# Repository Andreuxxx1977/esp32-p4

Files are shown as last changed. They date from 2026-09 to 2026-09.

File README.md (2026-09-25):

# ESP32-P4 "Extreme Performance" development board




An open-hardware, actively cooled ESP32-P4 board for heavy multimedia work: a 2-lane MIPI camera,
a 2-lane MIPI display, USB 2.0 High-Speed, 10/100 Ethernet, UHS-I microSD, 32 MB flash and
32 MB PSRAM. It uses a 4-layer HDI PCB, a 3 A 3.3 V rail, and a heatsink + PWM fan over the SoC.

> **Status: designed, routed, Gerbers generated; not fabricated yet.**
> Parts, pinout, netlist, BOM, docs, the placed board and the **routed KiCad 10 board with its
> Gerbers** are finished and machine-checked (KiCad DRC: fully connected, 0 manufacturing or
> electrical errors). Some high-speed rules (differential-pair coupling and length matching) are
> **not** met yet, and the board has **not** been fabricated or bench-tested.
> Check [Project status](#project-status) before ordering anything.

| Top | Bottom |
|---|---|
| Top of the board, rendered by KiCad 10 | Bottom of the board, rendered by KiCad 10 |

*Rendered by KiCad 10 in CI from the committed board on every push to `main` (published to the
[`renders`](https://github.com/Andreuxxx1977/esp32-p4/tree/renders) branch), the routed board once it is on `main`. The
RJ45 and FPC connectors have no model in KiCad's 3D library, so they show as footprints. The ESP32-P4
body is a representative 10 x 10 mm QFN (Espressif ships no 3D model).*

> **Resumen en español:** placa de desarrollo abierta con ESP32-P4, refrigeración activa, cámara y
> pantalla MIPI, USB-HS, Ethernet y microSD. Todos los archivos se generan desde un único modelo en
> Python. La placa está enrutada (con un enrutador propio) y tiene Gerbers; aún no se ha fabricado. Libre de usar citando este proyecto como original (ver [Licencia](#license-free-to-use-just-credit-the-original-project)).

## How this project was made: about 95 % by an AI agent

This board is an experiment in AI-driven hardware design. **Roughly 95 % of the work in this repository
was done by [Claude Code](https://claude.com/claude-code), Anthropic's AI coding agent**, working
from a written brief. It did the component research and part selection, the ESP32-P4 pin-mux
analysis, the Python data model, the SKiDL netlist, the KiCad placement script, its own PCB router, the BOM,
the documentation, the tests and the CI that checks all of it.

The remaining ~5 % is human, by the repository owner: writing the brief, making the decisions the
agent asked for (licence, double-sided assembly, adding a display connector), and reviewing and
merging every change.

What that means for you:

- **Everything that can be checked by a machine is checked**, on every commit, with the real KiCad
  tools (see [Verification](#verification-what-github-checks-on-every-commit)). Every part number and
  pinout has a source link in [`docs/component_verification.md`](docs/component_verification.md).
- **What a machine can't prove is listed as open**: datasheet fine print marked UNVERIFIED, signal
  integrity of the high-speed links, thermal behaviour, and whether the board works on the bench.
  No experienced hardware engineer has reviewed it yet, and it has not been fabricated.
- Treat it as a well-documented starting point, not a proven product. Reviews and bring-up reports
  are very welcome.

> **En español:** alrededor del **95 % de este proyecto lo ha hecho Claude Code**, el agente de
> programación con IA de Anthropic, a partir de un enunciado escrito: investigación y elección de
> componentes, pinout, netlist, colocación en KiCad, un enrutador de PCB propio, BOM, documentación, tests y CI. El
> ~5 % restante es humano: el enunciado, las decisiones que el agente pidió y la revisión y fusión de
> cada cambio. Todo lo comprobable automáticamente se comprueba en cada commit; lo que no (integridad
> de señal, térmica, funcionamiento real) está marcado como pendiente. Aún no se ha fabricado.

---

## Download the files

Everything is in this repository. Download all of it as a ZIP with
**[Download ZIP](https://github.com/Andreuxxx1977/esp32-p4/archive/refs/heads/main.zip)**, or open any
file below and use GitHub's "Download raw file" button.

| What you want | File | Notes |
|---|---|---|
| **Gerbers for the fab** (PCBWay or any other) | [`hardware/output/fab/esp32p4_extreme_gerbers.zip`](hardware/output/fab/esp32p4_extreme_gerbers.zip) | Gerber X2 + Excellon drills + Gerber job file. The same folder has the IPC-356 netlist, the pick-and-place file and the BOM. **Read [its README](hardware/output/fab/README.md) first**: 4-layer HDI 1+2+1, filled and capped vias in pads, and the high-speed rules that are not met yet. |
| **Routed PCB: KiCad 10 project** (open the `.kicad_pro`) | [`hardware/output/routed/esp32p4_extreme.kicad_pro`](hardware/output/routed/esp32p4_extreme.kicad_pro) + [`esp32p4_extreme.kicad_pcb`](hardware/output/routed/esp32p4_extreme.kicad_pcb) + [`esp32p4_extreme.kicad_dru`](hardware/output/routed/esp32p4_extreme.kicad_dru) | The board the Gerbers come from, routed by the project's own router ([`tools/pcb_router.py`](tools/pcb_router.py)). KiCad's DRC report is next to it ([`esp32p4_extreme.drc.json`](hardware/output/routed/esp32p4_extreme.drc.json)). Download the three files into one folder. |
| **Placed PCB: KiCad 10 project** | [`hardware/output/esp32p4_extreme.kicad_pro`](hardware/output/esp32p4_extreme.kicad_pro) + [`esp32p4_extreme.kicad_pcb`](hardware/output/esp32p4_extreme.kicad_pcb) + [`esp32p4_extreme.kicad_dru`](hardware/output/esp32p4_extreme.kicad_dru) | All parts placed, no copper yet (ratsnest only): the input of the router. Stack-up, net classes, diff pairs, zones, thermal vias, keep-outs and custom DRC rules are set up. Opens in KiCad 9 and 10. |
| **Netlist** (import into KiCad) | [`hardware/output/esp32p4_extreme.net`](hardware/output/esp32p4_extreme.net) | 231 parts, 175 nets, all footprints assigned. In KiCad: *PCB Editor -> File -> Import -> Netlist*. |
| **Bill of materials for PCBWay** | [`hardware/output/bom_pcbway.csv`](hardware/output/bom_pcbway.csv) and [`docs/TASK4_bom_pcbway.md`](docs/TASK4_bom_pcbway.md) | Turnkey format: designator, qty, value, package, MPN, manufacturer, LCSC #. |
| **Pinout / architecture** | [`docs/TASK1_pinout.md`](docs/TASK1_pinout.md) | All 55 GPIOs, dedicated pads, and a proof that the peripherals don't collide. |
| **Mechanical & thermal plan** | [`docs/TASK2_mechanical_thermal.md`](docs/TASK2_mechanical_thermal.md) | Heatsink/fan stack, thermal numbers, hole and connector coordinates. |
| **Why each part was chosen** | [`docs/component_verification.md`](docs/component_verification.md) | Evidence (distributor/datasheet links) for every MPN and pinout. |
| **Connection list** (spreadsheet) | [`hardware/output/esp32p4_extreme_nets.csv`](hardware/output/esp32p4_extreme_nets.csv) | One row per pad: net, net class, reference, pad. |

## What's on the board

| Block | Implementation |
|---|---|
| SoC | **ESP32-P4NRW32X**: dual-core RISC-V up to 400 MHz, chip rev v3.x, 32 MB PSRAM in-package |
| Flash | 32 MB Quad-SPI NOR, Winbond **W25Q256JVEIQ** (3.3 V) |
| Power | USB-C VBUS (any of 3 ports, Schottky OR-ed) -> **TPS62130** 3 A buck -> 3.3 V; **TLV62569** buck for the SoC core rail (`VDD_HP`), enabled and trimmed by the SoC itself |
| USB 1 (J1) | Native USB 2.0 **High-Speed** OTG (480 Mbit/s) on the SoC's dedicated PHY, **TPD2EUSB30** 0.7 pF ESD |
| USB 2 (J2) | Debug console: **CP2102N** USB-UART with automatic download/reset (DTR/RTS) |
| USB 3 (J3) | Native **USB-Serial-JTAG**: JTAG debugging + flashing with no drivers or setup |
| Ethernet | 10/100 RMII PHY **LAN8720A** + HanRun **HR911105A** RJ45 with magnetics |
| Camera | 2-lane MIPI CSI-2, 22-pin 0.5 mm FPC (**Raspberry Pi 5 pinout**; same Amphenol connector as the Pi) |
| Display | 2-lane MIPI DSI, same 22-pin FPC (J_DSI) + 5 V backlight JST-SH (J8), **plus** a 2x8 2.54 mm header (J9) for common SPI TFTs (ST7789 / ILI9341 / ST7735, with or without touch) |
| Storage | microSD on the UHS-I-capable SDMMC slot 0, 4-bit, 1.8/3.3 V switching, 0.5 pF TVS arrays |
| Cooling | 25 x 25 mm heatsink on the SoC, clamped through **4x M2.5 holes at (+/-15, +/-15) mm**; 5 V 4-wire PWM fan header; 7x7 filled thermal-via array under the SoC |
| Expansion | 2x12 2.54 mm header (J6): 20 GPIOs, LP-UART, ADC, pad-JTAG, I2C, 3V3/5V |
| Board | 110 x 80 mm, 4-layer HDI (1+2+1), 1.6 mm, controlled impedance 50 / 90 / 100 ohm |

```mermaid
flowchart LR
    subgraph Power
        VB["USB-C J1/J2/J3 VBUS"] --> OR["Schottky OR + PTC"] --> VSYS["VSYS 5 V"]
        VSYS --> BUCK["TPS62130 3 A"] --> V33["+3V3 plane"]
        V33 --> HP["TLV62569 VDD_HP"]
        VSYS --> FAN["Fan 5 V switch"]
    end
    subgraph SoC["ESP32-P4NRW32X (32 MB PSRAM)"]
        CORE["HP cores + peripherals"]
    end
    HP -. "EN_DCDC / FB_DCDC" .- CORE
    V33 --> CORE
    CORE -- "Quad SPI" --> FLASH["W25Q256 32 MB"]
    CORE -- "USB 2.0 HS" --> J1["USB-C J1"]
    CORE -- "UART0" --> CP["CP2102N"] --> J2["USB-C J2 debug"]
    CORE -- "USB-Serial-JTAG" --> J3["USB-C J3 JTAG"]
    CORE -- "RMII" --> PHY["LAN8720A"] --> RJ["RJ45"]
    CORE -- "MIPI CSI x2" --> CAM["Camera FPC"]
    CORE -- "MIPI DSI x2" --> DSI["Display FPC"]
    CORE -- "SPI + I2C" --> TFT["SPI TFT header J9"]
    CORE -- "SDMMC 4-bit" --> SD["microSD"]
    CORE -- "PWM / TACH" --> FANH["4-pin fan header"]
```

## Project status

| Step | State |
|---|---|
| Architecture, GPIO map, zero-conflict check | Done: [`docs/TASK1_pinout.md`](docs/TASK1_pinout.md) |
| Part selection with sourcing evidence | Done: [`docs/component_verification.md`](docs/component_verification.md) |
| Netlist (SKiDL), ERC 0 errors / 0 warnings, independent verification | Done |
| Every pad cross-checked against the real KiCad footprints | Done |
| PCBWay BOM | Done: 63 fitted lines, 219 placements (215 SMD + 4 THT); pick-and-place file generated by CI |
| Mechanical/thermal plan | Done: [`docs/TASK2_mechanical_thermal.md`](docs/TASK2_mechanical_thermal.md) |
| Component placement: pcbnew script + downloadable KiCad 10 project | Done: 234 footprints, KiCad 10 DRC 0 errors, **double-sided** (15 x 0402 decoupling under the SoC on the bottom); every SoC pad keeps a routable escape channel |
| Routing (own router), DRC in KiCad, Gerbers | Done as a prototype: every net routed on 4 layers, KiCad DRC with 0 unconnected items and 0 manufacturing/electrical errors, Gerbers + drills + IPC-356 + pick-and-place in [`hardware/output/fab/`](hardware/output/fab/) |
| Signal integrity of the routing | **Open**: several differential pairs are not coupled over their whole length and miss the 10 mil skew target; the list is in [the fab README](hardware/output/fab/README.md). Needs review before ordering |
| Fabrication, bring-up, firmware | Not started |

## Verification: what GitHub checks on every commit

Every push and pull request runs [`Design checks`](https://github.com/Andreuxxx1977/esp32-p4/actions/workflows/ci.yml)
(badge at the top). Nothing is merged unless it passes. The results are public in the **Actions** tab.

| CI job | What it proves |
|---|---|
| **Spec, netlist, docs and tests** | The design data passes its rules: no GPIO used twice, IO_MUX-only signals on legal pads, boot straps safe, heatsink/standoff keep-outs respected. The committed netlist matches the design pad by pad. A fresh SKiDL netlist passes ERC with 0 errors and 0 warnings. The docs and BOM are not stale. The 129 unit tests pass. |
| **Pads exist in the real KiCad footprints** | Every connected pad exists in the official KiCad **10.0.6** footprint library. |
| **KiCad 10 (pcbnew API, DRC, render, centroid)** | Runs the real KiCad 10 in its [official Docker image](https://hub.docker.com/r/kicad/kicad). It rebuilds the board from scratch with the pcbnew placement script. Both that board and the committed placed one must pass KiCad's DRC with 0 errors (unconnected items are expected there: they are not routed). It also renders the board in 3D with the parts' models and exports the PCBWay pick-and-place file. Download these under *Artifacts* on the run page. |
| **Routed board (DRC, same design as placed, Gerbers reproducible)** | The committed routed board has exactly the placed board's footprints, positions, pad nets and zones, plus copper. KiCad's DRC finds 0 unconnected items and 0 manufacturing or electrical errors; the high-speed rules it misses are listed, not hidden. A fresh export of the routed board gives the committed Gerbers, drills, IPC-356 and pick-and-place file line by line (time stamps aside). A separate manual workflow ([`route.yml`](.github/workflows/route.yml)) re-routes the board from the placed one. |

Open items to confirm against datasheets before ordering are listed at the end of
[`docs/component_verification.md`](docs/component_verification.md) (items marked UNVERIFIED).

## How the repository works

**One Python file describes the whole board**, and everything else is generated from it:

```
hardware/lib/board_spec.py       <- the design: parts, MPNs, footprints, every connection, placement
hardware/lib/esp32p4_pinout.py   <- ESP32-P4 pad table and IO_MUX rules (from Espressif sources)
hardware/lib/impedance.py        <- stack-up and 50/90/100 ohm trace geometry
        |
        +--> hardware/skidl/esp32p4_extreme_netlist.py  -> hardware/output/esp32p4_extreme.net (+ nets CSV, ERC log)
        +--> hardware/pcbnew/                            -> hardware/output/esp32p4_extreme.kicad_pro/.kicad_pcb/.kicad_dru
        +--> tools/gen_docs.py                           -> docs/TASK1_*.md, TASK2_*.md, TASK4_*.md, bom_pcbway.csv
        +--> hardware/pcbnew/preroute.py + tools/pcb_router.py -> hardware/output/routed/ (routed board)
        +--> tools/export_fab.py                         -> hardware/output/fab/ (Gerbers, drills, IPC-356, pick-and-place)
        +--> tests/                                      -> 129 automated tests
```

So the pinout table, the netlist and the BOM can never disagree. To change the board, edit
`board_spec.py` and regenerate (see [CONTRIBUTING.md](CONTRIBUTING.md)).

### Run the checks yourself

```bash
pip install --use-pep517 -r requirements.txt
python -m hardware.lib.board_spec                  # validate the design data
python -m hardware.skidl.esp32p4_extreme_netlist   # netlist + ERC  -> hardware/output/
python -m hardware.skidl.verify_netlist            # netlist == spec, pad by pad
python -m hardware.skidl.check_footprints          # pads exist in the real KiCad footprints (needs internet)
python -m tools.gen_docs                           # regenerate docs + BOM (--check to only verify)
python -m hardware.pcbnew.write_kicad_pcb          # regenerate the KiCad project (no KiCad needed)
python -m pytest -q
# with KiCad 10 installed (pcbnew Python), the same board through KiCad's own API:
python3 hardware/pcbnew/esp32p4_extreme_place.py --fp-dir /usr/share/kicad/footprints --out /tmp/board.kicad_pcb
# route the board again and export the Gerbers: CONTRIBUTING.md, "Routing and fabrication files"
```

GitHub Actions runs the same steps on every push and pull request (see [`.github/workflows/ci.yml`](.github/workflows/ci.yml)).
In the KiCad board, the design origin (the SoC centre, U1 = (0, 0)) is set as the grid and drill/place
origin. The board itself sits in the middle of the drawing sheet. To read design coordinates, set KiCad's
coordinate display to the grid origin. The pick-and-place export (`--use-drill-file-origin`) reports
U1 at exactly (0, 0).
The project targets **KiCad 10** and its standard libraries (checked against tag 10.0.6). KiCad 9.0.x
names two shield pads differently: USB-C `S1` and microSD `11` instead of `SH`. The netlist opens there
too, but those shield pads won't connect if you re-import footprints from a 9.0 library. The SoC
footprint comes from [Espressif's KiCad library](https://github.com/espressif/kicad-libraries)
(`PCM_Espressif:ESP32-P4`).

## Design decisions that differ from a "typical" P4 board

All of these come from Espressif's primary sources: the ESP-IDF `soc_caps.h`/`*_pins.h`/`emac_periph.c`
files, the ESP32-P4 hardware design guidelines and Espressif's KiCad library.

| Asked for | Built | Why |
|---|---|---|
| ESP32-P4NR32 | **ESP32-P4NRW32X** (rev v3.x, 32 MB PSRAM) | The orderable 32 MB-PSRAM part. Espressif marks rev v1.x as not recommended for new designs. |
| 32 MB **Octal** flash (MX25UM25645G) | 32 MB **Quad** W25Q256JVEIQ (3.3 V) | The P4 flash interface is SPI/Dual/Quad only, up to 64 MB. ESP-IDF has no octal-flash capability for the P4. MX25UM is also 1.8 V, while the P4 flash rail defaults to 3.3 V. |
| MP2315 / SY8113B buck | **TPS62130** (3-17 V, 3 A, 100 % duty) | Works from Schottky-OR-ed VBUS (~4.4-4.6 V), below the MP2315's 4.5 V minimum. The exposed pad is also better thermally at 3 A. |
| (not asked) | **TLV62569** VDD_HP DCDC | The P4 core rail must come from an external DCDC that the SoC enables and trims itself. TLV62569 is on Espressif's verified list. |
| RTL8201F | **LAN8720A** | Pinout verified from the official KiCad library, ESP-IDF `lan87xx` driver. Its REF_CLK-out mode feeds the P4's input-only RMII clock. |
| CH340K / CP2102N "UART/JTAG" | **CP2102N** (UART) **plus** a 3rd USB-C on the P4's native USB-Serial-JTAG | Neither chip can do JTAG. The P4's built-in USB-Serial-JTAG gives JTAG with no setup. |
| USBLC6-2SC6 on USB-HS | **TPD2EUSB30** on J1 (USBLC6 kept on J2/J3) | USBLC6 is 3.5 pF max. Espressif requires at most 1 pF on the High-Speed lines. |
| AO3400A fan MOSFET | AO3400A as **open-drain PWM** + AO3401A high-side switch | A 4-wire fan needs constant power and an open-drain PWM input (Intel spec). The fan runs at 100 % if the firmware hangs, and can be switched off completely. |

## Contributing

Issues and pull requests are welcome. Reviews of the schematic choices and of the routing (above all the high-speed pairs) and bring-up
reports are the most useful right now. Read [CONTRIBUTING.md](CONTRIBUTING.md) first: in short,
edit `hardware/lib/board_spec.py`, regenerate, and commit the generated files with it.

## License: free to use, just credit the original project

Copyright (c) 2026 Andreuxxx1977. Licensed under the **CERN Open Hardware Licence v2 - Permissive**
(SPDX: `CERN-OHL-P-2.0`). The full text is in [`LICENSE`](LICENSE).

In plain words: **anyone is free to use, copy, modify, fabricate, sell and build on this design,
commercially or not.** The only thing asked in return is that you **credit this project as the
original**, for example with a link in your README, documentation or product page:

> Based on the ESP32-P4 Extreme Performance board by Andreuxxx1977 -
> https://github.com/Andreuxxx1977/esp32-p4

You don't have to publish your own changes, and you don't have to use the same licence for your
derivative. That attribution line is the licence's "Notice", so keep it (CERN-OHL-P v2 section 3.2).
If you modify the design, add a short note saying so (section 3.3).

Why so permissive? About 95 % of this design was produced by an AI agent (Claude Code, see
[How this project was made](#how-this-project-was-made-about-95--by-an-ai-agent)). There's little personal
merit to protect, so the goal is simply that it's useful to as many people as possible.

**Libre de usar:** cualquiera puede usar, modificar, fabricar y vender este diseño. Lo único que se pide
es mencionar que el proyecto original es https://github.com/Andreuxxx1977/esp32-p4.

This source is distributed WITHOUT ANY EXPRESS OR IMPLIED WARRANTY, INCLUDING OF MERCHANTABILITY,
SATISFACTORY QUALITY AND FITNESS FOR A PARTICULAR PURPOSE. Please see the CERN-OHL-P v2 for applicable
conditions. The board has not been fabricated or bench-tested yet. Treat it as a reviewed starting point
and check it against the datasheets before ordering (see `docs/component_verification.md`).

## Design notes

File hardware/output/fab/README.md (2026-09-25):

# ESP32-P4 Extreme -- fabrication package

> **Prototype files, routed by the project's own router (`tools/pcb_router.py`).**
> **Not fabricated or bench-tested yet.**
> The copper is fully connected and passes KiCad's DRC for manufacturing and electrical
> rules (0 errors).
> Some high-speed rules listed at the end are **not** met (coupling, gap or length
> matching of some differential pairs / length groups). Review those nets before
> ordering: they can limit USB 2.0 High-Speed, MIPI CSI/DSI or Ethernet margins.

## Files

- `esp32p4_extreme_gerbers.zip`: Gerber X2 (Protel extensions) + Excellon drills (PTH and NPTH separate) + drill maps + Gerber job file. Upload this to PCBWay.
- `esp32p4_extreme.ipc`: IPC-D-356 netlist for the fab's electrical test.
- `pick_and_place.csv`: centroids, both sides, origin = SoC centre (same as the Gerbers).
- `bom_pcbway.csv`: turnkey BOM (MPN, manufacturer, LCSC).
- Source: `hardware/output/routed/esp32p4_extreme.kicad_pcb` (KiCad 10).

## Board

- 110 x 80 mm, 1.6 mm, 4 layers, 234 footprints, 3223 track segments.
- Stack-up (1+2+1 HDI, controlled impedance 50 / 90 / 100 ohm, ask PCBWay to confirm widths):

  | Layer | Thickness | Material | Function |
  |---|---|---|---|
  | F.Cu | 0.035 mm | Cu 0.5 oz + plating | Signal_Top (HS routing, refs L2 GND) |
  | PP1 | 0.1 mm | Prepreg 1080 (laser-drillable) | Er 4 |
  | In1.Cu | 0.035 mm | Cu 1 oz | GND (solid, un-split reference plane) |
  | Core | 1.26 mm | FR-4 core, Tg170 | Er 4.4 |
  | In2.Cu | 0.035 mm | Cu 1 oz | VCC_3V3 plane (+VDD_HP island under U1) |
  | PP2 | 0.1 mm | Prepreg 1080 (laser-drillable) | Er 4 |
  | B.Cu | 0.035 mm | Cu 0.5 oz + plating | Signal_Bottom (low-speed, heat-spreader pour) |

- Vias: 230 x micro 0.3/0.1 mm, 688 x through 0.45/0.2 mm, 49 x through 0.6/0.3 mm.
  Laser microvias L1-L2 (to the GND plane) and L4-L3 (to the power planes) need an HDI
  1+2+1 build. Every via inside a pad (the EPAD array and the plane vias of the 0402 pads)
  must be **filled and capped** (IPC-4761 Type VII, "via in pad" / VIPPO).
- Minimum track 0.1 mm (0.09 mm only in the SoC fan-out, inside U1's courtyard), minimum clearance 0.09 mm there, 0.10 mm elsewhere.
- Surface finish ENIG (0.35 mm-pitch QFN), green mask, white silkscreen.

## Design-rule check (KiCad 10)

- Unconnected items: 0; manufacturing/electrical errors: 0.
- High-speed rules **not met**:

  - diff_pair_gap_out_of_range: CAM_D1_N, CAM_D1_P (2x)
  - diff_pair_gap_out_of_range: CSI_D1_N, CSI_D1_P (6x)
  - diff_pair_gap_out_of_range: DISP_CLK_N, DISP_CLK_P (2x)
  - diff_pair_gap_out_of_range: DISP_D0_N, DISP_D0_P (10x)
  - diff_pair_gap_out_of_range: DISP_D1_N, DISP_D1_P (22x)
  - diff_pair_gap_out_of_range: ETH_TX_N, ETH_TX_P (10x)
  - diff_pair_gap_out_of_range: USB1_D_N, USB1_D_P (44x)
  - diff_pair_gap_out_of_range: USB2_D_N, USB2_D_P (28x)
  - diff_pair_gap_out_of_range: USB3_D_N, USB3_D_P (71x)
  - diff_pair_gap_out_of_range: USBHS_D_N, USBHS_D_P (4x)
  - diff_pair_uncoupled_length_too_long: CAM_CLK_N, CAM_CLK_P (1x)
  - diff_pair_uncoupled_length_too_long: CAM_D0_N, CAM_D0_P (1x)
  - diff_pair_uncoupled_length_too_long: CAM_D1_N, CAM_D1_P (1x)
  - diff_pair_uncoupled_length_too_long: CSI_CLK_N, CSI_CLK_P (1x)
  - diff_pair_uncoupled_length_too_long: CSI_D0_N, CSI_D0_P (1x)
  - diff_pair_uncoupled_length_too_long: CSI_D1_N, CSI_D1_P (1x)
  - diff_pair_uncoupled_length_too_long: DISP_CLK_N, DISP_CLK_P (1x)
  - diff_pair_uncoupled_length_too_long: DISP_D0_N, DISP_D0_P (1x)
  - diff_pair_uncoupled_length_too_long: DISP_D1_N, DISP_D1_P (1x)
  - diff_pair_uncoupled_length_too_long: DSI_CLK_N, DSI_CLK_P (1x)
  - diff_pair_uncoupled_length_too_long: DSI_D0_N, DSI_D0_P (1x)
  - diff_pair_uncoupled_length_too_long: DSI_D1_N, DSI_D1_P (1x)
  - diff_pair_uncoupled_length_too_long: ETH_RX_N, ETH_RX_P (1x)
  - diff_pair_uncoupled_length_too_long: ETH_TX_N, ETH_TX_P (1x)
  - diff_pair_uncoupled_length_too_long: USB1_D_N, USB1_D_P (1x)
  - diff_pair_uncoupled_length_too_long: USB2_D_N, USB2_D_P (1x)
  - diff_pair_uncoupled_length_too_long: USB3_D_N, USB3_D_P (1x)
  - diff_pair_uncoupled_length_too_long: USBHS_D_N, USBHS_D_P (1x)
  - skew_out_of_range: CAM_CLK_N (1x)
  - skew_out_of_range: CAM_D0_N (1x)
  - skew_out_of_range: CAM_D0_P (1x)
  - skew_out_of_range: CAM_D1_N (1x)
  - skew_out_of_range: CAM_D1_P (1x)
  - skew_out_of_range: CSI_CLK_N (1x)
  - skew_out_of_range: CSI_CLK_P (1x)
  - skew_out_of_range: CSI_D0_N (1x)
  - skew_out_of_range: CSI_D0_P (1x)
  - skew_out_of_range: CSI_D1_P (1x)
  - skew_out_of_range: DISP_CLK_N (1x)
  - skew_out_of_range: DISP_CLK_P (1x)
  - skew_out_of_range: DISP_D0_N (1x)
  - skew_out_of_range: DISP_D1_N (1x)
  - skew_out_of_range: DISP_D1_P (1x)
  - skew_out_of_range: DSI_CLK_P (1x)
  - skew_out_of_range: DSI_D0_N (1x)
  - skew_out_of_range: DSI_D0_P (1x)
  - skew_out_of_range: DSI_D1_N (1x)
  - skew_out_of_range: DSI_D1_P (1x)
  - skew_out_of_range: ETH_RX_N (1x)
  - skew_out_of_range: ETH_TX_P (1x)
  - skew_out_of_range: SD_CLK_C (1x)
  - skew_out_of_range: SD_CMD (1x)
  - skew_out_of_range: SD_CMD_C (1x)
  - skew_out_of_range: SD_D0 (1x)
  - skew_out_of_range: SD_D0_C (1x)
  - skew_out_of_range: SD_D1 (1x)
  - skew_out_of_range: SD_D1_C (1x)
  - skew_out_of_range: SD_D2 (1x)
  - skew_out_of_range: SD_D3 (1x)
  - skew_out_of_range: USB2_D_P (1x)
  - skew_out_of_range: USB3_D_P (1x)
  - skew_out_of_range: USBHS_D_N (1x)

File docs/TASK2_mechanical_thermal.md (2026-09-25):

<!-- GENERATED by tools/gen_docs.py from hardware/lib/*.py -- do not edit by hand. Regenerate: python3 -m tools.gen_docs -->

# TASK 2: Mechanical & thermal strategy

All coordinates, dimensions and part data are read from `hardware/lib/board_spec.py` at generation time. Thermal values are estimates with every assumption listed next to its result.

## 1. Heat paths

| Path | Stack | Key numbers (from the spec) |
| --- | --- | --- |
| (a) Top | SoC mould top -> 0.1 mm phase-change pad (e.g. Laird Tpcm 580) -- flush on SoC lid -> 25 x 25 x 10 mm heatsink (Al 6063-T5, black anodised) -> 5 V PWM fan (impinging, radial exhaust over the board) | SoC seated height 0.90 mm; tallest part allowed in the keep-out 0.60 mm (rule) / 0.55 mm (actual, 86 x 0402 passives around U1) -> air gap under the heatsink base >= 0.35 mm (0.30 mm by rule), 0.45 mm with the uncompressed TIM |
| (b) Bottom | EPAD 7.5 mm -> 7x7 vias 0.30/0.60 mm @ 1.0 mm (VIPPO) -> L2 GND plane + 14 x 14 mm B.Cu spreader (6.6 x 6.6 mm exposed window) -> optional bottom gap pad / chassis | array extent 6.6 mm inside the 7.5 mm EPAD; fill: IPC-4761 Type VII (resin-filled + copper-capped, VIPPO) |

The heatsink sits flush on the SoC lid: nothing inside the 25 x 25 mm keep-out is taller than 0.55 mm, so the base clears every 0402 by >= 0.35 mm. Black anodising is not a guaranteed insulator -- the gap is the insulation, and the 4-point spring clamp keeps the base parallel to the board.

Assembly is double-sided: 15 decoupling caps (C10, C11, C13, C14, C20, C21, C23, C25, C26, C27, C28, C29, C31, C32, C33) sit on the bottom under the SoC's pad ring, outside the thermal-via field. So only the via field is left mask-free (6.6 x 6.6 mm, `BOTTOM_THERMAL_WINDOW_MM`); the rest of the 14 x 14 mm spreader copper (`BOTTOM_SPREADER_MM`) is under solder mask. A bottom gap pad or bracket must clear those 0402s (<= 0.55 mm) or be cut to the window.

### 1.1 Via-array thermal resistance

```text
barrel area  A = pi/4 * (d^2 - (d - 2t)^2) = pi/4 * (0.300^2 - 0.250^2) = 0.02160 mm^2
one via      R = L / (k * A) = 1.60e-3 m / (385 W/m.K * 0.02160e-6 m^2) = 192.4 K/W
array        R = 192.4 / 49 = 3.93 K/W   (plating t = 25 um, L = board thickness)
L1 -> L2 only (0.135 mm of the 1.60 mm): 0.33 K/W  (heat reaches the GND plane almost for free)
solid-copper-filled vias would give 1.20 K/W (resin fill k ~0.3-1 W/m.K adds nothing)
```

Constriction in the planes, voids under the EPAD and the resin fill are ignored, so treat 3.9 K/W as the via contribution only.

EPAD tile alignment (computed): 25 of 49 via pads fall fully inside one of the 2.1 mm EPAD tiles (2.7 mm pitch); the other 24 straddle the 0.6 mm inter-tile gaps. If the footprint copper is tiled (not one solid pad), either merge the F.Cu to a solid 7.5 mm pad (paste stays tiled) or move the array onto the tile pitch.

## 2. Power estimate

Espressif does not publish a theta-JC, theta-JB or maximum package dissipation for the ESP32-P4 in the documents used for this design (datasheet, hardware design guidelines, KiCad library). Every power and package number below is an **engineering estimate** to be replaced by a measurement on the first build (VBUS power with peripherals off vs. full load, IR camera / thermocouple on the lid).

| Contributor | Low (W) | High (W) | Assumption |
| --- | ---: | ---: | --- |
| VDD_HP domain: 2x RISC-V @ 400 MHz, L2MEM, ISP / H.264 / PPA / 2D-DMA | 0.35 | 0.90 | assumed 0.3-0.75 A on the VDD_HP rail |
| In-package 32 MB PSRAM + flash IO via on-chip LDOs (LDO drop dissipated in the package) | 0.10 | 0.35 | assumed 30-100 mA from 3.3 V |
| MIPI DSI + CSI D-PHY, USB 2.0 HS PHY, analog, IO ring | 0.10 | 0.30 | assumed 30-90 mA from 3.3 V |
| **SoC total (estimate)** | **0.55** | **1.55** |  |
| Thermal design point |  | **2.0** | estimate + margin for unknowns |
| Hard ceiling (not expected) |  | 3.05 | U4 TLV62569 rated 2.0 A x 1.20 V = 2.40 W on VDD_HP + 0.65 W 3.3 V-side high estimate |

## 3. Thermal network (estimate)

| Element | Value | Basis |
| --- | ---: | --- |
| theta-JC top (die -> mould top) | 12.0 K/W | estimate for a 10 x 10 mm QFN mould cap |
| theta-JC bottom (die -> EPAD) | 2.0 K/W | estimate (exposed-pad QFN) |
| TIM | 0.33 K/W | 0.10 mm / (3.0 W/m.K x 100 mm^2 lid) |
| EPAD solder | 0.026 K/W | 50 um SAC, 60% coverage |
| Via array | 3.93 K/W | section 1.1 |
| Heatsink theta-SA, fan | 6.7 K/W | 6x6 pins 2.0 mm, 8 mm tall -> A = 2929 mm^2; h = 60 W/m^2.K, eta = 0.85 |
| Heatsink theta-SA, natural | 29.9 K/W | h = 12 W/m^2.K, eta = 0.95 |
| Board -> air, fan exhaust | 10.2 K/W | 2 x board area, 30% effective, top h = 25 |
| Board -> air, natural | 15.8 K/W | h = 12 W/m^2.K |
| Optional gap pad to chassis | 7.65 K/W + chassis | 1.0 mm, 3.0 W/m.K on the 6.6 mm exposed window |

| Scenario | R top (K/W) | R bottom (K/W) | R j-a (K/W) | Share via EPAD | dT j-a @ 1.55 W | dT j-a @ 2.0 W | Tj @ 2.0 W, Ta 40 C | dT across vias @ 2.0 W |
| --- | ---: | ---: | ---: | ---: | ---: | ---: | ---: | ---: |
| Heatsink + fan (normal) | 19.0 | 16.2 | 8.7 | 54% | 13.6 K | 17.5 K | 57 C | 4.2 K |
| Heatsink, fan stopped / zero-RPM | 42.3 | 21.7 | 14.4 | 66% | 22.3 K | 28.7 K | 69 C | 5.2 K |
| No heatsink, natural convection | 845.3 | 21.7 | 21.2 | 97% | 32.8 K | 42.4 K | 82 C | 7.7 K |

Reading: with only the via array and the board (no heatsink) the SoC would run roughly 42 K above ambient at the 2.0 W design point; the heatsink + fan cut that to ~17 K and the via array still carries about 54% of the heat. The temperature drop across the via array itself is only ~4.2 K. With theta-JC(top) at a pessimistic 20 K/W the fan-on R j-a becomes 10.1 K/W.

### 3.1 Heatsink and fan selection

| Choice | Rationale |
| --- | --- |
| Base = keep-out | 25 x 25 mm base covers the 25 x 25 mm keep-out exactly; everything under it is <= 0.55 mm |
| Height | 10 mm keeps the fan top low; the fan shadow is the fan footprint (up to 30 mm square, see section 6) |
| Pin fins | an impinging fan exhausts radially only through pin (or cross-cut) fins; plate fins would dump all flow along two sides |
| Fan | 25 x 25 x 10 mm or 30 x 30 x 7 mm, 5 V, 4-wire PWM, screwed to fin top; 5 V from VSYS through the high-side switch; typically 0.3-0.6 W for this size (check the fan datasheet) |
| Clamp | 4 x M2.5 spring-loaded screws through H1-H4 into a 30 x 30 mm X-bracket; plated holes tied to GND bond the heatsink to ground |
| Margin | theta-SA falls from ~30 to ~7 K/W with the fan (estimate; use the vendor theta-vs-airflow curve for the final part) |

## 4. Mechanical coordinates

Design origin = U1 body centre; KiCad axes (+X right, +Y down); mm. Part coordinates are the footprint origin (for pin headers that is pin 1, not the body centre).

| Feature | Coordinates | Size / notes |
| --- | --- | --- |
| Board outline | (-55.0, -40.0) .. (55.0, 40.0) | 110 x 80 mm, R3.0 corners |
| Heatsink keep-out | (-12.5, -12.5), (12.5, -12.5), (-12.5, 12.5), (12.5, 12.5) | 25 x 25 mm, max part height 0.60 mm |
| H1 (heatsink, M2.5) | (-15.0, -15.0) | keep-out radius 3.5 mm |
| H2 (heatsink, M2.5) | (15.0, -15.0) | keep-out radius 3.5 mm |
| H3 (heatsink, M2.5) | (-15.0, 15.0) | keep-out radius 3.5 mm |
| H4 (heatsink, M2.5) | (15.0, 15.0) | keep-out radius 3.5 mm |
| H5 (board, M3) | (-51.0, -36.0) | Board mounting hole (GND) |
| H6 (board, M3) | (51.0, -36.0) | Board mounting hole (GND) |
| H7 (board, M3) | (-51.0, 36.0) | Board mounting hole (GND) |
| H8 (board, M3) | (51.0, 36.0) | Board mounting hole (GND) |
| FID1 | (-52.1, 31.4) | fiducial |
| FID2 | (52.0, 28.0) | fiducial |
| FID3 | (47.0, -24.0) | fiducial |

### 4.1 Every absolutely placed part

| Ref | Value | x, y | Rot | Height (mm) | Clearance to keep-out (mm) | Nearest M2.5 hole (mm) | Board-edge dist (mm) | Hole check |
| --- | --- | ---: | ---: | ---: | ---: | --- | --- | --- |
| C55 | 47uF | (-14.5, -8.0) | 90 | 1.45 | 2.0 | H1 7.0 | 32.0 | OK |
| C56 | 47uF | (14.5, 8.0) | 90 | 1.45 | 2.0 | H4 7.0 | 32.0 | OK |
| D1 | PMEG4050EP | (22.0, 28.5) | 0 | 1.10 | 18.6 | H4 15.2 | 11.5 | OK |
| D2 | PMEG4050EP | (-42.0, 25.0) | 0 | 1.10 | 32.0 | H3 28.8 | 13.0 | OK |
| D3 | PMEG4050EP | (-42.0, 11.0) | 0 | 1.10 | 29.5 | H3 27.3 | 13.0 | OK |
| D4 | Green | (-43.0, -30.0) | 0 | 0.80 | 35.2 | H1 31.8 | 10.0 | OK |
| D5 | Red | (-43.0, -27.0) | 0 | 0.80 | 33.8 | H1 30.5 | 12.0 | OK |
| F1 | PTC 2.5A | (-34.0, 27.0) | 0 | 1.10 | 25.9 | H3 22.5 | 13.0 | OK |
| J1 | USB-C | (22.0, 36.0) | 0 | 3.31 | 25.3 | H4 22.1 | bottom: 4.0 | OK |
| J2 | USB-C | (-51.0, 22.0) | 0 | 3.31 | 39.7 | H3 36.7 | left: 4.0 | OK |
| J3 | USB-C | (-51.0, 8.0) | 0 | 3.31 | 38.5 | H3 36.7 | left: 4.0 | OK |
| J4 | RJ45 MagJack | (37.2, 3.0) | 0 | 13.30 | 24.7 | H4 25.3 | right: 17.8 | OK |
| J5 | microSD | (6.0, -31.0) | 0 | 1.98 | 18.5 | H2 18.4 | top: 9.0 | OK |
| J6 | 2x12 header | (-50.5, -27.1) | 0 | 8.50 | 40.7 | H1 37.5 | 4.5 | OK |
| J7 | Fan 4P | (-30.0, -30.0) | 0 | 11.40 | 24.7 | H1 21.2 | 10.0 | OK |
| J8 | JST-SH 2P | (-28.0, 36.5) | 0 | 2.95 | 28.6 | H3 25.1 | bottom: 3.5 | OK |
| J9 | 2x8 header | (24.0, -35.0) | 90 | 8.50 | 25.3 | H2 21.9 | 5.0 | OK |
| J_CAM | FPC 22P 0.5mm | (6.0, 35.0) | 0 | 2.00 | 22.5 | H4 21.9 | bottom: 5.0 | OK |
| J_DSI | FPC 22P 0.5mm | (-14.0, 35.0) | 0 | 2.00 | 22.5 | H3 20.0 | bottom: 5.0 | OK |
| L1 | 2.2uH | (-27.0, 20.0) | 0 | 3.10 | 16.3 | H3 13.0 | 20.0 | OK |
| L2 | 2.2uH | (20.6, -8.5) | 0 | 1.20 | 8.1 | H2 8.5 | 31.5 | OK |
| SW1 | Tactile | (-40.0, -35.0) | 0 | 2.50 | 35.5 | H1 32.0 | 5.0 | OK |
| SW2 | Tactile | (-33.0, -35.1) | 0 | 2.50 | 30.5 | H1 27.0 | 4.9 | OK |
| U2 | W25Q256JV 32MB | (-20.0, 5.0) | 90 | 0.80 | 7.5 | H3 11.2 | 35.0 | OK |
| U3 | TPS62130 | (-34.0, 18.0) | 0 | 1.00 | 22.2 | H3 19.2 | 21.0 | OK |
| U4 | TLV62569 | (16.5, -7.5) | 0 | 1.45 | 4.0 | H2 7.6 | 32.5 | OK |
| U5 | LAN8720A | (22.0, 3.0) | 0 | 0.90 | 9.5 | H4 13.9 | 33.0 | OK |
| U6 | CP2102N | (-39.5, 19.0) | 0 | 0.90 | 27.8 | H3 24.9 | 15.5 | OK |
| Y1 | 40MHz 10ppm | (-3.5, -15.0) | 0 | 0.50 | 2.5 | H1 11.5 | 25.0 | OK |
| Y2 | 25MHz | (22.0, 9.5) | 0 | 0.80 | 9.5 | H4 8.9 | 30.5 | OK |

## 5. Collision check (M2.5 heatsink holes)

Flag thresholds: a part origin closer than 3.5 mm (`HEATSINK_HOLE_KEEPOUT_R`) to a hole centre is a **FAIL**; a high-speed corridor closer than 4.5 mm (keep-out + 1 mm) is flagged. HS corridors are approximated as the straight segment from the centroid of the SoC pad group (`pad_position`) to the connector / device placement.

### 5.1 Summary per hole

| Hole | x, y | (i) to keep-out (mm) | (ii) nearest connector (mm) | nearest placed part (mm) | (iii) nearest HS corridor (mm) | Status |
| --- | --- | ---: | --- | --- | --- | --- |
| H1 | (-15.0, -15.0) | 3.54 | J7 21.2 | C55 7.0 | SoC crystal 11.5 | OK |
| H2 | (15.0, -15.0) | 3.54 | J5 18.4 | U4 7.6 | SDIO (SDMMC slot 0) 10.7 | OK |
| H3 | (-15.0, 15.0) | 3.54 | J_DSI 20.0 | U2 11.2 | MIPI DSI 9.0 | OK |
| H4 | (15.0, 15.0) | 3.54 | J_CAM 21.9 | C56 7.0 | MIPI CSI 11.7 | OK |

(i) The hole keep-out circle (r = 3.5 mm) clears the keep-out corner by 0.04 mm.

### 5.2 (ii) Hole centre -> connector placement (mm)

| Connector | Value | x, y | Height | H1 | H2 | H3 | H4 |
| --- | --- | --- | ---: | ---: | ---: | ---: | ---: |
| J1 | USB-C | (22.0, 36.0) | 3.3 | 63.0 | 51.5 | 42.5 | 22.1 |
| J2 | USB-C | (-51.0, 22.0) | 3.3 | 51.6 | 75.7 | 36.7 | 66.4 |
| J3 | USB-C | (-51.0, 8.0) | 3.3 | 42.7 | 69.9 | 36.7 | 66.4 |
| J4 | RJ45 MagJack | (37.2, 3.0) | 13.3 | 55.3 | 28.6 | 53.6 | 25.3 |
| J5 | microSD | (6.0, -31.0) | 2.0 | 26.4 | 18.4 | 50.6 | 46.9 |
| J6 | 2x12 header | (-50.5, -27.1) | 8.5 | 37.5 | 66.6 | 55.1 | 77.9 |
| J7 | Fan 4P | (-30.0, -30.0) | 11.4 | 21.2 | 47.4 | 47.4 | 63.6 |
| J8 | JST-SH 2P | (-28.0, 36.5) | 3.0 | 53.1 | 67.1 | 25.1 | 48.1 |
| J9 | 2x8 header | (24.0, -35.0) | 8.5 | 43.8 | 21.9 | 63.4 | 50.8 |
| J_CAM | FPC 22P 0.5mm | (6.0, 35.0) | 2.0 | 54.2 | 50.8 | 29.0 | 21.9 |
| J_DSI | FPC 22P 0.5mm | (-14.0, 35.0) | 2.0 | 50.0 | 57.8 | 20.0 | 35.2 |

### 5.3 (iii) Hole centre -> straight-line HS corridor (mm)

| Interface | From | Start | To | Length | H1 | H2 | H3 | H4 | Status |
| --- | --- | --- | --- | ---: | ---: | ---: | ---: | ---: | --- |
| MIPI DSI | U1 pads 35-40 | (-0.7, 4.9) | J_DSI (-14.0, 35.0) | 32.9 | 24.5 | 25.3 | 9.0 | 18.5 | OK |
| MIPI CSI | U1 pads 42-47 | (1.7, 4.9) | J_CAM (6.0, 35.0) | 30.4 | 26.0 | 23.9 | 18.0 | 11.7 | OK |
| SDIO (SDMMC slot 0) | U1 pads 80-84, 86 | (3.1, -4.9) | J5 (6.0, -31.0) | 26.3 | 19.1 | 10.7 | 26.9 | 23.2 | OK |
| RMII | U1 pads 57-58, 60, 65-66, 92-93 | (3.4, -0.3) | U5 (22.0, 3.0) | 18.9 | 23.5 | 16.5 | 23.9 | 13.0 | OK |
| QSPI flash | U1 pads 27-29, 31-33 | (-3.3, 4.9) | U2 (-20.0, 5.0) | 16.7 | 20.0 | 27.0 | 10.0 | 20.9 | OK |
| SoC crystal | U1 pads 99-100 | (-2.8, -4.9) | Y1 (-3.5, -15.0) | 10.1 | 11.5 | 18.5 | 23.3 | 26.7 | OK |
| Ethernet MDI (PHY -> RJ45) | U5 | (22.0, 3.0) | J4 (37.2, 3.0) | 15.2 | 41.1 | 19.3 | 38.9 | 13.9 | OK |

### 5.4 Other parts vs the hole keep-out

No absolutely placed part within the flag distance.

Relatively placed parts (`Near`) whose worst-case position (anchor distance minus the allowed `max_mm`) can reach a hole keep-out -- constrain these in the placer:

None.

### 5.5 Board holes and fiducials vs the nearest part origin

Assumed clear radius: M3 washer 3.5 mm (+1 mm margin); fiducial 3.0 mm (1 mm copper dot + mask opening + camera margin).

| Feature | x, y | Nearest part origin (mm) | Status |
| --- | --- | --- | --- |
| H5 | (-51.0, -36.0) | J6 8.9 | OK |
| H6 | (51.0, -36.0) | J9 27.0 | OK |
| H7 | (-51.0, 36.0) | J2 14.0 | OK |
| H8 | (51.0, 36.0) | J1 29.0 | OK |
| FID1 | (-52.1, 31.4) | J2 9.5 | OK |
| FID2 | (52.0, 28.0) | J4 29.0 | OK |
| FID3 | (47.0, -24.0) | J9 25.5 | OK |

## 6. Airflow

The fan blows down into the pin fins; air leaves the fin field radially at board level and sweeps the top copper. Rules applied: parts taller than half the heatsink height (5.0 mm) stay outside the fan shadow (largest fan option, +/-15.0 mm); heat sources should sit in the near exhaust (<= 15 mm from the keep-out edge) or far exhaust (<= 30 mm). Zones are geometric estimates, not CFD.

| Ref | Value | Role | Height | x, y | Direction | Clearance to keep-out | In fan shadow | Verdict |
| --- | --- | --- | ---: | --- | --- | ---: | --- | --- |
| D1 | PMEG4050EP | heat source | 1.10 | (22.0, 28.5) | bottom-right | 18.6 | no | far exhaust |
| D2 | PMEG4050EP | heat source | 1.10 | (-42.0, 25.0) | bottom-left | 32.0 | no | outside |
| D3 | PMEG4050EP | heat source | 1.10 | (-42.0, 11.0) | left | 29.5 | no | far exhaust |
| J4 | RJ45 MagJack | tall | 13.30 | (37.2, 3.0) | right | 24.7 | no | OK |
| J6 | 2x12 header | tall | 8.50 | (-50.5, -27.1) | top-left | 40.7 | no | OK |
| J7 | Fan 4P | tall | 11.40 | (-30.0, -30.0) | top-left | 24.7 | no | OK |
| J9 | 2x8 header | tall | 8.50 | (24.0, -35.0) | top-right | 25.3 | no | OK |
| L1 | 2.2uH | heat source | 3.10 | (-27.0, 20.0) | bottom-left | 16.3 | no | far exhaust |
| L2 | 2.2uH | heat source | 1.20 | (20.6, -8.5) | right | 8.1 | no | near exhaust |
| U2 | W25Q256JV 32MB | heat source | 0.80 | (-20.0, 5.0) | left | 7.5 | no | near exhaust |
| U3 | TPS62130 | heat source | 1.00 | (-34.0, 18.0) | bottom-left | 22.2 | no | far exhaust |
| U4 | TLV62569 | heat source | 1.45 | (16.5, -7.5) | top-right | 4.0 | no | near exhaust |
| U5 | LAN8720A | heat source | 0.90 | (22.0, 3.0) | right | 9.5 | no | near exhaust |
| U6 | CP2102N | heat source | 0.90 | (-39.5, 19.0) | bottom-left | 27.8 | no | far exhaust |

## 7. Fan control

J7 Intel 4-wire PWM fan header (1 GND, 2 +V, 3 TACH, 4 PWM). Intel 4-wire PWM fan spec: 25 kHz nominal (21-28 kHz), the PWM input is driven open-collector/open-drain against the fan's internal pull-up, an open or high input means full speed, tach is open-collector with 2 pulses per revolution.

| Function | Parts (netlist) | Signal path | Reset / fail-safe |
| --- | --- | --- | --- |
| PWM (open drain) | Q3 AO3400A; gate R86 100; pull-down R87 100k; optional pull-up R88 10k (DNP) | GPIO9 `FAN_PWM` -> J7.PWM `FAN_PWM_OD` | GPIO floats at reset -> R87 100k holds the FET off -> the fan's own pull-up reads 100 % duty |
| Fan power (high side) | Q4 AO3401A from `VSYS_5V`; gate pull-up R89 100k; driver Q5 AO3400A | GPIO11 `FAN_EN` | R90 10k pulls `FAN_EN` high -> driver on -> fan powered at reset; low = zero-RPM |
| Tach | pull-up R91 10k; series R92 1k | J7.TACH -> GPIO10 `FAN_TACH` | input; count falling edges in PCNT (2 pulses / rev) |

Fail-safe chain: any reset, brown-out, crash-induced watchdog reset or unflashed board leaves the fan GPIOs floating, so the fan is powered and at 100 %. Firmware only ever *reduces* cooling.

### 7.1 Suggested firmware fan curve (P4 internal temperature sensor, 3 K hysteresis)

| Die temperature | Fan duty | LEDC duty on GPIO9 (inverted by Q3) | GPIO11 FAN_EN |
| --- | --- | --- | --- |
| < 45 C (off again below 42 C) | 0 % | don't care | low (fan unpowered) |
| 45-55 C | 30 % | 70 % | high |
| 55-75 C | 30 -> 100 % (linear) | 70 -> 0 % | high |
| >= 75 C | 100 % | 0 % | high |
| sensor error / tach fault | 100 % | 0 % | high + raise alarm |

Starting values only -- retune once the thermal numbers in section 3 are measured. Update once per second, slew-limit the duty (~5 %/s) to avoid audible hunting, and treat a tach reading below ~300 RPM for 3 s while duty >= 30 % as a stalled fan (force 100 %, flag an error).

```c
// ESP-IDF sketch -- GPIO numbers generated from board_spec.GPIO_MAP
#define FAN_PWM_GPIO  9   // LEDC, 25 kHz; output inverted by the open-drain FET
#define FAN_TACH_GPIO 10  // PCNT, falling edges, glitch filter ~1 us
#define FAN_EN_GPIO   11  // high = fan powered (board default via pull-up)
temperature_sensor_handle_t ts;               // driver/temperature_sensor.h
temperature_sensor_config_t tcfg = TEMPERATURE_SENSOR_CONFIG_DEFAULT(20, 100);
temperature_sensor_install(&tcfg, &ts); temperature_sensor_enable(ts);
for (;;) {
    float t; int duty = 100;                  // fail-safe default
    if (temperature_sensor_get_celsius(ts, &t) == ESP_OK) duty = fan_curve(t);  // table above
    if (tach_stalled(duty)) duty = 100;
    gpio_set_level(FAN_EN_GPIO, duty > 0);
    ledc_set_duty(LEDC_LOW_SPEED_MODE, LEDC_CHANNEL_0, ((100 - duty) * LEDC_MAX) / 100);
    ledc_update_duty(LEDC_LOW_SPEED_MODE, LEDC_CHANNEL_0);
    vTaskDelay(pdMS_TO_TICKS(1000));
}
```

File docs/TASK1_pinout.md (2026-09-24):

<!-- GENERATED by tools/gen_docs.py from hardware/lib/*.py -- do not edit by hand. Regenerate: python3 -m tools.gen_docs -->

# TASK 1: Architecture & GPIO pinout mapping

Source of truth: `hardware/lib/board_spec.py`, `esp32p4_pinout.py`, `impedance.py`. `validate()`: **clean**.

## 1. Architecture

ESP32-P4NRW32X (Dual-core RISC-V 400 MHz SoC, 32 MB in-package PSRAM, chip rev v3.x; QFN-104 10x10 mm, 0.35 mm pitch, EPAD 7.5 mm) sits at the design origin under a 25 x 25 mm heatsink keep-out. 231 component instances (219 fitted, non-mechanical), 175 nets, 67 part types, 4-layer 1.6 mm HDI board, 110 x 80 mm.

### 1.1 Blocks (component groups in `board_spec.COMPONENTS`)

| Group | Parts | Active parts / connectors | Passives | DNP |
| --- | ---: | --- | --- | ---: |
| SoC | 1 | U1 ESP32-P4NRW32X | - | - |
| SoC decoupling | 41 | - | 41 cap | - |
| SoC support | 11 | - | 1 cap, 10 res | 1 |
| Clock | 5 | Y1 40MHz 10ppm | 2 cap, 2 res | - |
| QSPI flash | 9 | U2 W25Q256JV 32MB | 1 cap, 7 res | - |
| VDD_HP DCDC | 7 | U4 TLV62569, L2 2.2uH | 3 cap, 2 res | - |
| Power input | 5 | D1 PMEG4050EP, D2 PMEG4050EP, D3 PMEG4050EP, F1 PTC 2.5A | 1 cap | - |
| 3V3 buck | 13 | U3 TPS62130, L1 2.2uH | 8 cap, 3 res | - |
| UI | 6 | D4 Green, SW1 Tactile, SW2 Tactile, D5 Red | 2 res | - |
| USB1 HS | 7 | J1 USB-C, U7 TPD2EUSB30 | 1 cap, 4 res | - |
| USB2 debug UART | 17 | J2 USB-C, U8 USBLC6-2SC6, U6 CP2102N, Q1 MMDT3904 | 6 cap, 7 res | - |
| USB3 USB-Serial-JTAG | 7 | J3 USB-C, U9 USBLC6-2SC6 | 1 cap, 4 res | - |
| Ethernet | 34 | U5 LAN8720A, Y2 25MHz, FB1 220R@100MHz, J4 RJ45 MagJack, FB2 220R@100MHz | 11 cap, 18 res | - |
| microSD | 20 | J5 microSD, Q2 AO3401A, U10 TPD4E05U06, U11 TPD4E05U06 | 3 cap, 13 res | 1 |
| Camera CSI | 9 | J_CAM FPC 22P 0.5mm | 2 cap, 6 res | - |
| Display DSI | 10 | J_DSI FPC 22P 0.5mm, J8 JST-SH 2P | 2 cap, 6 res | - |
| I2C | 2 | - | 2 res | - |
| Fan control | 12 | J7 Fan 4P, Q3 AO3400A, Q4 AO3401A, Q5 AO3400A | 1 cap, 7 res | 1 |
| Header | 1 | J6 2x12 header | - | - |
| Display SPI | 6 | J9 2x8 header, Q6 AO3401A | 2 cap, 2 res | 1 |
| Mechanical | 8 | - | - | - |

### 1.2 SoC resources per block

| Block (GPIO_MAP) | GPIOs | Count |
| --- | --- | ---: |
| Header | 0-5, 14-19, 22-23, 32-33, 53-54 | 18 |
| UI | 6 | 1 |
| I2C | 7-8 | 2 |
| Fan | 9-11 | 3 |
| Camera | 12-13 | 2 |
| microSD | 20-21, 39-44 | 8 |
| USB-JTAG | 24-25 | 2 |
| Display | 26-27 | 2 |
| Ethernet | 28-31, 34, 49-52 | 9 |
| Ethernet / Boot | 35 | 1 |
| Boot | 36 | 1 |
| Debug UART | 37-38 | 2 |
| NC (reserved) | 45-48 | 4 |

| Dedicated function (DEDICATED_PADS) | U1 pads | Nets |
| --- | --- | --- |
| MIPI DSI (2-lane D-PHY) | 34-40 | DSI_CLK_N, DSI_CLK_P, DSI_D0_N, DSI_D0_P, DSI_D1_N, DSI_D1_P, DSI_REXT |
| MIPI D-PHY supply | 41 | VDD_MIPI_PHY |
| MIPI CSI (2-lane D-PHY) | 42-48 | CSI_CLK_N, CSI_CLK_P, CSI_D0_N, CSI_D0_P, CSI_D1_N, CSI_D1_P, CSI_REXT |
| USB 2.0 HS OTG UTMI PHY | 49-51 | USBHS_D_N, USBHS_D_P, VDD_USBPHY |
| Quad-SPI flash MSPI | 27-33 | FLASH_CK, FLASH_CS, FLASH_D, FLASH_HOLD, FLASH_Q, FLASH_WP, VDDO_FLASH |
| 40 MHz crystal | 99-100 | XTAL_N, XTAL_P |
| External VDD_HP DCDC control | 78-79 | VDD_HP_EN, VDD_HP_FB |

### 1.3 Power tree (walked from the USB VBUS pins through series power elements)

| Rail | Fed from | Via | Voltage | Loads on the rail (non-passive) |
| --- | --- | --- | --- | --- |
| `VBUS1` | J1 VBUS pins | - | 5 V (USB VBUS) | - |
| `VBUS2` | J2 VBUS pins | - | 5 V (USB VBUS) | U8 USBLC6-2SC6 |
| `VBUS3` | J3 VBUS pins | - | 5 V (USB VBUS) | U9 USBLC6-2SC6 |
| `VSYS_OR` | `VBUS1`, `VBUS2`, `VBUS3` | D1 PMEG4050EP, D2 PMEG4050EP, D3 PMEG4050EP | VBUS - V_F (Schottky OR (D1, D2, D3)) | - |
| `VSYS_5V` | `VSYS_OR` | F1 PTC 2.5A | VBUS - V_F | J6 2x12 header, J8 JST-SH 2P, J9 2x8 header, Q4 AO3401A, U3 TPS62130 |
| `FAN_5V` | `VSYS_5V` | Q4 AO3401A load switch | VBUS - V_F | J7 Fan 4P |
| `+3V3` | `VSYS_5V` | U3 TPS62130 buck + L1 2.2uH | 3.30 V (0.8 V x (1 + R22 75k / R23 24k)) | U1 pads 9, 21, 62, 75, 77, 96, 101, J6 2x12 header, J9 2x8 header, J_CAM FPC 22P 0.5mm, J_DSI FPC 22P 0.5mm, Q2 AO3401A, Q6 AO3401A, U4 TLV62569, U5 LAN8720A, U6 CP2102N |
| `PHY_AVDD` | `+3V3` | FB1 220R@100MHz | 3.30 V | U5 LAN8720A |
| `SD_VDD` | `+3V3` | Q2 AO3401A load switch | 3.30 V | J5 microSD |
| `LCD_SPI_BL` | `+3V3` | Q6 AO3401A load switch | 3.30 V | J9 2x8 header |
| `VDD_USBPHY` | `+3V3` | R1 0R | 3.30 V | U1 pads 51 |
| `VDD_BAT` | `+3V3` | R2 0R | 3.30 V | U1 pads 102 |
| `VDDO_FLASH` | `+3V3` | U1 on-chip LDO VDDO_FLASH (pad 71) | SoC LDO (set by firmware / eFuse) | U1 pads 30, 71, U2 W25Q256JV 32MB |
| `VDDO_PSRAM` | `+3V3` | U1 on-chip LDO VDDO_PSRAM (pad 72) | SoC LDO (set by firmware / eFuse) | U1 pads 59, 67, 72 |
| `VDD_MIPI_PHY` | `+3V3` | U1 on-chip LDO VDDO_3 (pad 73) | SoC LDO (set by firmware / eFuse) | U1 pads 41, 73 |
| `VDDO_4_SDIO` | `+3V3` | U1 on-chip LDO VDDO_4 (pad 74) | SoC LDO (set by firmware / eFuse) | U1 pads 74, 85 |
| `VDD_HP` | `+3V3` | U4 TLV62569 buck + L2 2.2uH | 1.20 V (0.6 V x (1 + R20 499k / R21 499k)) | U1 pads 26, 76, 91 |
| `ETH_CT` | `PHY_AVDD` | FB2 220R@100MHz | 3.30 V | J4 RJ45 MagJack |
| `VDD_HP1_PAD` | `VDD_HP` | R3 0R | 1.20 V | U1 pads 54 |

### 1.4 Clocks

| Ref | MPN | Value | Package | Consumer | Load caps | Notes |
| --- | --- | --- | --- | --- | --- | --- |
| Y1 | 402F4001XIAR | 40MHz 10ppm | 2016 4-pad | U1 ESP32-P4NRW32X | 12pF | Outside keep-out; Espressif requires >= 4.5 mm from the clock pads, no vias on XTAL traces |
| Y2 | X322525MOB4SI | 25MHz | 3225 4-pad | U5 LAN8720A | 18pF | 25 MHz +/-10 ppm / +/-20 ppm stab., C_L 12 pF -- inside the +/-50 ppm 100BASE-TX budget |

RMII reference: GPIO50 `RMII_REF_CLK` -- EMAC RMII_CLK (50 MHz in from PHY). RMII clock is input-only on P4; LAN8720A drives it (REF_CLK-out mode).

## 2. Pinout

### 2.1 GPIO0-GPIO54

51 GPIOs used, 4 NC, 0 undecided. Mux: *IO_MUX fixed* = the peripheral only works on this pad; *GPIO matrix* = routed through the GPIO matrix (any pad); *GPIO* = plain software GPIO; *Strap* = strap-only. "Netlist" in Notes is extracted from the component list (pulls, switches, transistors, following one series resistor).

| GPIO | Pad # | Power domain | Net | Function | Block | Mux | Notes |
| --- | ---: | --- | --- | --- | --- | --- | --- |
| GPIO0 | 104 | VDD_LP = `+3V3` / VDD_BAT = `VDD_BAT` | `GPIO0` | Header (LP GPIO / XTAL_32K_N) | Header | GPIO |  |
| GPIO1 | 1 | VDD_LP = `+3V3` / VDD_BAT = `VDD_BAT` | `GPIO1` | Header (LP GPIO / XTAL_32K_P) | Header | GPIO |  |
| GPIO2 | 2 | VDD_LP = `+3V3` / VDD_BAT = `VDD_BAT` | `GPIO2` | Header (LP GPIO / pad-JTAG MTCK) | Header | GPIO | Weak pull-up after reset; Reset: IE, WPU (after reset) |
| GPIO3 | 3 | VDD_LP = `+3V3` / VDD_BAT = `VDD_BAT` | `GPIO3` | Header (LP GPIO / pad-JTAG MTDI) | Header | GPIO | Reset: IE (after reset) |
| GPIO4 | 4 | VDD_LP = `+3V3` | `GPIO4` | Header (LP GPIO / pad-JTAG MTMS) | Header | GPIO | Reset: IE (after reset) |
| GPIO5 | 5 | VDD_LP = `+3V3` | `GPIO5` | Header (LP GPIO / pad-JTAG MTDO) | Header | GPIO |  |
| GPIO6 | 6 | VDD_LP = `+3V3` | `LED_STATUS` | Status LED (active high) | UI | GPIO |  |
| GPIO7 | 7 | VDD_LP = `+3V3` | `I2C_SDA` | I2C0 SDA (camera SCCB, touch, header) | I2C | GPIO matrix | 2.2k pull-up; Netlist: R84 2.2k to +3V3 |
| GPIO8 | 8 | VDD_LP = `+3V3` | `I2C_SCL` | I2C0 SCL (camera SCCB, touch, header) | I2C | GPIO matrix | 2.2k pull-up; Netlist: R85 2.2k to +3V3 |
| GPIO9 | 10 | VDD_LP = `+3V3` | `FAN_PWM` | Fan PWM (LEDC 25 kHz) -> AO3400A open-drain | Fan | GPIO matrix | Floating at reset -> 100k gate pull-down -> fan runs at 100 % (fail-safe); Netlist: Q3.G via R86 100, R87 100k to GND via R86 100 |
| GPIO10 | 11 | VDD_LP = `+3V3` | `FAN_TACH` | Fan tachometer (PCNT) | Fan | GPIO matrix | 10k pull-up on the fan side + 1k series; Netlist: R91 10k to +3V3 via R92 1k |
| GPIO11 | 12 | VDD_LP = `+3V3` | `FAN_EN` | Fan 5 V high-side switch enable | Fan | GPIO | 10k pull-up -> fan powered by default; Netlist: Q5.G, R90 10k to +3V3 |
| GPIO12 | 13 | VDD_LP = `+3V3` | `CAM_EN` | Camera power enable (FPC IO0) | Camera | GPIO |  |
| GPIO13 | 14 | VDD_LP = `+3V3` | `CAM_IO1` | Camera GPIO/LED (FPC IO1) | Camera | GPIO |  |
| GPIO14 | 15 | VDD_LP = `+3V3` | `LP_UART_TXD` | Header - LP UART TXD (LP_U0TXD) | Header | IO_MUX fixed | IO_MUX LP_U0TXD legal on GPIO 14 |
| GPIO15 | 16 | VDD_LP = `+3V3` | `LP_UART_RXD` | Header - LP UART RXD (LP_U0RXD) | Header | IO_MUX fixed | IO_MUX LP_U0RXD legal on GPIO 15 |
| GPIO16 | 17 | VDD_IO_0 = `+3V3` | `GPIO16` | Header J6 / SPI LCD touch CS (J9) | Header | GPIO |  |
| GPIO17 | 18 | VDD_IO_0 = `+3V3` | `GPIO17` | Header J6 / SPI LCD touch IRQ (J9) | Header | GPIO |  |
| GPIO18 | 19 | VDD_IO_0 = `+3V3` | `GPIO18` | Header J6 / SPI LCD backlight switch (J9, high = off) | Header | GPIO | Netlist: Q6.G, R95 100k to GND |
| GPIO19 | 20 | VDD_IO_0 = `+3V3` | `GPIO19` | Header J6 / SPI LCD TE input (J9) | Header | GPIO |  |
| GPIO20 | 22 | VDD_IO_0 = `+3V3` | `SD_PWR_EN` | microSD VDD switch (high = off) | microSD | GPIO | 3.3 V domain so it can fully turn off the P-FET; Netlist: Q2.G, R70 10k to GND |
| GPIO21 | 23 | VDD_IO_0 = `+3V3` | `SD_DET` | microSD card detect (low = card) | microSD | GPIO | Netlist: R71 10k to +3V3 |
| GPIO22 | 24 | VDD_IO_0 = `+3V3` | `GPIO22` | Header J6 / SPI LCD MISO (J9) | Header | GPIO |  |
| GPIO23 | 25 | VDD_IO_0 = `+3V3` | `GPIO23` | Header J6 / SPI LCD CS (J9) | Header | GPIO |  |
| GPIO24 | 52 | VDD_IO_4 = `+3V3` | `USJ_D_N` | USB Serial/JTAG D- (USJ_DM) | USB-JTAG | IO_MUX fixed | 22R series; IO_MUX USJ_DM legal on GPIO 24 |
| GPIO25 | 53 | VDD_IO_4 = `+3V3` | `USJ_D_P` | USB Serial/JTAG D+ (USJ_DP) | USB-JTAG | IO_MUX fixed | 22R series; Reset: IE, USB_PU (after reset); IO_MUX USJ_DP legal on GPIO 25 |
| GPIO26 | 55 | VDD_IO_4 = `+3V3` | `LCD_BL_PWM` | Display backlight PWM (FPC IO1) | Display | GPIO matrix | LEDC PWM |
| GPIO27 | 56 | VDD_IO_4 = `+3V3` | `LCD_RST` | Display reset (FPC IO0) | Display | GPIO |  |
| GPIO28 | 57 | VDD_IO_4 = `+3V3` | `RMII_CRS_DV` | EMAC RMII_CRS_DV | Ethernet | IO_MUX fixed | IO_MUX RMII_CRS_DV legal on GPIO 28/45/51 |
| GPIO29 | 58 | VDD_IO_4 = `+3V3` | `RMII_RXD0` | EMAC RMII_RXD0 | Ethernet | IO_MUX fixed | IO_MUX RMII_RXD0 legal on GPIO 29/46/52 |
| GPIO30 | 60 | VDD_IO_4 = `+3V3` | `RMII_RXD1` | EMAC RMII_RXD1 | Ethernet | IO_MUX fixed | IO_MUX RMII_RXD1 legal on GPIO 30/47/53 |
| GPIO31 | 61 | VDD_IO_4 = `+3V3` | `ETH_MDC` | EMAC SMI MDC | Ethernet | GPIO matrix | ESP-IDF default MDC pin |
| GPIO32 | 63 | VDD_IO_4 = `+3V3` | `GPIO32` | Header J6 / SPI LCD SCK (J9, 22R series) | Header | GPIO matrix | Reset: IE (at reset) |
| GPIO33 | 64 | VDD_IO_4 = `+3V3` | `GPIO33` | Header J6 / SPI LCD MOSI (J9) | Header | GPIO matrix | Reset: IE (at reset) |
| GPIO34 | 65 | VDD_IO_4 = `+3V3` | `RMII_TXD0` | EMAC RMII_TXD0 | Ethernet | IO_MUX fixed | **STRAP**; Strap: JTAG source select, only if EFUSE_JTAG_SEL_ENABLE is burned (default: ignored); PHY input, never driven at reset; Reset: IE (at reset); IO_MUX RMII_TXD0 legal on GPIO 34/41 |
| GPIO35 | 66 | VDD_IO_4 = `+3V3` | `RMII_TXD1` | EMAC RMII_TXD1 + BOOT strap | Ethernet / Boot | IO_MUX fixed | **STRAP**; Boot strap: 10k pull-up, BOOT button + auto-program NPN to GND; Reset: IE, WPU (at reset); IO_MUX RMII_TXD1 legal on GPIO 35/42; Netlist: R7 10k to +3V3, Q1.C2 via R9 1k, SW2 to GND via R9 1k |
| GPIO36 | 68 | VDD_IO_4 = `+3V3` | `STRAP_GPIO36` | Download-mode qualifier strap | Boot | Strap | **STRAP**; 10k pull-up, otherwise unused (must read 1 for joint-download boot); Reset: IE (at reset); Netlist: R8 10k to +3V3 |
| GPIO37 | 69 | VDD_IO_4 = `+3V3` | `UART0_TXD` | U0TXD -> CP2102N RXD | Debug UART | IO_MUX fixed | **STRAP**; Strapping pin (boot-mode 'any value'); Reset: IE (at reset); IO_MUX U0TXD legal on GPIO 37 |
| GPIO38 | 70 | VDD_IO_4 = `+3V3` | `UART0_RXD` | U0RXD <- CP2102N TXD | Debug UART | IO_MUX fixed | **STRAP**; Strapping pin (boot-mode 'any value'); Reset: IE (at reset); IO_MUX U0RXD legal on GPIO 38 |
| GPIO39 | 80 | VDD_IO_5 = `VDDO_4_SDIO` | `SD_D0` | SDMMC slot0 D0 | microSD | IO_MUX fixed | IO_MUX SD0_D0 legal on GPIO 39; Netlist: R65 51k to VDDO_4_SDIO via R59 0R |
| GPIO40 | 81 | VDD_IO_5 = `VDDO_4_SDIO` | `SD_D1` | SDMMC slot0 D1 | microSD | IO_MUX fixed | IO_MUX SD0_D1 legal on GPIO 40; Netlist: R66 51k to VDDO_4_SDIO via R60 0R |
| GPIO41 | 82 | VDD_IO_5 = `VDDO_4_SDIO` | `SD_D2` | SDMMC slot0 D2 | microSD | IO_MUX fixed | IO_MUX SD0_D2 legal on GPIO 41; Netlist: R67 51k to VDDO_4_SDIO via R61 0R |
| GPIO42 | 83 | VDD_IO_5 = `VDDO_4_SDIO` | `SD_D3` | SDMMC slot0 D3 | microSD | IO_MUX fixed | IO_MUX SD0_D3 legal on GPIO 42; Netlist: R68 51k to VDDO_4_SDIO via R62 0R |
| GPIO43 | 84 | VDD_IO_5 = `VDDO_4_SDIO` | `SD_CLK` | SDMMC slot0 CLK | microSD | IO_MUX fixed | IO_MUX SD0_CLK legal on GPIO 43 |
| GPIO44 | 86 | VDD_IO_5 = `VDDO_4_SDIO` | `SD_CMD` | SDMMC slot0 CMD | microSD | IO_MUX fixed | IO_MUX SD0_CMD legal on GPIO 44; Netlist: R69 51k to VDDO_4_SDIO via R64 0R |
| GPIO45 | 87 | VDD_IO_5 = `VDDO_4_SDIO` | - | Not connected | - | NC | VDD_IO_5/VDDO_4 domain (0 V at boot, 1.8 V in UHS-I); reserved; IO_MUX functions on this pad: RMII_CRS_DV, SD0_D4 |
| GPIO46 | 88 | VDD_IO_5 = `VDDO_4_SDIO` | - | Not connected | - | NC | VDD_IO_5/VDDO_4 domain (0 V at boot, 1.8 V in UHS-I); reserved; IO_MUX functions on this pad: RMII_RXD0, SD0_D5 |
| GPIO47 | 89 | VDD_IO_5 = `VDDO_4_SDIO` | - | Not connected | - | NC | VDD_IO_5/VDDO_4 domain (0 V at boot, 1.8 V in UHS-I); reserved; IO_MUX functions on this pad: RMII_RXD1, SD0_D6 |
| GPIO48 | 90 | VDD_IO_5 = `VDDO_4_SDIO` | - | Not connected | - | NC | VDD_IO_5/VDDO_4 domain (0 V at boot, 1.8 V in UHS-I); reserved; IO_MUX functions on this pad: RMII_RX_ER, SD0_D7 |
| GPIO49 | 92 | VDD_IO_6 = `+3V3` | `RMII_TX_EN` | EMAC RMII_TX_EN | Ethernet | IO_MUX fixed | IO_MUX RMII_TX_EN legal on GPIO 33/40/49 |
| GPIO50 | 93 | VDD_IO_6 = `+3V3` | `RMII_REF_CLK` | EMAC RMII_CLK (50 MHz in from PHY) | Ethernet | IO_MUX fixed | RMII clock is input-only on P4; LAN8720A drives it (REF_CLK-out mode); IO_MUX RMII_REF_CLK legal on GPIO 32/44/50 |
| GPIO51 | 94 | VDD_IO_6 = `+3V3` | `ETH_PHY_RST_N` | PHY nRST | Ethernet | GPIO | Netlist: R51 10k to +3V3 |
| GPIO52 | 95 | VDD_IO_6 = `+3V3` | `ETH_MDIO` | EMAC SMI MDIO | Ethernet | GPIO matrix | 1.5k pull-up; ESP-IDF default MDIO pin; Netlist: R52 1.5k to +3V3 |
| GPIO53 | 97 | VDD_IO_6 = `+3V3` | `GPIO53` | Header J6 / SPI LCD DC (J9) | Header | GPIO |  |
| GPIO54 | 98 | VDD_IO_6 = `+3V3` | `GPIO54` | Header J6 / SPI LCD RESET (J9) | Header | GPIO |  |

### 2.2 Dedicated (non-GPIO) signal pads

| Pad # | Pad name | Function group | Net | Board connection (netlist) |
| ---: | --- | --- | --- | --- |
| 27 | FLASH_CS | Quad-SPI flash MSPI | `FLASH_CS` | R13 0R -> `FLASH_CS_M` -> R19 10k to `VDDO_FLASH`, U2.1 (\~CS) |
| 28 | FLASH_Q | Quad-SPI flash MSPI | `FLASH_Q` | R14 0R -> `FLASH_Q_M` -> U2.2 (DO/IO1) |
| 29 | FLASH_WP | Quad-SPI flash MSPI | `FLASH_WP` | R15 0R -> `FLASH_WP_M` -> U2.3 (\~WP/IO2) |
| 31 | FLASH_HOLD | Quad-SPI flash MSPI | `FLASH_HOLD` | R16 0R -> `FLASH_HOLD_M` -> U2.7 (\~HOLD/IO3) |
| 32 | FLASH_CK | Quad-SPI flash MSPI | `FLASH_CK` | R17 0R -> `FLASH_CK_M` -> U2.6 (CLK) |
| 33 | FLASH_D | Quad-SPI flash MSPI | `FLASH_D` | R18 0R -> `FLASH_D_M` -> U2.5 (DI/IO0) |
| 34 | DSI_REXT | MIPI DSI (2-lane D-PHY) | `DSI_REXT` | R4 4.02k to `GND` |
| 35 | DSI_DATAP1 | MIPI DSI (2-lane D-PHY) | `DSI_D1_P` | R80 0R -> `DISP_D1_P` -> J_DSI.6 (D1_P) |
| 36 | DSI_DATAN1 | MIPI DSI (2-lane D-PHY) | `DSI_D1_N` | R81 0R -> `DISP_D1_N` -> J_DSI.5 (D1_N) |
| 37 | DSI_CLKN | MIPI DSI (2-lane D-PHY) | `DSI_CLK_N` | R83 0R -> `DISP_CLK_N` -> J_DSI.8 (CLK_N) |
| 38 | DSI_CLKP | MIPI DSI (2-lane D-PHY) | `DSI_CLK_P` | R82 0R -> `DISP_CLK_P` -> J_DSI.9 (CLK_P) |
| 39 | DSI_DATAP0 | MIPI DSI (2-lane D-PHY) | `DSI_D0_P` | R78 0R -> `DISP_D0_P` -> J_DSI.3 (D0_P) |
| 40 | DSI_DATAN0 | MIPI DSI (2-lane D-PHY) | `DSI_D0_N` | R79 0R -> `DISP_D0_N` -> J_DSI.2 (D0_N) |
| 42 | CSI_DATAN0 | MIPI CSI (2-lane D-PHY) | `CSI_D0_N` | R73 0R -> `CAM_D0_N` -> J_CAM.2 (D0_N) |
| 43 | CSI_DATAP0 | MIPI CSI (2-lane D-PHY) | `CSI_D0_P` | R72 0R -> `CAM_D0_P` -> J_CAM.3 (D0_P) |
| 44 | CSI_CLKP | MIPI CSI (2-lane D-PHY) | `CSI_CLK_P` | R76 0R -> `CAM_CLK_P` -> J_CAM.9 (CLK_P) |
| 45 | CSI_CLKN | MIPI CSI (2-lane D-PHY) | `CSI_CLK_N` | R77 0R -> `CAM_CLK_N` -> J_CAM.8 (CLK_N) |
| 46 | CSI_DATAN1 | MIPI CSI (2-lane D-PHY) | `CSI_D1_N` | R75 0R -> `CAM_D1_N` -> J_CAM.5 (D1_N) |
| 47 | CSI_DATAP1 | MIPI CSI (2-lane D-PHY) | `CSI_D1_P` | R74 0R -> `CAM_D1_P` -> J_CAM.6 (D1_P) |
| 48 | CSI_REXT | MIPI CSI (2-lane D-PHY) | `CSI_REXT` | R5 4.02k to `GND` |
| 49 | USB-DM | USB 2.0 HS OTG UTMI PHY | `USBHS_D_N` | R29 0R -> `USB1_D_N` -> J1.A7 (D-), J1.B7 (D-), U7.2 (D-) |
| 50 | USB-DP | USB 2.0 HS OTG UTMI PHY | `USBHS_D_P` | R10 1M (DNP) to `GND`; R28 0R -> `USB1_D_P` -> J1.A6 (D+), J1.B6 (D+), U7.1 (D+) |
| 78 | FB_DCDC | External VDD_HP DCDC control | `VDD_HP_FB` | C48 22pF to `VDD_HP`; R20 499k to `VDD_HP`; R21 499k to `GND`; U4.5 (FB) |
| 79 | EN_DCDC | External VDD_HP DCDC control | `VDD_HP_EN` | U4.1 (EN) |
| 99 | XTAL_N | 40 MHz crystal | `XTAL_N` | R12 0R -> `XTAL_N_Y` -> C44 12pF to `GND`, Y1.3 (XOUT) |
| 100 | XTAL_P | 40 MHz crystal | `XTAL_P` | R11 0R -> `XTAL_P_Y` -> C43 12pF to `GND`, Y1.1 (XIN) |
| 103 | CHIP_PU | Reset / power-up | `CHIP_PU` | C42 1uF to `GND`; Q1.6 (C1); R6 10k to `+3V3`; SW1.1 |

### 2.3 Power / ground pads

| Pad # | Pad name | Type | Net | Decoupling at the pad (<= 2 mm) | Feed |
| ---: | --- | --- | --- | --- | --- |
| 9 | VDD_LP | power_in | `+3V3` | 100nF + 10uF (C1, C2) | - |
| 21 | VDD_IO_0 | power_in | `+3V3` | 100nF (C3) | - |
| 26 | VDD_HP_0 | power_in | `VDD_HP` | 100nF + 1uF + 10uF (C4, C5, C6) | - |
| 30 | VDD_FLASH_IO | power_in | `VDDO_FLASH` | 100nF + 1uF (C7, C8) | - |
| 41 | VDD_MIPI_DPHY | power_in | `VDD_MIPI_PHY` | 10nF + 100nF + 1uF (C9, C10, C11) | - |
| 51 | VDD_USBPHY | power_in | `VDD_USBPHY` | 10nF + 100nF + 4.7uF (C12, C13, C14) | R1 0R from `+3V3` |
| 54 | VDD_HP_1 | power_in | `VDD_HP1_PAD` | 100nF + 1uF (C15, C16) | R3 0R from `VDD_HP` |
| 59 | VDD_PSRAM_0 | power_in | `VDDO_PSRAM` | 100nF + 1uF (C17, C18) | - |
| 62 | VDD_IO_4 | power_in | `+3V3` | 100nF + 1uF (C19, C20) | - |
| 67 | VDD_PSRAM_1 | power_in | `VDDO_PSRAM` | 100nF + 1uF (C21, C22) | - |
| 71 | VDDO_FLASH | power_out | `VDDO_FLASH` | 1uF (C23) | - |
| 72 | VDDO_PSRAM | power_out | `VDDO_PSRAM` | 1uF (C24) | - |
| 73 | VDDO_3 | power_out | `VDD_MIPI_PHY` | 1uF (C25) | - |
| 74 | VDDO_4 | power_out | `VDDO_4_SDIO` | 1uF (C26) | - |
| 75 | VDD_LDO | power_in | `+3V3` | 100nF + 10uF (C27, C28) | - |
| 76 | VDD_HP_2 | power_in | `VDD_HP` | 100nF + 1uF + 10uF (C29, C30, C31) | - |
| 77 | VDD_DCDCC | power_in | `+3V3` | 100nF + 10uF (C32, C33) | - |
| 85 | VDD_IO_5 | power_in | `VDDO_4_SDIO` | 100nF (C34) | - |
| 91 | VDD_HP_3 | power_in | `VDD_HP` | 100nF + 1uF (C35, C36) | - |
| 96 | VDD_IO_6 | power_in | `+3V3` | 100nF (C37) | - |
| 101 | VDD_ANA | bidirectional | `+3V3` | 10nF + 100nF (C38, C39) | - |
| 102 | VDD_BAT | bidirectional | `VDD_BAT` | 100nF + 10uF (C40, C41) | R2 0R from `+3V3` |
| 105 | GND | power_in | `GND` | - | - |

## 3. Conflict analysis

### 3.1 Resource sets

| Interface | Kind | GPIOs | U1 pads | Pads are GPIO pads? |
| --- | --- | --- | --- | --- |
| RMII / Ethernet | GPIO | 28-31, 34-35, 49-52 | 57-58, 60-61, 65-66, 92-95 | yes |
| SDIO (microSD) | GPIO | 20-21, 39-44 | 22-23, 80-84, 86 | yes |
| USB Serial/JTAG | GPIO | 24-25 | 52-53 | yes |
| UART0 | GPIO | 37-38 | 69-70 | yes |
| MIPI DSI + CSI | dedicated | - | 34-48 | no |
| USB 2.0 HS | dedicated | - | 49-51 | no |

### 3.2 Pairwise overlap (U1 pad numbers; diagonal = set size)

|  | RMII / Ethernet | SDIO (microSD) | USB Serial/JTAG | UART0 | MIPI DSI + CSI | USB 2.0 HS |
| --- | :---: | :---: | :---: | :---: | :---: | :---: |
| **RMII / Ethernet** | (10) | 0 | 0 | 0 | 0 | 0 |
| **SDIO (microSD)** | 0 | (8) | 0 | 0 | 0 | 0 |
| **USB Serial/JTAG** | 0 | 0 | (2) | 0 | 0 | 0 |
| **UART0** | 0 | 0 | 0 | (2) | 0 | 0 |
| **MIPI DSI + CSI** | 0 | 0 | 0 | 0 | (15) | 0 |
| **USB 2.0 HS** | 0 | 0 | 0 | 0 | 0 | (3) |

Intersections computed by `tools/gen_docs.py` at generation time:

```text
RMII / Ethernet  & SDIO (microSD)   = set()
RMII / Ethernet  & USB Serial/JTAG  = set()
RMII / Ethernet  & UART0            = set()
RMII / Ethernet  & MIPI DSI + CSI   = set()
RMII / Ethernet  & USB 2.0 HS       = set()
SDIO (microSD)   & USB Serial/JTAG  = set()
SDIO (microSD)   & UART0            = set()
SDIO (microSD)   & MIPI DSI + CSI   = set()
SDIO (microSD)   & USB 2.0 HS       = set()
USB Serial/JTAG  & UART0            = set()
USB Serial/JTAG  & MIPI DSI + CSI   = set()
USB Serial/JTAG  & USB 2.0 HS       = set()
UART0            & MIPI DSI + CSI   = set()
UART0            & USB 2.0 HS       = set()
MIPI DSI + CSI   & USB 2.0 HS       = set()
dedicated MIPI/USB-HS pads & GPIO pads = set()
GPIO_MAP duplicates                    = set()
```

Result: **0 overlapping pads** across 15 interface pairs. MIPI DSI/CSI and USB 2.0 HS live on dedicated D-PHY / UTMI pads that are not GPIOs, so they cannot collide with any GPIO-matrix or IO_MUX assignment.

### 3.3 IO_MUX-fixed signals: chosen pad vs legal pads

| Signal | Net | Chosen | Legal (IOMUX_OPTIONS) | Status |
| --- | --- | --- | --- | --- |
| LP_U0TXD | `LP_UART_TXD` | GPIO14 | 14 | OK |
| LP_U0RXD | `LP_UART_RXD` | GPIO15 | 15 | OK |
| USJ_DM | `USJ_D_N` | GPIO24 | 24 | OK |
| USJ_DP | `USJ_D_P` | GPIO25 | 25 | OK |
| RMII_CRS_DV | `RMII_CRS_DV` | GPIO28 | 28/45/51 | OK |
| RMII_RXD0 | `RMII_RXD0` | GPIO29 | 29/46/52 | OK |
| RMII_RXD1 | `RMII_RXD1` | GPIO30 | 30/47/53 | OK |
| RMII_TXD0 | `RMII_TXD0` | GPIO34 | 34/41 | OK |
| RMII_TXD1 | `RMII_TXD1` | GPIO35 | 35/42 | OK |
| U0TXD | `UART0_TXD` | GPIO37 | 37 | OK |
| U0RXD | `UART0_RXD` | GPIO38 | 38 | OK |
| SD0_D0 | `SD_D0` | GPIO39 | 39 | OK |
| SD0_D1 | `SD_D1` | GPIO40 | 40 | OK |
| SD0_D2 | `SD_D2` | GPIO41 | 41 | OK |
| SD0_D3 | `SD_D3` | GPIO42 | 42 | OK |
| SD0_CLK | `SD_CLK` | GPIO43 | 43 | OK |
| SD0_CMD | `SD_CMD` | GPIO44 | 44 | OK |
| RMII_TX_EN | `RMII_TX_EN` | GPIO49 | 33/40/49 | OK |
| RMII_REF_CLK | `RMII_REF_CLK` | GPIO50 | 32/44/50 | OK |

### 3.4 Alternative IO_MUX pads deliberately avoided

Every multi-option IO_MUX signal in `IOMUX_OPTIONS`; each row is a legal pad the design did *not* use and what already occupies it.

| Signal | Chosen | Alternative | Occupant in this design | Fixed IO_MUX on that pad | Why avoided |
| --- | --- | --- | --- | --- | --- |
| RMII_REF_CLK | GPIO50 | GPIO32 | `GPIO32` (Header) | - | free alternative, not needed (header pin) |
| RMII_REF_CLK | GPIO50 | GPIO44 | `SD_CMD` (microSD) | SD0_CMD | collides with microSD `SD_CMD`; pad owns fixed SD0_CMD |
| RMII_TX_EN | GPIO49 | GPIO33 | `GPIO33` (Header) | - | free alternative, not needed (header pin) |
| RMII_TX_EN | GPIO49 | GPIO40 | `SD_D1` (microSD) | SD0_D1 | collides with microSD `SD_D1`; pad owns fixed SD0_D1 |
| RMII_TXD0 | GPIO34 | GPIO41 | `SD_D2` (microSD) | SD0_D2 | collides with microSD `SD_D2`; pad owns fixed SD0_D2 |
| RMII_TXD1 | GPIO35 | GPIO42 | `SD_D3` (microSD) | SD0_D3 | collides with microSD `SD_D3`; pad owns fixed SD0_D3 |
| RMII_CRS_DV | GPIO28 | GPIO45 | NC | SD0_D4 | pad owns fixed SD0_D4; VDD_IO_5 = `VDDO_4_SDIO` (0 V at boot) |
| RMII_CRS_DV | GPIO28 | GPIO51 | `ETH_PHY_RST_N` (Ethernet) | - | taken by Ethernet `ETH_PHY_RST_N` |
| RMII_RXD0 | GPIO29 | GPIO46 | NC | SD0_D5 | pad owns fixed SD0_D5; VDD_IO_5 = `VDDO_4_SDIO` (0 V at boot) |
| RMII_RXD0 | GPIO29 | GPIO52 | `ETH_MDIO` (Ethernet) | - | taken by Ethernet `ETH_MDIO` |
| RMII_RXD1 | GPIO30 | GPIO47 | NC | SD0_D6 | pad owns fixed SD0_D6; VDD_IO_5 = `VDDO_4_SDIO` (0 V at boot) |
| RMII_RXD1 | GPIO30 | GPIO53 | `GPIO53` (Header) | - | free alternative, not needed (header pin) |
| RMII_RX_ER | not used | GPIO31 | `ETH_MDC` (Ethernet) | - | taken by Ethernet `ETH_MDC` |
| RMII_RX_ER | not used | GPIO48 | NC | SD0_D7 | pad owns fixed SD0_D7; VDD_IO_5 = `VDDO_4_SDIO` (0 V at boot) |
| RMII_RX_ER | not used | GPIO54 | `GPIO54` (Header) | - | free alternative, not needed (header pin) |
| RMII_TX_ER | not used | GPIO36 | `STRAP_GPIO36` (Boot) | - | collides with Boot `STRAP_GPIO36`; strapping pin |
| RMII_TX_ER | not used | GPIO43 | `SD_CLK` (microSD) | SD0_CLK | collides with microSD `SD_CLK`; pad owns fixed SD0_CLK |
| REF_50M_CLK_OUT | not used | GPIO23 | `GPIO23` (Header) | - | free alternative, not needed (header pin) |
| REF_50M_CLK_OUT | not used | GPIO39 | `SD_D0` (microSD) | SD0_D0 | collides with microSD `SD_D0`; pad owns fixed SD0_D0 |

Legal RMII pads that do not collide with SDMMC slot 0 (GPIO 39-48) or the NC VDD_IO_5 pads:

| Signal | All legal | SDIO-free | Chosen | Consequence |
| --- | --- | --- | --- | --- |
| RMII_REF_CLK | 32/44/50 | 32/50 | GPIO50 | - |
| RMII_TX_EN | 33/40/49 | 33/49 | GPIO49 | - |
| RMII_TXD0 | 34/41 | 34 | GPIO34 | only non-SDIO option is a strapping pin |
| RMII_TXD1 | 35/42 | 35 | GPIO35 | only non-SDIO option is a strapping pin |
| RMII_CRS_DV | 28/45/51 | 28/51 | GPIO28 | - |
| RMII_RXD0 | 29/46/52 | 29/52 | GPIO29 | - |
| RMII_RXD1 | 30/47/53 | 30/53 | GPIO30 | - |

TXD0/TXD1 have no SDIO-free option except the strapping pins GPIO34/GPIO35, which is why GPIO35 carries both RMII_TXD1 and the BOOT strap (see section 4).

## 4. Strapping and boot

| GPIO | Net | Reset state | Netlist (pulls / switches) | Level at reset | Spec note |
| --- | --- | --- | --- | --- | --- |
| GPIO34 | `RMII_TXD0` | IE (at reset) | U5.TXD0 via R41 | undefined: no board pull (only U5.TXD0 via R41 on the net) | Strap: JTAG source select, only if EFUSE_JTAG_SEL_ENABLE is burned (default: ignored); PHY input, never driven at reset |
| GPIO35 | `RMII_TXD1` | IE, WPU (at reset) | R7 10k to +3V3, Q1.C2 via R9 1k, SW2 to GND via R9 1k, U5.TXD1 via R42 | 1 (external pull-up R7) | Boot strap: 10k pull-up, BOOT button + auto-program NPN to GND |
| GPIO36 | `STRAP_GPIO36` | IE (at reset) | R8 10k to +3V3 | 1 (external pull-up R8) | 10k pull-up, otherwise unused (must read 1 for joint-download boot) |
| GPIO37 | `UART0_TXD` | IE (at reset) | U6.RXD | undefined: no board pull (only U6.RXD on the net) | Strapping pin (boot-mode 'any value') |
| GPIO38 | `UART0_RXD` | IE (at reset) | U6.TXD | undefined: no board pull (only U6.TXD on the net) | Strapping pin (boot-mode 'any value') |

| GPIO35 | GPIO36 | Boot mode | How the board gets there |
| :---: | :---: | --- | --- |
| 1 | x | SPI boot (normal) | R7 pull-up holds GPIO35 high |
| 0 | 1 | Joint download boot (UART0 / USB) | Q1 or SW2 pulls GPIO35 low while CHIP_PU rises; R8 keeps GPIO36 = 1 |
| 0 | 0 | not a listed boot mode | prevented: nothing in the netlist pulls GPIO36 low |

Review flag (computed): GPIO35 is also `RMII_TXD1` (50 MHz RMII TX). Straight-line distance from U1 pad 66 to each active device on that net: . The BOOT button and auto-program transistor therefore add a long stub on the SoC side of the series resistor; keep the stub short or isolate it with a series resistor (~1k) at the tap -- with the R7 10k pull-up a 1k series still gives a valid low (~0.3 V).

Strapping pins with no defined level at reset: GPIO34, GPIO37, GPIO38. Acceptable only where the spec note says the strap value is ignored ('any value' / eFuse-gated); otherwise add a pull.

## 5. Power domains

| Domain | Supply pad = net | GPIOs | Used | NC |
| --- | --- | --- | --- | --- |
| VDD_LP/VDD_BAT | VDD_LP (pad 9) = `+3V3`, 3.30 V via U3 TPS62130 buck + L1 2.2uH<br>VDD_BAT (pad 102) = `VDD_BAT`, 3.30 V via R2 0R | 0-3 | 0-3 | - |
| VDD_LP | VDD_LP (pad 9) = `+3V3`, 3.30 V via U3 TPS62130 buck + L1 2.2uH | 4-15 | 4-15 | - |
| VDD_IO_0 | VDD_IO_0 (pad 21) = `+3V3`, 3.30 V via U3 TPS62130 buck + L1 2.2uH | 16-23 | 16-23 | - |
| VDD_IO_4 | VDD_IO_4 (pad 62) = `+3V3`, 3.30 V via U3 TPS62130 buck + L1 2.2uH | 24-38 | 24-38 | - |
| VDD_IO_5 | VDD_IO_5 (pad 85) = `VDDO_4_SDIO`, SoC LDO via U1 on-chip LDO VDDO_4 (pad 74) | 39-48 | 39-44 | 45-48 |
| VDD_IO_6 | VDD_IO_6 (pad 96) = `+3V3`, 3.30 V via U3 TPS62130 buck + L1 2.2uH | 49-54 | 49-54 | - |

* GPIO45-48 are NC: domain VDD_IO_5 is `VDDO_4_SDIO`, the on-chip LDO output that is 0 V at boot and 1.8 V in UHS-I mode (VDD_IO_5/VDDO_4 domain (0 V at boot, 1.8 V in UHS-I); reserved).
* The SDIO pads GPIO39-44 share that domain, so the card bus is dead until firmware enables the LDO; the card pull-ups R65-R69 go to the same `VDDO_4_SDIO` rail.
* The card power switch GPIO20 `SD_PWR_EN` is in VDD_IO_0 = `+3V3`: a 3.3 V high fully turns off the P-FET (3.3 V domain so it can fully turn off the P-FET); netlist: Q2.G, R70 10k to GND.

## 6. Routing rules

### 6.1 Espressif ESP32-P4 layout guideline vs this board

| Interface | Guideline | This board (computed) | Status |
| --- | --- | --- | --- |
| USB 2.0 HS / FS | 90 ohm differential +/-10% | `USB_90` w 0.150 mm / s 0.150 mm -> 90.7 ohm (0.8 % off) | OK |
| MIPI D-PHY (DSI, CSI) | 100 ohm differential +/-10% | `MIPI_100` w 0.135 mm / s 0.200 mm -> 99.7 ohm (0.3 % off) | OK |
| MIPI skew | intra-pair <= 10 mil (0.254 mm), inter-pair <= 30 mil (0.762 mm) | KiCad length-tuning rule on the `MIPI_100` class | layout rule |
| SDIO | 50 ohm single-ended | `SE_50` w 0.160 mm -> 49.6 ohm (0.8 % off) | OK |
| SDIO length | CMD/DATA within +/-50 mil of CLK; total <= 2000 mil (50.8 mm) | U1 -> J5: 26.3 mm straight / 29.0 mm Manhattan (1143 mil) | OK |
| SoC crystal (40MHz 10ppm) | >= 4.5 mm from the clock pads; no vias on the XTAL traces; 0R at the chip | Y1 centre 10.14 mm from pad 99/100; series R12, R11 | OK |
| VDD_HP DCDC | external buck close to the chip; short SW loop | U4 TLV62569 12.0 mm from FB/EN pads 78/79 (4.0 mm outside the keep-out); L2 adjacent | OK (as close as the keep-out allows) |
| RMII 50 MHz clock | series resistor at the clock driver | R47 33 ohm (Source termination at PHY) | OK |
| RMII data | source termination at the driver | R46 22, R44 22, R45 22, R41 22, R42 22, R43 22 | OK |
| Ethernet MDI | 100 ohm differential (PHY vendor) | `ETH_100` w 0.135 mm / s 0.200 mm -> 99.7 ohm (0.3 % off) | OK |
| QSPI flash | 50 ohm SE, reserve series R at the SoC | 6 x 0R: R13-R18 | OK |
| Reference plane | HS pairs over an unbroken ground plane | L1 routing over In1.Cu: GND (solid, un-split reference plane) | layout rule |

### 6.2 Controlled-impedance geometry (`impedance_rules()`, surface microstrip over L2)

| Net class | Target (ohm) | Width mm / mil | Gap mm / mil | Model (ohm) | Error | Nets |
| --- | ---: | ---: | ---: | ---: | ---: | --- |
| `SE_50` | 50 SE | 0.160 / 6.3 | - | 49.6 | -0.8 % | SDIO, RMII, QSPI flash, crystal |
| `USB_90` | 90 diff | 0.150 / 5.9 | 0.150 / 5.9 | 90.7 | +0.8 % | USB 2.0 HS (J1) and FS (J2/J3) D+/D- |
| `MIPI_100` | 100 diff | 0.135 / 5.3 | 0.200 / 7.9 | 99.7 | -0.3 % | MIPI CSI/DSI clock + data lanes |
| `ETH_100` | 100 diff | 0.135 / 5.3 | 0.200 / 7.9 | 99.7 | -0.3 % | PHY <-> RJ45 magnetics TX/RX pairs |

Closed-form Hammerstad-Jensen / IPC-2141A starting geometry; PCBWay confirms with a field solver and trims widths by +/-10 um.

### 6.3 Stack-up (`STACKUP`)

| # | Layer | Type | Thickness (mm) | Material | Er | Function |
| ---: | --- | --- | ---: | --- | ---: | --- |
| 1 | F.Cu | copper | 0.035 | Cu 0.5 oz + plating | - | Signal_Top (HS routing, refs L2 GND) |
| 2 | PP1 | dielectric | 0.100 | Prepreg 1080 (laser-drillable) | 4.0 | - |
| 3 | In1.Cu | copper | 0.035 | Cu 1 oz | - | GND (solid, un-split reference plane) |
| 4 | Core | dielectric | 1.260 | FR-4 core, Tg170 | 4.4 | - |
| 5 | In2.Cu | copper | 0.035 | Cu 1 oz | - | VCC_3V3 plane (+VDD_HP island under U1) |
| 6 | PP2 | dielectric | 0.100 | Prepreg 1080 (laser-drillable) | 4.0 | - |
| 7 | B.Cu | copper | 0.035 | Cu 0.5 oz + plating | - | Signal_Bottom (low-speed, heat-spreader pour) |
|  | **Total** |  | **1.600** |  |  |  |

### 6.4 Net classes (`netclass_of()`)

| Class | Nets | Members |
| --- | ---: | --- |
| `ETH_100` | 4 | ETH_RX_N, ETH_RX_P, ETH_TX_N, ETH_TX_P |
| `MIPI_100` | 24 | CAM_CLK_N, CAM_CLK_P, CAM_D0_N, CAM_D0_P, CAM_D1_N, CAM_D1_P, CSI_CLK_N, CSI_CLK_P, CSI_D0_N, CSI_D0_P, CSI_D1_N, CSI_D1_P, DISP_CLK_N, DISP_CLK_P, DISP_D0_N, DISP_D0_P, DISP_D1_N, DISP_D1_P, DSI_CLK_N, DSI_CLK_P, DSI_D0_N, DSI_D0_P, DSI_D1_N, DSI_D1_P |
| `POWER` | 12 | +3V3, BUCK_SW, FAN_5V, HP_SW, SD_VDD, VBUS1, VBUS2, VBUS3, VDD_HP, VDD_HP1_PAD, VSYS_5V, VSYS_OR |
| `SE_50` | 42 | FLASH_CK, FLASH_CK_M, FLASH_CS, FLASH_CS_M, FLASH_D, FLASH_D_M, FLASH_HOLD, FLASH_HOLD_M, FLASH_Q, FLASH_Q_M, FLASH_WP, FLASH_WP_M, RMII_CRS_DV, RMII_CRS_DV_PHY, RMII_REF_CLK, RMII_REF_CLK_PHY, RMII_RXD0, RMII_RXD0_PHY, RMII_RXD1, RMII_RXD1_PHY, RMII_TXD0, RMII_TXD0_PHY, RMII_TXD1, RMII_TXD1_PHY, RMII_TX_EN, RMII_TX_EN_PHY, SD_CLK, SD_CLK_C, SD_CMD, SD_CMD_C, SD_D0, SD_D0_C, SD_D1, SD_D1_C, SD_D2, SD_D2_C, SD_D3, SD_D3_C, XTAL_N, XTAL_N_Y, XTAL_P, XTAL_P_Y |
| `USB_90` | 10 | USB1_D_N, USB1_D_P, USB2_D_N, USB2_D_P, USB3_D_N, USB3_D_P, USBHS_D_N, USBHS_D_P, USJ_D_N, USJ_D_P |
| `Default` | 83 | all other nets |

### 6.5 Differential pairs (`DIFF_PAIRS`)

| P | N | Class | P pins | N pins | Status |
| --- | --- | --- | ---: | ---: | --- |
| `USB1_D_P` | `USB1_D_N` | `USB_90` | 4 | 4 | OK |
| `USBHS_D_P` | `USBHS_D_N` | `USB_90` | 3 | 2 | OK |
| `USB2_D_P` | `USB2_D_N` | `USB_90` | 5 | 5 | OK |
| `USB3_D_P` | `USB3_D_N` | `USB_90` | 5 | 5 | OK |
| `USJ_D_P` | `USJ_D_N` | `USB_90` | 2 | 2 | OK |
| `CSI_D0_P` | `CSI_D0_N` | `MIPI_100` | 2 | 2 | OK |
| `CSI_D1_P` | `CSI_D1_N` | `MIPI_100` | 2 | 2 | OK |
| `CSI_CLK_P` | `CSI_CLK_N` | `MIPI_100` | 2 | 2 | OK |
| `CAM_D0_P` | `CAM_D0_N` | `MIPI_100` | 2 | 2 | OK |
| `CAM_D1_P` | `CAM_D1_N` | `MIPI_100` | 2 | 2 | OK |
| `CAM_CLK_P` | `CAM_CLK_N` | `MIPI_100` | 2 | 2 | OK |
| `DSI_D0_P` | `DSI_D0_N` | `MIPI_100` | 2 | 2 | OK |
| `DSI_D1_P` | `DSI_D1_N` | `MIPI_100` | 2 | 2 | OK |
| `DSI_CLK_P` | `DSI_CLK_N` | `MIPI_100` | 2 | 2 | OK |
| `DISP_D0_P` | `DISP_D0_N` | `MIPI_100` | 2 | 2 | OK |
| `DISP_D1_P` | `DISP_D1_N` | `MIPI_100` | 2 | 2 | OK |
| `DISP_CLK_P` | `DISP_CLK_N` | `MIPI_100` | 2 | 2 | OK |
| `ETH_TX_P` | `ETH_TX_N` | `ETH_100` | 3 | 3 | OK |
| `ETH_RX_P` | `ETH_RX_N` | `ETH_100` | 3 | 3 | OK |

## 7. Items pending verification (from spec strings)

| Where | Field | Text |
| --- | --- | --- |
| C43, C44 | note | C_L 10 pF, \~4 pF stray incl. the 10 mm trace; tune on first article |

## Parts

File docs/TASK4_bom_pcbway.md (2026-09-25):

<!-- GENERATED by tools/gen_docs.py from hardware/lib/*.py -- do not edit by hand. Regenerate: python3 -m tools.gen_docs -->

# TASK 4: BOM for PCBWay turnkey assembly

Generated from `board_spec.bom_lines()`; the CSV `hardware/output/bom_pcbway.csv` holds exactly the rows of the two tables below (same columns, same order).

**Summary:** 63 unique fitted line items, 219 placements (215 SMD on 59 lines, 4 THT on 4 lines: J4, J6, J7, J9), double-sided assembly: 204 top + 15 bottom (0402 decoupling under U1: C10, C11, C13, C14, C20, C21, C23, C25, C26, C27, C28, C29, C31, C32, C33). SMD parts with THT shell/retention legs: J1, J2, J3. DNP: 4 footprints on 3 lines (C77, C85, R10, R88). Excluded (mechanical, no part to buy): H1, H2, H3, H4, H5, H6, H7, H8. Check: BOM placements 219 == fitted non-mechanical components 219 -> OK.

## 1. Fitted parts

| Item # | Designator | Quantity | Value/Name | Package/Footprint | Manufacturer Part Number (MPN) | Manufacturer | Description | Mount (SMD/THT) | LCSC # | Assembly note |
| ---: | --- | ---: | --- | --- | --- | --- | --- | --- | --- | --- |
| 1 | C1, C3, C4, C7, C10, C13, C15, C17, C19, C21, C27, C29, C32, C34, C35, C37, C39, C40, C45, C52, C60, C62, C64, C70, C71, C72, C75, C79, C81, C83, C86 | 31 | 100nF | 0402 [C_0402_1005Metric] | CL05B104KO5NNNC | Samsung Electro-Mechanics | MLCC 100nF 16V X7R | SMD | C1525 |  |
| 2 | C2, C6, C28, C31, C33, C41 | 6 | 10uF | 0402 [C_0402_1005Metric] | CL05A106MQ5NUNC | Samsung Electro-Mechanics | MLCC 10uF 6.3V X5R | SMD | C15525 |  |
| 3 | C5, C8, C11, C16, C18, C20, C22, C23, C24, C25, C26, C30, C36, C42, C61, C63, C68, C69, C73, C80, C82 | 21 | 1uF | 0402 [C_0402_1005Metric] | CL05A105KA5NQNC | Samsung Electro-Mechanics | MLCC 1uF 25V X5R | SMD | C52923 |  |
| 4 | C9, C12, C38, C76 | 4 | 10nF | 0402 [C_0402_1005Metric] | CL05B103KB5NNNC | Samsung Electro-Mechanics | MLCC 10nF 50V X7R | SMD | C15195 |  |
| 5 | C14, C46 | 2 | 4.7uF | 0402 [C_0402_1005Metric] | CL05A475MP5NRNC | Samsung Electro-Mechanics | MLCC 4.7uF 10V X5R | SMD | C23733 |  |
| 6 | C43, C44 | 2 | 12pF | 0402 [C_0402_1005Metric] | CL05C120JB5NNNC | Samsung Electro-Mechanics | MLCC 12pF 50V C0G | SMD |  | no LCSC number |
| 7 | C47, C53, C54 | 3 | 22uF | 0805 [C_0805_2012Metric] | CL21A226MQQNNNE | Samsung Electro-Mechanics | MLCC 22uF 6.3V X5R | SMD | C5674 |  |
| 8 | C48 | 1 | 22pF | 0402 [C_0402_1005Metric] | CL05C220JB5NNNC | Samsung Electro-Mechanics | MLCC 22pF 50V C0G | SMD | C70464 |  |
| 9 | C49, C50, C51, C58, C59, C65, C78, C84 | 8 | 10uF | 0805 [C_0805_2012Metric] | CL21A106KAYNNNE | Samsung Electro-Mechanics | MLCC 10uF 25V X5R | SMD | C15850 |  |
| 10 | C55, C56 | 2 | 47uF | 0805 [C_0805_2012Metric] | CL21A476MQYNNNE | Samsung Electro-Mechanics | MLCC 47uF 6.3V X5R | SMD | C16780 |  |
| 11 | C57 | 1 | 3.3nF | 0402 [C_0402_1005Metric] | CL05B332KB5NNNC | Samsung Electro-Mechanics | MLCC 3.3nF 50V X7R | SMD | C26404 |  |
| 12 | C66, C67 | 2 | 18pF | 0402 [C_0402_1005Metric] | CL05C180JB5NNNC | Samsung Electro-Mechanics | MLCC 18pF 50V C0G | SMD | C307443 |  |
| 13 | C74 | 1 | 470pF | 0402 [C_0402_1005Metric] | CL05B471KB5NNNC | Samsung Electro-Mechanics | MLCC 470pF 50V X7R | SMD | C26412 |  |
| 14 | D1, D2, D3 | 3 | PMEG4050EP | SOD-128 [D_SOD-128] | PMEG4050EP,115 | Nexperia | 40 V 5 A low-VF Schottky (\~0.4 V @ 2.5 A) -- VBUS OR-ing | SMD | C96235 |  |
| 15 | D4 | 1 | Green | 0603 [LED_0603_1608Metric] | 150060GS75000 | Wurth Elektronik | Green LED | SMD | C5252984 |  |
| 16 | D5 | 1 | Red | 0603 [LED_0603_1608Metric] | 150060RS75000 | Wurth Elektronik | Red LED | SMD | C3030991 |  |
| 17 | F1 | 1 | PTC 2.5A | 1812 [Fuse_1812_4532Metric] | MF-MSMF250/16X-2 | Bourns | Resettable fuse, 2.5 A hold / 5 A trip, 16 V, on VSYS | SMD | C210838 |  |
| 18 | FB1, FB2 | 2 | 220R@100MHz | 0603 [L_0603_1608Metric] | BLM18PG221SN1D | Murata | Ferrite bead 220 ohm, 1.4 A | SMD | C80165 |  |
| 19 | J1, J2, J3 | 3 | USB-C | USB Type-C 16P, top-mount [USB_C_Receptacle_GCT_USB4105-xx-A_16P_TopMnt_Horizontal] | USB4105-GF-A | GCT | USB 2.0 Type-C receptacle (UFP, 5.1k Rd); SMD contacts + 4 THT shell legs | SMD | C3020560 | SMD with THT legs (paste-in-hole / hand-solder the legs) |
| 20 | J4 | 1 | RJ45 MagJack | RJ45 THT, integrated magnetics + 2 LEDs [RJ45_Hanrun_HR911105A_Horizontal] | HR911105A | HanRun | RJ45 with 10/100 magnetics (1:1, CT) and green/yellow LEDs | THT | C12074 | THT, top side |
| 21 | J5 | 1 | microSD | microSD push-push, SMT [microSD_HC_Hirose_DM3AT-SF-PEJM5] | DM3AT-SF-PEJM5 | Hirose | microSD socket with card-detect switch | SMD | C114218 |  |
| 22 | J6 | 1 | 2x12 header | 2x12 2.54 mm THT [PinHeader_2x12_P2.54mm_Vertical] | 61302421121 | Wurth Elektronik | 2x12 expansion header | THT |  | THT, top side; no LCSC number |
| 23 | J7 | 1 | Fan 4P | 2.54 mm 4-pin fan header, THT [FanPinHeader_1x04_P2.54mm_Vertical] | 47053-1000 | Molex | Intel 4-wire PWM fan header (1 GND, 2 +V, 3 TACH, 4 PWM) | THT | C240840 | THT, top side |
| 24 | J8 | 1 | JST-SH 2P | JST SH 1.0 mm 2P, SMT [JST_SH_SM02B-SRSS-TB_1x02-1MP_P1.00mm_Horizontal] | SM02B-SRSS-TB(LF)(SN) | JST | Display backlight 5 V feed | SMD | C160402 |  |
| 25 | J9 | 1 | 2x8 header | 2x8 2.54 mm THT [PinHeader_2x08_P2.54mm_Vertical] | 61301621121 | Wurth Elektronik | 2x8 SPI/I2C TFT display header (dupont-wire friendly) | THT |  | THT, top side; no LCSC number |
| 26 | J_CAM, J_DSI | 2 | FPC 22P 0.5mm | FPC 22P 0.5 mm, top contact, horizontal, SMT [Amphenol_F32Q-1A7x1-11022_1x22-1MP_P0.5mm_Horizontal] | F32Q-1A7H1-11022 | Amphenol ICC | 22-pin 0.5 mm FPC, same top-contact part as Raspberry Pi 5 -> standard Pi cables, no mirroring | SMD | C3169253 |  |
| 27 | L1 | 1 | 2.2uH | 5.3x5.5 mm shielded [L_Coilcraft_XAL5030-XXX] | XAL5030-222MEC | Coilcraft | 2.2 uH, Isat 9.2 A, DCR 14.5 mOhm -- 3 A buck inductor | SMD | C920280 |  |
| 28 | L2 | 1 | 2.2uH | 2520 (1008) metal alloy [L_1008_2520Metric] | DFE252012F-2R2M=P2 | Murata | 2.2 uH, Isat 3.3 A, 82 mOhm -- VDD_HP buck inductor | SMD | C576403 |  |
| 29 | Q1 | 1 | MMDT3904 | SOT-363 [SOT-363_SC-70-6] | MMDT3904-7-F | Diodes Incorporated | Dual NPN for DTR/RTS auto-reset + boot-strap circuit | SMD | C83572 |  |
| 30 | Q2, Q4, Q6 | 3 | AO3401A | SOT-23 [SOT-23] | AO3401A | Alpha & Omega Semiconductor | -30 V -4 A P-MOSFET (high-side load switch) | SMD | C15127 |  |
| 31 | Q3, Q5 | 2 | AO3400A | SOT-23 [SOT-23] | AO3400A | Alpha & Omega Semiconductor | 30 V 5.7 A logic-level N-MOSFET (Vgs(th) 1.45 V max) | SMD | C20917 |  |
| 32 | R1, R2, R3, R11, R12, R13, R14, R15, R16, R17, R18, R28, R29, R59, R60, R61, R62, R63, R64, R72, R73, R74, R75, R76, R77, R78, R79, R80, R81, R82, R83 | 31 | 0R | 0402 [R_0402_1005Metric] | RC0402JR-070RL | YAGEO | Thick-film resistor, jumper | SMD | C60485 |  |
| 33 | R4, R5 | 2 | 4.02k | 0402 [R_0402_1005Metric] | RC0402FR-074K02L | YAGEO | Thick-film resistor, 1 %, 1/16 W | SMD |  | no LCSC number |
| 34 | R6, R7, R8, R19, R35, R36, R49, R50, R51, R70, R71, R90, R91 | 13 | 10k | 0402 [R_0402_1005Metric] | RC0402FR-0710KL | YAGEO | Thick-film resistor, 1 %, 1/16 W | SMD | C60490 |  |
| 35 | R9, R25, R34, R92, R93 | 5 | 1k | 0402 [R_0402_1005Metric] | RC0402FR-071KL | YAGEO | Thick-film resistor, 1 %, 1/16 W | SMD | C106235 |  |
| 36 | R20, R21 | 2 | 499k | 0402 [R_0402_1005Metric] | RC0402FR-07499KL | YAGEO | Thick-film resistor, 1 %, 1/16 W | SMD |  | no LCSC number |
| 37 | R22 | 1 | 75k | 0402 [R_0402_1005Metric] | RC0402FR-0775KL | YAGEO | Thick-film resistor, 1 %, 1/16 W | SMD |  | no LCSC number |
| 38 | R23 | 1 | 24k | 0402 [R_0402_1005Metric] | RC0402FR-0724KL | YAGEO | Thick-film resistor, 1 %, 1/16 W | SMD |  | no LCSC number |
| 39 | R24, R87, R89, R95 | 4 | 100k | 0402 [R_0402_1005Metric] | RC0402FR-07100KL | YAGEO | Thick-film resistor, 1 %, 1/16 W | SMD |  | no LCSC number |
| 40 | R26, R27, R30, R31, R37, R38 | 6 | 5.1k | 0402 [R_0402_1005Metric] | RC0402FR-075K1L | YAGEO | Thick-film resistor, 1 %, 1/16 W | SMD |  | no LCSC number |
| 41 | R32 | 1 | 22.1k | 0402 [R_0402_1005Metric] | RC0402FR-0722K1L | YAGEO | Thick-film resistor, 1 %, 1/16 W | SMD |  | no LCSC number |
| 42 | R33 | 1 | 47.5k | 0402 [R_0402_1005Metric] | RC0402FR-0747K5L | YAGEO | Thick-film resistor, 1 %, 1/16 W | SMD |  | no LCSC number |
| 43 | R39, R40, R41, R42, R43, R44, R45, R46, R94 | 9 | 22 | 0402 [R_0402_1005Metric] | RC0402FR-0722RL | YAGEO | Thick-film resistor, 1 %, 1/16 W | SMD |  | no LCSC number |
| 44 | R47 | 1 | 33 | 0402 [R_0402_1005Metric] | RC0402FR-0733RL | YAGEO | Thick-film resistor, 1 %, 1/16 W | SMD |  | no LCSC number |
| 45 | R48 | 1 | 12.1k | 0402 [R_0402_1005Metric] | RC0402FR-0712K1L | YAGEO | Thick-film resistor, 1 %, 1/16 W | SMD |  | no LCSC number |
| 46 | R52 | 1 | 1.5k | 0402 [R_0402_1005Metric] | RC0402FR-071K5L | YAGEO | Thick-film resistor, 1 %, 1/16 W | SMD |  | no LCSC number |
| 47 | R53, R54, R55, R56 | 4 | 49.9 | 0402 [R_0402_1005Metric] | RC0402FR-0749R9L | YAGEO | Thick-film resistor, 1 %, 1/16 W | SMD | C87044 |  |
| 48 | R57, R58 | 2 | 330 | 0402 [R_0402_1005Metric] | RC0402FR-07330RL | YAGEO | Thick-film resistor, 1 %, 1/16 W | SMD |  | no LCSC number |
| 49 | R65, R66, R67, R68, R69 | 5 | 51k | 0402 [R_0402_1005Metric] | RC0402FR-0751KL | YAGEO | Thick-film resistor, 1 %, 1/16 W | SMD |  | no LCSC number |
| 50 | R84, R85 | 2 | 2.2k | 0402 [R_0402_1005Metric] | RC0402FR-072K2L | YAGEO | Thick-film resistor, 1 %, 1/16 W | SMD |  | no LCSC number |
| 51 | R86 | 1 | 100 | 0402 [R_0402_1005Metric] | RC0402FR-07100RL | YAGEO | Thick-film resistor, 1 %, 1/16 W | SMD |  | no LCSC number |
| 52 | SW1, SW2 | 2 | Tactile | 4.2x3.2 mm SMD [SW_SPST_PTS810] | PTS810SJM250SMTRLFS | C&K | SMD tactile switch | SMD | C116501 |  |
| 53 | U1 | 1 | ESP32-P4NRW32X | QFN-104 10x10 mm, 0.35 mm pitch, EPAD 7.5 mm [ESP32-P4] | ESP32-P4NRW32X | Espressif Systems | Dual-core RISC-V 400 MHz SoC, 32 MB in-package PSRAM, chip rev v3.x | SMD | C54540373 | EPAD on the capped via-in-pad array; fine pitch 0.35 mm |
| 54 | U2 | 1 | W25Q256JV 32MB | WSON-8 8x6 mm [WSON-8-1EP_8x6mm_P1.27mm_EP3.4x4.3mm] | W25Q256JVEIQ | Winbond | 256 Mbit (32 MB) 3.3 V Quad-SPI NOR flash, 133 MHz, 4-byte addressing | SMD | C97522 |  |
| 55 | U3 | 1 | TPS62130 | VQFN-16 3x3 mm [VQFN-16-1EP_3x3mm_P0.5mm_EP1.68x1.68mm_ThermalVias] | TPS62130RGTR | Texas Instruments | 3-17 V in, 3 A synchronous buck (DCS-Control), 100 % mode, 5 V->3V3 main rail | SMD | C43590 |  |
| 56 | U4 | 1 | TLV62569 | SOT-23-5 [SOT-23-5] | TLV62569DBVR | Texas Instruments | 2 A buck, Espressif-verified external DCDC for ESP32-P4 VDD_HP (EN/FB driven by the SoC) | SMD | C141836 |  |
| 57 | U5 | 1 | LAN8720A | VQFN-24 4x4 mm [VQFN-24-1EP_4x4mm_P0.5mm_EP2.5x2.5mm_ThermalVias] | LAN8720A-CP-TR | Microchip | 10/100 Ethernet RMII PHY, HP Auto-MDIX, ESP-IDF 'lan87xx' driver | SMD | C45223 |  |
| 58 | U6 | 1 | CP2102N | QFN-24 4x4 mm [QFN-24-1EP_4x4mm_P0.5mm_EP2.6x2.6mm] | CP2102N-A02-GQFN24R | Silicon Labs | USB 2.0 FS to UART bridge, 3 Mbaud, DTR/RTS for auto-program | SMD | C969151 |  |
| 59 | U7 | 1 | TPD2EUSB30 | SOT-3 (DRT) 1.0x1.0 mm [Texas_DRT-3] | TPD2EUSB30DRTR | Texas Instruments | 2-channel ultra-low-capacitance ESD (0.7 pF typ) for USB 2.0 HS -- Espressif limit is 1 pF | SMD | C97502 |  |
| 60 | U8, U9 | 2 | USBLC6-2SC6 | SOT-23-6 [SOT-23-6] | USBLC6-2SC6 | STMicroelectronics | 2-line USB ESD with VBUS clamp (3.5 pF max: full-speed ports only) | SMD | C7519 |  |
| 61 | U10, U11 | 2 | TPD4E05U06 | USON-10 2.5x1.0 mm [USON-10_2.5x1.0mm_P0.5mm] | TPD4E05U06DQAR | Texas Instruments | 4-channel 0.5 pF flow-through ESD array (microSD, UHS-I safe) | SMD | C138714 |  |
| 62 | Y1 | 1 | 40MHz 10ppm | 2016 4-pad [Crystal_SMD_2016-4Pin_2.0x1.6mm] | 402F4001XIAR | CTS | 40 MHz +/-10 ppm crystal, C_L 10 pF, ESR 60 ohm max, for ESP32-P4 | SMD | C5508101 |  |
| 63 | Y2 | 1 | 25MHz | 3225 4-pad [Crystal_SMD_3225-4Pin_3.2x2.5mm] | X322525MOB4SI | YXC | 25 MHz +/-10 ppm / +/-20 ppm stab., C_L 12 pF -- inside the +/-50 ppm 100BASE-TX budget | SMD | C9006 |  |

## 2. Do Not Populate

Footprints exist on the PCB (and in the pick-and-place file); do not buy or place these.

| Item # | Designator | Quantity | Value/Name | Package/Footprint | Manufacturer Part Number (MPN) | Manufacturer | Description | Mount (SMD/THT) | LCSC # | Assembly note |
| ---: | --- | ---: | --- | --- | --- | --- | --- | --- | --- | --- |
| 64 | C77, C85 | 2 | 10pF | 0402 [C_0402_1005Metric] | CL05C100CB5NNNC | Samsung Electro-Mechanics | MLCC 10pF 50V C0G | SMD |  | DO NOT POPULATE; Espressif: reserve CLK cap for tuning; Optional CLK edge filter |
| 65 | R10 | 1 | 1M | 0402 [R_0402_1005Metric] | RC0402FR-071ML | YAGEO | Thick-film resistor, 1 %, 1/16 W | SMD |  | DO NOT POPULATE; Espressif rev1.x DP pull-down, DNP on rev v3.x |
| 66 | R88 | 1 | 10k | 0402 [R_0402_1005Metric] | RC0402FR-0710KL | YAGEO | Thick-film resistor, 1 %, 1/16 W | SMD | C60490 | DO NOT POPULATE; Only for fans without internal PWM pull-up |

Lines without an LCSC number (PCBWay sources by MPN): C43, C44; J6; J9; R4, R5; R20, R21; R22; R23; R24, R87, R89, R95; R26, R27, R30, R31, R37, R38; R32; R33; R39, R40, R41, R42, R43, R44, R45, R46, R94; R47; R48; R52; R57, R58; R65, R66, R67, R68, R69; R84, R85; R86.

## 3. Verification flags carried from the spec

| Where | Field | Text |
| --- | --- | --- |
| C43, C44 | note | C_L 10 pF, \~4 pF stray incl. the 10 mm trace; tune on first article |

## 4. PCBWay ordering notes

| Item | Requirement |
| --- | --- |
| Layers / build | 4-layer HDI 1+2+1: laser microvias L1->L2 and L4->L3, mechanical through-vias L1->L4 |
| Finished thickness | 1.60 mm (sum of `STACKUP`) |
| Board size | 110 x 80 mm, corner radius 3.0 mm |
| Materials | FR-4 core, Tg170; Prepreg 1080 (laser-drillable) |
| Copper | F.Cu Cu 0.5 oz + plating; In1.Cu Cu 1 oz; In2.Cu Cu 1 oz; B.Cu Cu 0.5 oz + plating |
| Surface finish | ENIG (flat pads for the 0.35 mm-pitch QFN-104 and the capped via-in-pad EPAD) |
| Impedance control | SE_50 50 ohm SE (w 0.160 mm, L1 ref L2); USB_90 90 ohm diff (w 0.150 / s 0.150 mm, L1 ref L2); MIPI_100 100 ohm diff (w 0.135 / s 0.200 mm, L1 ref L2); ETH_100 100 ohm diff (w 0.135 / s 0.200 mm, L1 ref L2); tolerance +/-10 %, fab to confirm with its field solver |
| Via-in-pad | 7x7 array, 0.30 mm drill / 0.60 mm pad, 1.0 mm pitch in the U1 EPAD: IPC-4761 Type VII (resin-filled + copper-capped, VIPPO), planarised flush |
| Min track / space | 3.5 / 3.5 mil (0.089 mm) |
| Microvia | 0.1 mm laser-drilled (L1-L2, L4-L3), in the 1080 prepreg |
| Hole plating | >= 25 um average (assumed by the thermal-via calculation in TASK 2) |
| Assembly | double-sided: 15 x 0402 on the bottom (C10, C11, C13, C14, C20, C21, C23, C25, C26, C27, C28, C29, C31, C32, C33), all other parts on top; one extra stencil + reflow pass; 215 SMD + 4 THT placements; finest pitch 0.35 mm (U1); fiducials FID1 (-52.1, 31.4), FID2 (52.0, 28.0), FID3 (47.0, -24.0) |
| DNP | C77, C85, R10, R88 |

Stack-up to attach to the order:

| # | Layer | Type | Thickness (mm) | Material | Er | Function |
| ---: | --- | --- | ---: | --- | ---: | --- |
| 1 | F.Cu | copper | 0.035 | Cu 0.5 oz + plating | - | Signal_Top (HS routing, refs L2 GND) |
| 2 | PP1 | dielectric | 0.100 | Prepreg 1080 (laser-drillable) | 4.0 | - |
| 3 | In1.Cu | copper | 0.035 | Cu 1 oz | - | GND (solid, un-split reference plane) |
| 4 | Core | dielectric | 1.260 | FR-4 core, Tg170 | 4.4 | - |
| 5 | In2.Cu | copper | 0.035 | Cu 1 oz | - | VCC_3V3 plane (+VDD_HP island under U1) |
| 6 | PP2 | dielectric | 0.100 | Prepreg 1080 (laser-drillable) | 4.0 | - |
| 7 | B.Cu | copper | 0.035 | Cu 0.5 oz + plating | - | Signal_Bottom (low-speed, heat-spreader pour) |
|  | **Total** |  | **1.600** |  |  |  |

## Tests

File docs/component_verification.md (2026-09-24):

> **Component verification record.** Evidence for every MPN, LCSC number and third-party pinout used in
> `hardware/lib/board_spec.py`. The candidates marked NOT FOUND / FAILS / CORRECTED-TO below have already been
> replaced in the spec (TPD2EUSB30DRTR on USB-HS, MF-MSMF250/16X-2, Amphenol F32Q FPC, CTS 402F4001XIAR,
> YXC X322525MOB4SI, TPD4E05U06DQAR on microSD). Items still marked UNVERIFIED should be confirmed against the
> datasheet before ordering.

# ESP32-P4 dev board: MPN verification and pinout report

Date: 2026-09-24. Methods: web search result titles and snippets from LCSC, JLCPCB, Mouser, DigiKey, Newark, RS, TI, ST, Microchip, SiLabs and Espressif; the official KiCad libraries on GitLab, fetched with curl, with pins parsed from the `.kicad_sym` files; ESP-IDF and raspberrypi/documentation sources on raw.githubusercontent.com. Vendor PDFs could not be opened because the proxy blocks them, so datasheet numbers come from search snippets. Anything I could not confirm is marked **UNVERIFIED**.

---

## 1. MPN verification table

| # | Candidate MPN | Status | Corrected / Final MPN | Key spec verified | LCSC C# | Evidence |
|---|---|---|---|---|---|---|
| 1 | ESP32-P4NRW32X | VERIFIED | ESP32-P4NRW32X | Chip rev v3.x, 32 MB in-package PSRAM, no in-package flash, QFN-104 10x10 | C54540373 (JLCPCB) | https://jlcpcb.com/partdetail/EspressifSystems-ESP32P4NRW32X/C54540373 ; https://documentation.espressif.com/esp32-p4-chip-revision-v3.x_user_guide_en.html |
| 1b | ESP32-P4NRW32 (no X) | VERIFIED as the older part | — | This is the v1.x part (see the rev v1.3 datasheet). It is marked EOL and replaced by the ...X part. v1.x and v3.x need separate firmware builds. | C22387510 | https://www.lcsc.com/product-detail/C22387510.html ; https://documentation.espressif.com/esp32-p4-chip-revision-v1.3_datasheet_en.pdf |
| 2 | W25Q256JVEIQ | VERIFIED | W25Q256JVEIQ | 256 Mbit, 3 V, SPI/Dual/Quad at 133 MHz, WSON-8 8x6 | C97522 | https://www.lcsc.com/product-detail/C97522.html ; https://www.digikey.com/en/products/detail/winbond-electronics/W25Q256JVEIQ/6810681 |
| 2b | MX25L25645GZ2I-08G | VERIFIED | (alternate) | 256 Mbit, 2.7-3.6 V, 120 MHz, WSON-8 8x6 | C2802978 | https://www.lcsc.com/product-detail/NOR-FLASH_MXIC-Macronix-MX25L25645GZ2I-08G_C2802978.html |
| 3 | TPS62130RGTR | VERIFIED | TPS62130RGTR | 3-17 V in, 3 A, 0.9-6 V out, VQFN-16 3x3, 2.5 MHz (see the FSW/DEF/VFB answers below the table) | C43590 | https://www.lcsc.com/product-detail/DC-DC-Converters_TI_TPS62130RGTR_TPS62130RGTR_C43590.html ; https://www.ti.com/lit/ds/symlink/tps62130.pdf |
| 4 | TLV62569DBVR | VERIFIED | TLV62569DBVR | 2 A buck, **VIN 2.5-5.5 V**, 1.5 MHz, SOT-23-5, VFB 0.6 V (KiCad: adjustable 0.6-5.5 V). The DBV package has no PG pin. Pins: 1 EN, 2 GND, 3 SW, 4 VIN, 5 FB | C141836 | https://www.lcsc.com/product-detail/C141836.html ; KiCad Regulator_Switching:TLV62569DBV |
| 5 | LAN8720A-CP-TR | VERIFIED | LAN8720A-CP-TR (0 to 85 °C). Industrial alternate: LAN8720AI-CP-TR, C17146 | 10/100 RMII PHY, QFN-24 4x4, 1.6-3.6 V VDDIO (strap answers below the table) | C45223 | https://www.lcsc.com/product-detail/C45223.html ; https://ww1.microchip.com/downloads/en/DeviceDoc/LAN8720A%20QFN%20Rev%20D%20Schematic%20Checklist.pdf |
| 6 | CP2102N-A02-GQFN24R | VERIFIED | CP2102N-A02-GQFN24R | USB 2.0 FS to UART, QFN-24 4x4 (answers below the table) | C969151 | https://www.lcsc.com/product-detail/C969151.html |
| 7 | USBLC6-2SC6 | VERIFIED, **but FAILS the ≤1 pF HS requirement** | For USB-HS: **TPD2EUSB30DRTR** (TI) | USBLC6-2SC6 I/O-GND capacitance is **3.5 pF max** (typ. around 2.5-3 pF per snippets, typ. UNVERIFIED). TPD2EUSB30: **0.7 pF typ**, 5.5 V working voltage (tolerates a short to VBUS), DRT-3 1x1 mm | USBLC6: C7519; TPD2EUSB30DRTR: C97502 (alt. TPD2EUSB30ADRTR C94934, 3.6 V working) | https://www.st.com/resource/en/datasheet/usblc6-2.pdf ; https://datasheet.lcsc.com/lcsc/1810231723_Texas-Instruments-TPD2EUSB30DRTR_C97502.pdf ; Espressif ≤1 pF: https://docs.espressif.com/projects/esp-hardware-design-guidelines/en/latest/esp32p4/schematic-checklist-esp32p4.html |
| 8 | MMDT3904-7-F | VERIFIED | MMDT3904-7-F | Dual NPN, 40 V VCEO, 200 mA, 200 mW, SOT-363 | C83572 | https://www.lcsc.com/product-detail/bipolar-transistors-bjt_diodes-incorporated-mmdt3904-7-f_C83572.html |
| 9a | AO3400A | VERIFIED | AO3400A | N-ch 30 V 5.7 A, RDS(on) 26 mΩ at 4.5 V / 48 mΩ at 2.5 V, SOT-23 | C20917 | https://www.lcsc.com/product-detail/C20917.html |
| 9b | AO3401A | VERIFIED | AO3401A (AOS) | P-ch -30 V -4 A, SOT-23 | C15127 | https://lcsc.com/product-detail/MOSFET_AOS_AO3401A_AO3401A_C15127.html |
| 10 | DM3AT-SF-PEJM5 | VERIFIED | DM3AT-SF-PEJM5 | microSD, push-push, detect switch (2 pins, closes when a card is inserted), 1.68 mm height | C114218 | https://www.lcsc.com/product-detail/SD-Card-Memory-Card-Connector_HRS-Hirose-DM3AT-SF-PEJM5_C114218.html |
| 11 | FH12-22S-0.5SH(55) | VERIFIED, **BOTTOM contact** | See the design-impacting findings. The Raspberry Pi itself uses **Amphenol F32Q-1A7H1-11022 (TOP contact)** | 22 pos, 0.5 mm, ZIF, SMT right-angle, 2.0 mm high, bottom contact | C597981 (presales / out of stock). F32Q-1A7H1-11022: C3169253 | https://www.digikey.com/en/products/detail/hirose-electric-co-ltd/FH12-22S-0-5SH-55/1110321 ; https://www.lcsc.com/product-detail/C3169253.html ; https://uk.farnell.com/amphenol-icc/f32q-1a7h1-11022/conn-r-a-ffc-fpc-22pos-1row-0/dp/3526754 |
| 12 | Molex 47053-1000 | VERIFIED | 47053-1000 | KK 254, 4-pos, 2.54 mm, vertical THT, polarized fan header. The KiCad fan-header footprint descr names this MPN | C240840 | https://lcsc.com/product-detail/Others_MOLEX_47053-1000_MOLEX-47053-1000_C240840.html |
| 13 | USB4105-GF-A | VERIFIED | USB4105-GF-A | USB 2.0 Type-C, 16 contacts, horizontal top-mount, 5 A / 48 V | C3020560 | https://www.lcsc.com/product-detail/usb-connectors_global-connector-technology-usb4105-gf-a_C3020560.html |
| 14 | PMEG4050EP,115 | VERIFIED | PMEG4050EP,115 | 40 V 5 A, SOD128. VF at 25 °C: 340 mV typ / 390 mV max at 1 A, 430 mV typ / 490 mV max at 5 A. **At 2.5 A about 0.37-0.38 V typ, about 0.43 V max** (interpolated between those points; there is no datasheet row at 2.5 A). That is about 1 W dissipation at 2.5 A | C96235 (JLCPCB) | https://assets.nexperia.com/documents/data-sheet/PMEG4050EP.pdf ; https://jlcpcb.com/partdetail/Nexperia-PMEG4050EP115/C96235 |
| 15 | MF-MSMF250-2 | **NOT FOUND** | **CORRECTED-TO MF-MSMF250/16X-2** | 1812, I_hold 2.5 A, I_trip 5.0 A, **16 V** (≥6 V OK), I_max 100 A, R ≈ 15 mΩ. This part replaced MF-MSMF250/16-2 (Bourns PCN MF1205) | C210838 | https://www.lcsc.com/product-detail/C210838.html ; https://www.bourns.com/docs/product-datasheets/mf-msmf.pdf |
| 16 | BLM18PG221SN1D | VERIFIED | BLM18PG221SN1D | 220 Ω ±25 % at 100 MHz, 1.4 A, 0.1 Ω DCR max, 0603 | C80165 | https://www.lcsc.com/product-detail/Ferrite-Beads_Murata-Electronics-BLM18PG221SN1D_C80165.html |
| 17 | XAL5030-222MEC | VERIFIED | XAL5030-222MEC | 2.2 µH ±20 %, Isat 9.2 A (30 % drop), Irms 9.7 A, DCR 14.5 mΩ. Plenty of margin for 3 A | C920280 (JLCPCB) | https://jlcpcb.com/partdetail/Coilcraft-XAL5030222MEC/C920280 ; https://www.coilcraft.com/getmedia/49bc46c8-4b2c-45b9-9b6c-2eaa235ea698/xal50xx.pdf |
| 18 | 2.2 µH for TLV62569 at ≤1.5 A | VERIFIED (proposed part) | **Murata DFE252012F-2R2M=P2** | 2.2 µH ±20 %, 2.5x2.0x1.2 mm, Irms 2.3 A, Isat 3.3 A, DCR 82 mΩ max | C576403 | https://www.lcsc.com/product-detail/C576403.html |
| 18b | Sunlord SWPA3015S2R2MT | Exists; specs partly UNVERIFIED | (alternate) | 2.2 µH ±20 %, 3x3x1.5 mm, "2 A" rating. DCR and Isat conflict between sources (78 vs 780 mΩ), so check the datasheet | C43389 | https://jlcpcb.com/partdetail/Sunlord-SWPA3015S2R2MT/C43389 |
| 19a | Epson X1E000021017711 | VERIFIED (availability risk) | — | TSX-3225, 40 MHz, ±10 ppm, **CL 9 pF**, **ESR 40 Ω max**. One distributor lists it "Discontinued". Not found on LCSC | — | https://uk.rs-online.com/web/p/crystal-units/1732302 ; https://www.axel-gl.com/en/asone/d/63-4931-77/ |
| 19b | CTS 402F4001XIAR | VERIFIED (**recommended**) | 402F4001XIAR | 40 MHz, ±10 ppm, **CL 10 pF**, **ESR 60 Ω**. **This is a 2016 package (2.0x1.6), not 3225** | C5508101 | https://www.lcsc.com/product-detail/crystals_cts-402f4001xiar_C5508101.html |
| 20 | ABM8-25.000MHZ-B2-T | VERIFIED | Keep it, or better YXC X322525MOB4SI (see findings) | 25 MHz, **CL 18 pF**, ±20 ppm tolerance, **±50 ppm stability** (-20 to +70 °C), ESR 50 Ω, 3225 | C596899 (JLCPCB). Alt. X322525MOB4SI: C9006 (±10 ppm tol / ±20 ppm stab, CL 12 pF, -40 to 85 °C) | https://jlcpcb.com/partdetail/AbraconLLC-ABM8_25_000MHZ_B2T/C596899 ; https://www.lcsc.com/product-detail/C9006.html |
| 21 | PTS810SJM250SMTRLFS | VERIFIED | PTS810SJM250SMTRLFS | SPST-NO SMT, 4.2x3.2x2.5 mm, 250 gf nominal (snippets vary), 50 mA 16 V, J-lead | C116501 | https://www.lcsc.com/product-detail/C116501.html |
| 22a | Würth 150060GS75000 | VERIFIED | 150060GS75000 | Green 0603, 520-525 nm, VF about 3.2 V at 20 mA | C5252984 | https://www.lcsc.com/product-detail/Light-Emitting-Diodes-LED_Wurth-Elektronik-150060GS75000_C5252984.html |
| 22b | Würth 150060RS75000 | VERIFIED | 150060RS75000 | Red 0603, 625 nm, VF about 2.0 V at 20 mA | C3030991 | https://www.lcsc.com/product-detail/Light-Emitting-Diodes-LED_Wurth-Elektronik-150060RS75000_C3030991.html |
| 23 | SM02B-SRSS-TB(LF)(SN) | VERIFIED | SM02B-SRSS-TB(LF)(SN) | JST SH 1.0 mm, 2-pos, side entry, SMT, 1 A 50 V; mates with SHR-02V-S | C160402 | https://www.lcsc.com/product-detail/C160402.html |
| 24 | Würth 61302421121 | VERIFIED | 61302421121 | WR-PHD 2x12 (24 pos), 2.54 mm, straight THT, unshrouded | not found on LCSC | https://www.newark.com/wurth-elektronik/61302421121/board-to-board-connector-vertical/dp/20X0994 ; https://www.digikey.com/en/products/detail/w%C3%BCrth-elektronik/61302421121/4846869 |
| 25 | TPD4E05U06DQAR | VERIFIED | TPD4E05U06DQAR | 4-ch, 0.5 pF, 5.5 V working, ±12 kV contact, USON-10 2.5x1.0 (KiCad pinout in B-section notes) | C138714 | https://www.lcsc.com/product-detail/C138714.html |
| 26a | CL05B104KO5NNNC | VERIFIED | — | 100 nF 16 V X7R ±10 % 0402 | C1525 | https://www.lcsc.com/product-detail/C1525.html |
| 26b | CL05B103KB5NNNC | VERIFIED | — | 10 nF 50 V X7R 0402 | C15195 | https://www.lcsc.com/product-detail/C15195.html |
| 26c | CL05A105KA5NQNC | VERIFIED | — | 1 µF 25 V X5R ±10 % 0402 | C52923 | https://jlcpcb.com/partdetail/C52923 |
| 26d | CL05A106MQ5NUNC | VERIFIED | — | 10 µF 6.3 V X5R ±20 % 0402. The thickness code "5" means 0.50 mm (the same code is listed as 0.50±0.05 mm on CL05A475MP5NRNC). Expect heavy DC-bias derating at 3.3 V | C15525 | https://www.lcsc.com/product-detail/C15525.html |
| 26e | CL05A475MP5NRNC | VERIFIED | — | 4.7 µF 10 V X5R ±20 % 0402, T = 0.50±0.05 mm | C23733 | https://jlcpcb.com/partdetail/CL05A475MP5NRNC/C23733 |
| 26f | CL05C220JB5NNNC | VERIFIED | — | 22 pF 50 V C0G ±5 % 0402 | C70464 | https://www.lcsc.com/product-detail/Multilayer-Ceramic-Capacitors-MLCC-SMD-SMT_Samsung-Electro-Mechanics-CL05C220JB5NNNC_C70464.html |
| 26g | CL05C120JB5NNNC | VERIFIED (exists) | — | 12 pF 50 V C0G ±5 % 0402 | LCSC C# not found | https://www.mouser.com/ProductDetail/Samsung-Electro-Mechanics/CL05C120JB5NNNC?qs=349EhDEZ59qBxmY25XcLQg%3D%3D |
| 26h | CL05B471KB5NNNC | VERIFIED | — | 470 pF 50 V X7R 0402 | C26412 | https://www.lcsc.com/product-detail/Multilayer-Ceramic-Capacitors-MLCC-SMD-SMT_SAMSUNG_CL05B471KB5NNNC_470pF-471-10-50V_C26412.html |
| 26i | CL05B332KB5NNNC | VERIFIED | — | 3.3 nF 50 V X7R 0402 | C26404 | https://lcsc.com/product-detail/Multilayer-Ceramic-Capacitors-MLCC-SMD-SMT_Samsung-Electro-Mechanics_C26404.html |
| 26j | CL21A226MQQNNNE | VERIFIED | — | 22 µF 6.3 V X5R ±20 % 0805 | C5674 | https://lcsc.com/product-detail/Multilayer-Ceramic-Capacitors-MLCC-SMD-SMT_Samsung-Electro-Mechanics-CL21A226MQQNNNE_C5674.html |
| 26k | CL21A106KAYNNNE | VERIFIED | — | 10 µF 25 V X5R ±10 % 0805, T 1.25 mm | C15850 | https://www.lcsc.com/product-detail/C15850.html |
| 26l | CL21A476MQYNNNE | VERIFIED | — | 47 µF 6.3 V X5R ±20 % 0805 | C16780 | https://jlcpcb.com/partdetail/17464-CL21A476MQYNNNE/C16780 |
| 26m | Yageo RC0402FR-07xxxL series | VERIFIED pattern | — | RC0402 + F(1 %) + R(reel) + 07(7") + value + L. Spot checks: RC0402FR-0710KL = C60490, RC0402FR-0749R9L = C87044, RC0402FR-0712K1L (12.1 k, TME), RC0402FR-071KL = C106235. All listed values are standard E24/E96 values | see left | https://www.lcsc.com/product-detail/C60490.html ; https://www.lcsc.com/product-detail/C87044.html ; https://www.tme.com/us/en-us/details/rc0402fr-0712k1l/smd-resistors/yageo/ |
| 26n | RC0402JR-070RL | VERIFIED | — | 0 Ω jumper 0402, 1 A | C60485 | https://www.lcsc.com/product-detail/Chip-Resistor-Surface-Mount_YAGEO-RC0402JR-070RL_C60485.html |

### Item 3: TPS62130 pin questions
- **FSW:** Low (GND) selects 2.5 MHz, the full frequency. High selects 1.25 MHz, half frequency. The datasheet says the part must **start with FSW = Low** to limit inrush current. For 1.25 MHz, tie FSW to **VOUT or PG**, not to VIN. Source: TI datasheet snippet and TPS62130EVM guide.
- **DEF:** Low = nominal VOUT. High = nominal + 5 %. Source: TI SLVA489 "Voltage Margining Using the TPS62130".
- **VFB = 0.8 V**, with VOUT = 0.8 V × (1 + R1/R2). Keep R2 ≤ 120 kΩ so at least about 5 µA flows in the divider. Source: TI SLYT469 and the datasheet.
- KiCad `Regulator_Switching:TPS62130` pins: 1-3 SW, 4 PG, 5 FB, 6 GND, 7 FSW, 8 DEF, 9 SS/TR, 10-12 VIN, 13 EN, 14 VOS, 15-16 GND, 17 EP (GND). Its footprint is `VQFN-16-1EP_3x3mm_P0.5mm_EP1.68x1.68mm_ThermalVias`.

### Item 5: LAN8720A strap and termination questions
- **nINTSEL (pin 2, LED2/nINTSEL)** is latched at power-up and on the rising edge of nRST. The pin has an internal pull-up, so the default is nINTSEL = 1, which gives nINT mode (REF_CLK In, 50 MHz fed into XTAL1/CLKIN). **Pulling it low with an external pull-down (nINTSEL = 0) selects REF_CLK Out mode.** In that mode a 25 MHz crystal is multiplied to 50 MHz, output on pin 14 nINT/REFCLKO, and the interrupt is not available. The recommended strap is **10 kΩ to GND**. With the pull-down fitted, LED2 becomes **active-high**, so wire LED2 → resistor → LED anode, LED cathode → GND, with the 10 k pull-down in parallel. Sources: LAN8720A datasheet snippets and the Microchip schematic checklist.
- A related strap, not asked about: **LED1/REGOFF (pin 3)** has an internal pull-down. The default (low) keeps the internal 1.2 V regulator ON and makes LED1 active-high. Pulling it high disables the regulator. Source: datasheet section on REGOFF and LED polarity (manualslib copy).
- **RBIAS = 12.1 kΩ, 1 %** to GND. Source: Microchip "LAN8720A QFN Rev D Schematic Checklist".
- **TXP/TXN/RXP/RXN each need a 49.9 Ω 1 % pull-up to a 3.3 V analog rail** (VDDA, derived from +3.3 V). The PHY-side magnetics center taps (TCT and RCT) also go to that rail and are bypassed. The checklist also suggests optional DNP small caps (≤22 pF) from each line to GND. Source: Microchip schematic checklist.
- KiCad `Interface_Ethernet:LAN8720A` uses the footprint `VQFN-24-1EP_4x4mm_P0.5mm_EP2.5x2.5mm_ThermalVias`.

### Item 6: CP2102N questions
- **RSTb:** use a **1 kΩ pull-up to VIO**, or to VDD if VIO is tied to VDD. Source: CP2102N datasheet snippet.
- **Self-powered:** tie VREGIN and VDD together to the external 3.3 V, which bypasses the internal regulator; VIO also goes to 3.3 V. Sense USB VBUS through a divider: **22.1 kΩ from USB VBUS to the VBUS pin, and 47.5 kΩ from the VBUS pin to GND**. At 5 V this gives about 3.4 V. The divider is required because the VBUS pin abs-max is VIO + 2.5 V and VIH is VIO − 0.6 V. Source: SiLabs KB article "Self powered CP2102N, VBUS pin connection, and VBUS voltage divider".
- KiCad `Interface_USB:CP2102N-Axx-xQFN24` uses the footprint `QFN-24-1EP_4x4mm_P0.5mm_EP2.6x2.6mm`. Pins: 3 D+, 4 D-, 5 VIO, 6 VDD, 7 VREGIN, 8 VBUS, 9 RSTb, 20 RXD, 21 TXD, 19 RTS, 23 DTR.

### Item 7: USB-HS ESD replacement
- Recommended part: **TPD2EUSB30DRTR**, 0.7 pF typ, 2 lines.
- KiCad symbol: `Power_Protection:TPD2EUSB30`. Pins: **1 = D+, 2 = D-, 3 = GND**. Footprint: `Package_TO_SOT_SMD:Texas_DRT-3` (confirmed to exist).
- Alternative that needs no new part: use two of the four channels of **TPD4E05U06DQAR** (0.5 pF).
- USBLC6-2SC6 remains fine for the **CP2102N USB full-speed port**.

---

## 2. Pinout answers

### B1. RJ45 with magnetics (HanRun HR911105A)
**Recommended MPN: HanRun HR911105A**, LCSC C12074. It is 10/100 with integrated magnetics, 2 LEDs, tab-down and THT.
- KiCad symbol: `Connector:RJ45_Hanrun_HR911105A_Horizontal`. Its datasheet link is the LCSC HR911105A PDF.
- Footprint: `Connector_RJ:RJ45_Hanrun_HR911105A_Horizontal`. The pads are 1-12 plus 2× SH, which matches the symbol.
- I cross-checked the pin functions against two independent libraries: the ODRI master-board Eagle library and the duodyne KiCad symbol. They agree with the official symbol.

| Pin | Function | Notes |
|---|---|---|
| 1 | TD+ | to LAN8720A TXP (pin 21) |
| 2 | TD− | to TXN (pin 20) |
| 3 | RD+ | to RXP (pin 23) |
| 4 | TCT (TX center tap, PHY side) | to 3.3 V analog, bypassed |
| 5 | RCT (RX center tap, PHY side) | to 3.3 V analog, bypassed |
| 6 | RD− | to RXN (pin 22) |
| 7 | NC | — |
| 8 | GND for the Bob-Smith termination (75 Ω network plus 1000 pF, inside the jack) | chassis/GND |
| 9 | Green LED **anode** | official symbol: triangle from 9 to 10 |
| 10 | Green LED **cathode** | |
| 11 | Yellow LED **cathode** | |
| 12 | Yellow LED **anode** | |
| SH | Shield (2 pads) | chassis |

**RJ45-with-magnetics symbols in the official `Connector.kicad_symdir`:**
- RJ45_Abracon_ARJP11A-MASA-B-A-EMU2
- RJ45_Amphenol_RJMG1BD3B8K1ANR
- RJ45_Bel_SI-60062-F
- RJ45_Bel_V895-1001-AW
- RJ45_Halo_HFJ11-x2450E-LxxRL (with LEDs)
- RJ45_Halo_HFJ11-x2450ERL
- RJ45_Halo_HFJ11-x2450HRL
- **RJ45_Hanrun_HR911105A_Horizontal**
- RJ45_JK00177 (Pulse, GbE PoE)
- RJ45_JK0654219 (Pulse, GbE)
- RJ45_Kycon_G7LX-A88S7-BP-GY
- RJ45_Pulse_JXD6-0001NL
- RJ45_RB1-125B8G1A (UDE, GbE)
- RJ45_Wuerth_74980111211
- RJ45_Wuerth_7499010121A
- RJ45_Wuerth_7499010211A
- RJ45_Wuerth_7499151120 (dual)
- Generic symbols also exist: 8P8C*, RJ45, RJ45_LED*, RJ45_Shielded*.

HR911105A is the most suitable because it is LCSC-stocked, 10/100, has 2 LEDs, and its symbol and footprint pair are both official.

### B2. Raspberry Pi 22-pin 0.5 mm camera connector
Source: raspberrypi/documentation, `documentation/asciidoc/accessories/camera/advanced.adoc`, "Camera connector pinout (22-Pin)". It applies to the Pi Zero series, the CM IO boards and Pi 5. The document names the compatible connector as Amphenol F32Q-1A7H1-11022, which is top contact. Signal direction is from the Pi's side. SCL and SDA are pulled up to 3.3 V on the Pi. CAM_IO0 is typically an active-high power enable.

| Pin | Name | Pin | Name |
|---|---|---|---|
| 1 | GND | 12 | CAM_DP2 |
| 2 | CAM_DN0 | 13 | GND |
| 3 | CAM_DP0 | 14 | CAM_DN3 |
| 4 | GND | 15 | CAM_DP3 |
| 5 | CAM_DN1 | 16 | GND |
| 6 | CAM_DP1 | 17 | CAM_IO0 (e.g. power enable, 3.3 V) |
| 7 | GND | 18 | CAM_IO1 (e.g. clock/LED, 3.3 V) |
| 8 | CAM_CN (clock −) | 19 | GND |
| 9 | CAM_CP (clock +) | 20 | SCL (3.3 V) |
| 10 | GND | 21 | SDA (3.3 V) |
| 11 | CAM_DN2 | 22 | 3V3 (supply output) |

**Pi 5 display:**
- Pi 5 has 2 × "mini 22-pin, 0.5 mm pitch, combined CSI (camera)/DSI (display) ports". Source: `documentation/asciidoc/computers/raspberry-pi/introduction.adoc`.
- A Raspberry Pi forum answer (thread t=364068, seen only as a search snippet because the forum is blocked) says the Pi 5 DSI pinout is **the same as the CM4IO CAM1 22-pin connector**. That means the pin positions are identical to the table above, with lanes and clock driven by the Pi in DSI mode.
- I did **not** verify whether the CM4 IO board's separate DISP1 connector uses the same mapping.

For the ESP32-P4 (2-lane CSI), connect D0, D1 and the clock. Leave D2/D3 unconnected or grounded as layout dictates.

### B3. ESP32-P4 JTAG, 32 kHz crystal, GPIO34
**Pad JTAG.** Sources: ESP-IDF v5.5 `components/soc/esp32p4/register/hw_ver3/soc/io_mux_reg.h` (FUNC_GPIO2_MTCK ... FUNC_GPIO5_MTDO = function 0) and `docs/en/api-guides/jtag-debugging/esp32p4.inc`.

| Signal | GPIO |
|---|---|
| MTCK (TCK) | GPIO2 |
| MTDI (TDI) | GPIO3 |
| MTMS (TMS) | GPIO4 |
| MTDO (TDO) | GPIO5 |

- By default JTAG is routed to the built-in USB-Serial-JTAG on GPIO24 (D−) and GPIO25 (D+), not to the pads.
- Pad JTAG needs an eFuse: either DIS_USB_JTAG, or JTAG_SEL_ENABLE plus the GPIO34 strap.

**32 kHz crystal:** **XTAL_32K_N = GPIO0**, **XTAL_32K_P = GPIO1**.
- Source: the ESP-IDF `esp_hal_clock/esp32p4/include/hal/clk_tree_ll.h` comment "XTAL_32K_N (i.e. GPIO0)".
- Source: an ESP32-P4 datasheet search snippet (GPIO0 = XTAL_32K_N, GPIO1 = XTAL_32K_P).

**GPIO34 strap:**
- GPIO34 selects the JTAG signal source, and **only after the JTAG_SEL_ENABLE eFuse is burned**. Low at reset selects pad JTAG on GPIO2-5. High selects USB_SERIAL_JTAG. Without that eFuse the level has no effect.
- Sources: ESP-IDF `configure-other-jtag.rst` with `|jtag-sel-gpio| = GPIO34`; esptool `efuse_defs/esp32p4.yaml` ("strapping gpio34").
- Caveat: esptool `esp32p4_v3.0.yaml` says "gpio25" and the ESP-IDF efuse CSV says "gpio15". These look like doc errors (see esptool issue #1078), and the ESP-IDF docs and datasheet say GPIO34.
- The other straps: GPIO35 low means download boot (it has an internal pull-up), and GPIO36 must be high for download. GPIO35 = 0 with GPIO36 = 0 is invalid. The full strap set is GPIO34-38. Source: esptool boot-mode-selection docs for P4.
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

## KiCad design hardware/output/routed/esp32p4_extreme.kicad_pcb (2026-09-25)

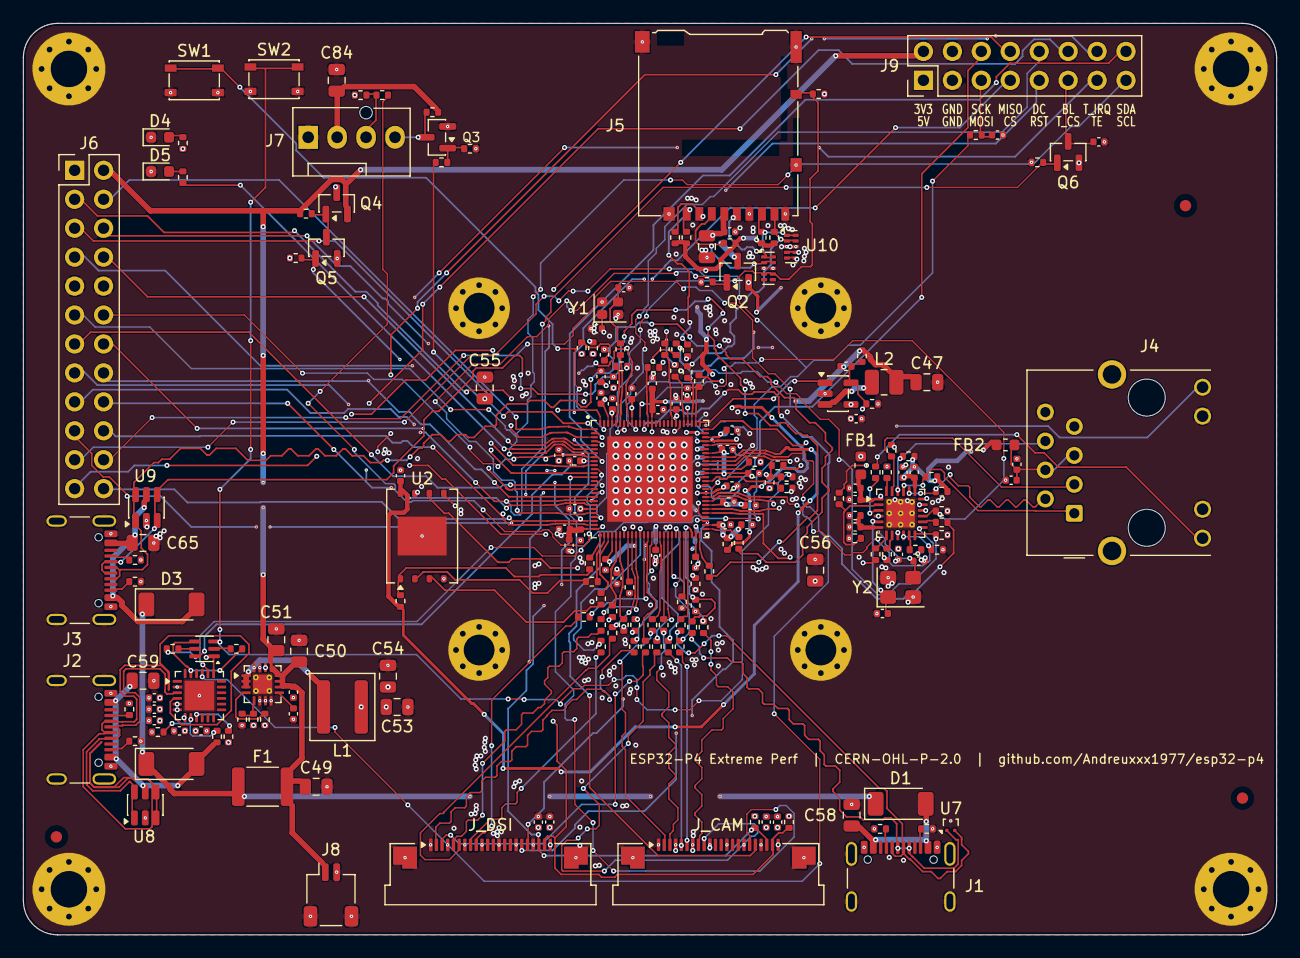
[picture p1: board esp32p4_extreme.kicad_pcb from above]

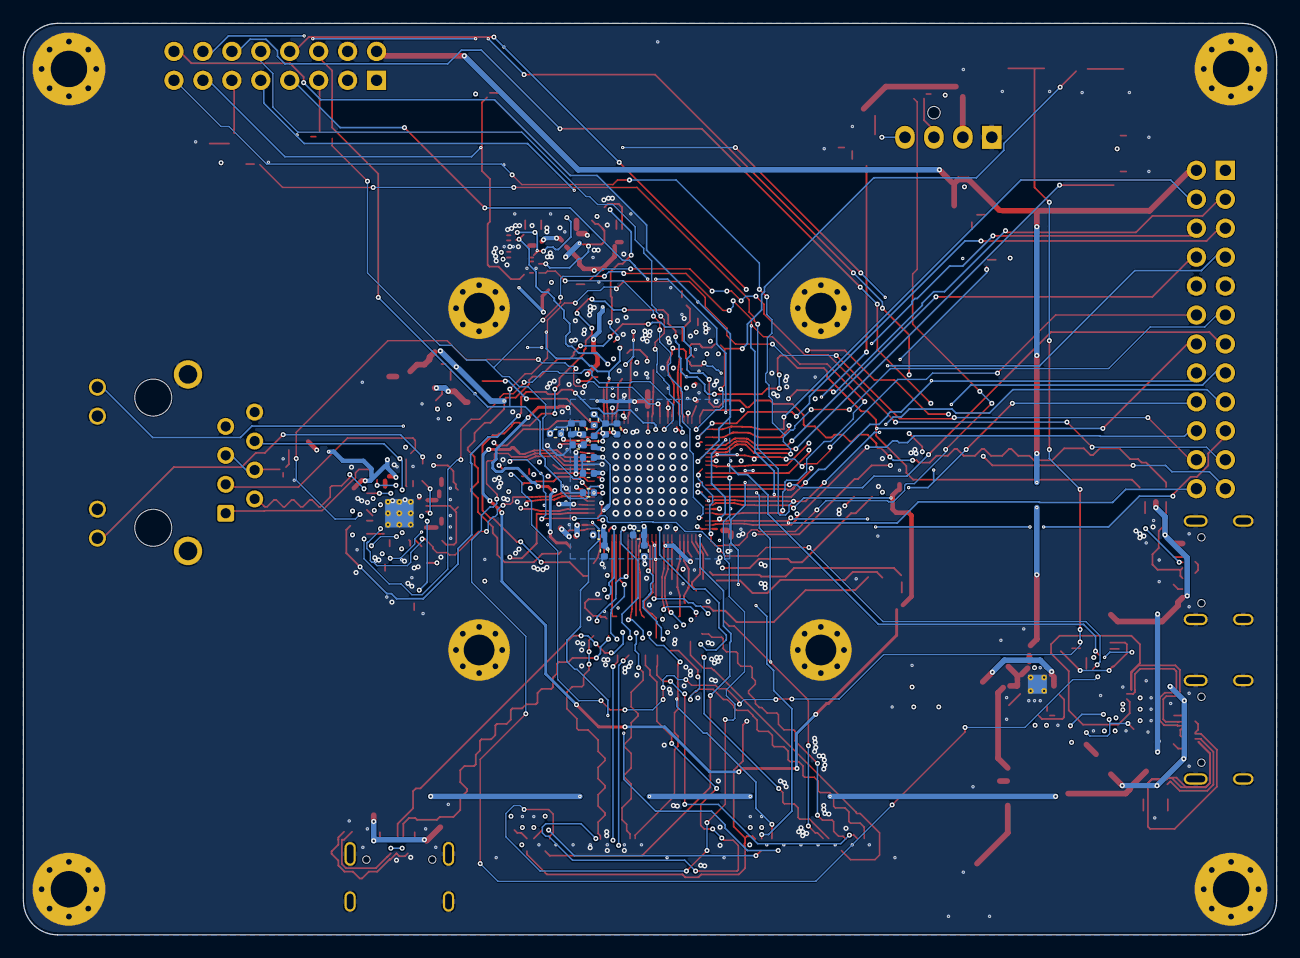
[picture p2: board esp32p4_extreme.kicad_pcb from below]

Board: 4 copper layers, 110.0 x 80.0 mm, 234 parts (15 on the bottom side), 175 nets.

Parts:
C1, C3, C4, C7, C10, C13, C15, C17, C19, C21, C27, C29, C32, C34, C35, C37, C39, C40, C45, C52, C60, C62, C64, C70, C71, C72, C75, C79, C81, C83, C86: 100nF; C_0402_1005Metric
C2, C6, C28, C31, C33, C41: 10uF; C_0402_1005Metric
C5, C8, C11, C16, C18, C20, C22, C23, C24, C25, C26, C30, C36, C42, C61, C63, C68, C69, C73, C80, C82: 1uF; C_0402_1005Metric
C9, C12, C38, C76: 10nF; C_0402_1005Metric
C14, C46: 4.7uF; C_0402_1005Metric
C43, C44: 12pF; C_0402_1005Metric
C47, C53, C54: 22uF; C_0805_2012Metric
C48: 22pF; C_0402_1005Metric
C49, C50, C51, C58, C59, C65, C78, C84: 10uF; C_0805_2012Metric
C55, C56: 47uF; C_0805_2012Metric
C57: 3.3nF; C_0402_1005Metric
C66, C67: 18pF; C_0402_1005Metric
C74: 470pF; C_0402_1005Metric
C77, C85: 10pF; C_0402_1005Metric
D1, D2, D3: PMEG4050EP; D_SOD-128
D4: Green; LED_0603_1608Metric
D5: Red; LED_0603_1608Metric
F1: PTC 2.5A; Fuse_1812_4532Metric
FB1, FB2: 220R@100MHz; L_0603_1608Metric
FID1, FID2, FID3: Fiducial; Fiducial_1mm_Mask2mm
H1, H2, H3, H4: M2.5; MountingHole_2.7mm_M2.5_Pad_Via
H5, H6, H7, H8: M3; MountingHole_3.2mm_M3_Pad_Via
J1, J2, J3: USB-C; USB_C_Receptacle_GCT_USB4105-xx-A_16P_TopMnt_Horizontal
J4: RJ45 MagJack; RJ45_Hanrun_HR911105A_Horizontal
J5: microSD; microSD_HC_Hirose_DM3AT-SF-PEJM5
J6: 2x12 header; PinHeader_2x12_P2.54mm_Vertical
J7: Fan 4P; FanPinHeader_1x04_P2.54mm_Vertical
J8: JST-SH 2P; JST_SH_SM02B-SRSS-TB_1x02-1MP_P1.00mm_Horizontal
J9: 2x8 header; PinHeader_2x08_P2.54mm_Vertical
J_CAM: FPC 22P 0.5mm; Amphenol_F32Q-1A7x1-11022_1x22-1MP_P0.5mm_Horizontal
J_DSI: FPC 22P 0.5mm; Amphenol_F32Q-1A7x1-11022_1x22-1MP_P0.5mm_Horizontal
L1: 2.2uH; L_Coilcraft_XAL5030-XXX
L2: 2.2uH; L_1008_2520Metric
Q1: MMDT3904; SOT-363_SC-70-6
Q2, Q4, Q6: AO3401A; SOT-23
Q3, Q5: AO3400A; SOT-23
R1, R2, R3, R11, R12, R13, R14, R15, R16, R17, R18, R28, R29, R59, R60, R61, R62, R63, R64, R72, R73, R74, R75, R76, R77, R78, R79, R80, R81, R82, R83: 0R; R_0402_1005Metric
R4, R5: 4.02k; R_0402_1005Metric
R6, R7, R8, R19, R35, R36, R49, R50, R51, R70, R71, R88, R90, R91: 10k; R_0402_1005Metric
R9, R25, R34, R92, R93: 1k; R_0402_1005Metric
R10: 1M; R_0402_1005Metric
R20, R21: 499k; R_0402_1005Metric
R22: 75k; R_0402_1005Metric
R23: 24k; R_0402_1005Metric
R24, R87, R89, R95: 100k; R_0402_1005Metric
R26, R27, R30, R31, R37, R38: 5.1k; R_0402_1005Metric
R32: 22.1k; R_0402_1005Metric
R33: 47.5k; R_0402_1005Metric
R39, R40, R41, R42, R43, R44, R45, R46, R94: 22; R_0402_1005Metric
R47: 33; R_0402_1005Metric
R48: 12.1k; R_0402_1005Metric
R52: 1.5k; R_0402_1005Metric
R53, R54, R55, R56: 49.9; R_0402_1005Metric
R57, R58: 330; R_0402_1005Metric
R65, R66, R67, R68, R69: 51k; R_0402_1005Metric
R84, R85: 2.2k; R_0402_1005Metric
R86: 100; R_0402_1005Metric
SW1, SW2: Tactile; SW_SPST_PTS810
U1: ESP32-P4NRW32X; ESP32-P4
U2: W25Q256JV 32MB; WSON-8-1EP_8x6mm_P1.27mm_EP3.4x4.3mm
U3: TPS62130; VQFN-16-1EP_3x3mm_P0.5mm_EP1.68x1.68mm_ThermalVias
U4: TLV62569; SOT-23-5
U5: LAN8720A; VQFN-24-1EP_4x4mm_P0.5mm_EP2.5x2.5mm_ThermalVias
U6: CP2102N; QFN-24-1EP_4x4mm_P0.5mm_EP2.6x2.6mm
U7: TPD2EUSB30; Texas_DRT-3
U8, U9: USBLC6-2SC6; SOT-23-6
U10, U11: TPD4E05U06; USON-10_2.5x1.0mm_P0.5mm
Y1: 40MHz 10ppm; Crystal_SMD_2016-4Pin_2.0x1.6mm
Y2: 25MHz; Crystal_SMD_3225-4Pin_3.2x2.5mm

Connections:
+3V3: C1.1, C2.1, C3.1, C19.1, C20.1, C27.1, C28.1, C32.1, C33.1, C37.1, C38.1, C39.1, C46.1, C53.1, C54.1, C55.1, C56.1, C60.1, C61.1, C62.1, C63.1, C64.1, C72.1, C80.1, C81.1, C82.1, C83.1, FB1.1, J6.1, J9.1, J_CAM.22, J_DSI.22, L1.2, Q2.2, Q6.2, R1.1, R2.1, R6.1, R7.1, R8.1, R22.1, R24.1, R25.1, R34.1, R51.1, R52.1, R71.1, R84.1, R85.1, R90.1, R91.1, U1.9, U1.21, U1.62, U1.75, U1.77, U1.96, U1.101, U3.14, U4.4, U5.9, U6.5, U6.6, U6.7
BOOT_BTN: Q1.3, R9.2, SW2.1
BUCK_FB: R22.2, R23.1, U3.5
BUCK_PG: R24.2, U3.4
BUCK_SS: C57.1, U3.9
BUCK_SW: L1.1, U3.1, U3.2, U3.3
CAM_CLK_N: J_CAM.8, R77.2
CAM_CLK_P: J_CAM.9, R76.2
CAM_D0_N: J_CAM.2, R73.2
CAM_D0_P: J_CAM.3, R72.2
CAM_D1_N: J_CAM.5, R75.2
CAM_D1_P: J_CAM.6, R74.2
CAM_EN: J_CAM.17, U1.13
CAM_IO1: J_CAM.18, U1.14
CHIP_PU: C42.1, Q1.6, R6.2, SW1.1, U1.103
CP_DTR: Q1.4, R35.1, U6.23
CP_RST_N: R34.2, U6.9
CP_RTS: Q1.1, R36.1, U6.19
CP_VBUS_SENSE: R32.2, R33.1, U6.8
CSI_CLK_N: R77.1, U1.45
CSI_CLK_P: R76.1, U1.44
CSI_D0_N: R73.1, U1.42
CSI_D0_P: R72.1, U1.43
CSI_D1_N: R75.1, U1.46
CSI_D1_P: R74.1, U1.47
CSI_REXT: R5.1, U1.48
DISP_CLK_N: J_DSI.8, R83.2
DISP_CLK_P: J_DSI.9, R82.2
DISP_D0_N: J_DSI.2, R79.2
DISP_D0_P: J_DSI.3, R78.2
DISP_D1_N: J_DSI.5, R81.2
DISP_D1_P: J_DSI.6, R80.2
DSI_CLK_N: R83.1, U1.37
DSI_CLK_P: R82.1, U1.38
DSI_D0_N: R79.1, U1.40
DSI_D0_P: R78.1, U1.39
DSI_D1_N: R81.1, U1.36
DSI_D1_P: R80.1, U1.35
DSI_REXT: R4.1, U1.34
ETH_CT: C75.1, C76.1, FB2.2, J4.4, J4.5
ETH_LED_LINK_A: J4.9, R57.2
ETH_LED_SPEED_A: J4.12, R58.2
ETH_MDC: U1.61, U5.13
ETH_MDIO: R52.2, U1.95, U5.12
ETH_PHY_RST_N: R51.2, U1.94, U5.15
ETH_RX_N: J4.6, R56.1, U5.22
ETH_RX_P: J4.3, R55.1, U5.23
ETH_TX_N: J4.2, R54.1, U5.20
ETH_TX_P: J4.1, R53.1, U5.21
FAN_5V: C84.1, J7.2, Q4.3, R88.2
FAN_EN: Q5.1, R90.2, U1.12
FAN_HS_G: Q4.1, Q5.3, R89.2
FAN_PWM: R86.1, U1.10
FAN_PWM_G: Q3.1, R86.2, R87.1
FAN_PWM_OD: J7.4, Q3.3, R88.1
FAN_TACH: R92.2, U1.11
FAN_TACH_RAW: J7.3, R91.2, R92.1
FLASH_CK: R17.1, U1.32
FLASH_CK_M: R17.2, U2.6
FLASH_CS: R13.1, U1.27
FLASH_CS_M: R13.2, R19.2, U2.1
FLASH_D: R18.1, U1.33
FLASH_D_M: R18.2, U2.5
FLASH_HOLD: R16.1, U1.31
FLASH_HOLD_M: R16.2, U2.7
FLASH_Q: R14.1, U1.28
FLASH_Q_M: R14.2, U2.2
FLASH_WP: R15.1, U1.29
FLASH_WP_M: R15.2, U2.3
GND: C1.2, C2.2, C3.2, C4.2, C5.2, C6.2, C7.2, C8.2, C9.2, C10.2, C11.2, C12.2, C13.2, C14.2, C15.2, C16.2, C17.2, C18.2, C19.2, C20.2, C21.2, C22.2, C23.2, C24.2, C25.2, C26.2, C27.2, C28.2, C29.2, C30.2, C31.2, C32.2, C33.2, C34.2, C35.2, C36.2, C37.2, C38.2, C39.2, C40.2, C41.2, C42.2, C43.2, C44.2, C45.2, C46.2, C47.2, C49.2, C50.2, C51.2, C52.2, C53.2, C54.2, C55.2, C56.2, C57.2, C58.2, C59.2, C60.2, C61.2, C62.2, C63.2, C64.2, C65.2, C66.2, C67.2, C68.2, C69.2, C70.2, C71.2, C72.2, C73.2, C74.2, C75.2, C76.2, C77.2, C78.2, C79.2, C80.2, C81.2, C82.2, C83.2, C84.2, C85.2, C86.2, D4.1, D5.1, H1.1, H2.1, H3.1, H4.1, H5.1, H6.1, H7.1, H8.1, J1.A1, J1.A12, J1.B1, J1.B12, J1.SH, J2.A1, J2.A12, J2.B1, J2.B12, J2.SH, J3.A1, J3.A12, J3.B1, J3.B12, J3.SH, J4.8, J4.10, J4.11, J4.SH, J5.6, J5.9, J5.SH, J6.9, J6.10, J7.1, J8.2, J8.MP, J9.3, J9.4, J_CAM.1, J_CAM.4, J_CAM.7, J_CAM.10, J_CAM.13, J_CAM.16, J_CAM.19, J_CAM.MP, J_DSI.1, J_DSI.4, J_DSI.7, J_DSI.10, J_DSI.13, J_DSI.16, J_DSI.19, J_DSI.MP, Q3.2, Q5.2, R4.2, R5.2, R10.2, R21.2, R23.2, R26.2, R27.2, R30.2, R31.2, R33.2, R37.2, R38.2, R48.2, R49.2, R50.2, R70.2, R87.2, R95.2, SW1.2, SW2.2, U1.105, U2.4, U2.9, U3.6, U3.7, U3.8, U3.15, U3.16, U3.17, U4.2, U5.25, U6.2, U6.25, U7.3, U8.2, U9.2, U10.3, U10.8, U11.3, U11.8, Y1.2, Y1.4, Y2.2, Y2.4
GPIO0: J6.3, U1.104
GPIO1: J6.4, U1.1
GPIO2: J6.5, U1.2
GPIO3: J6.6, U1.3
GPIO4: J6.7, U1.4
GPIO5: J6.8, U1.5
GPIO16: J6.15, J9.12, U1.17
GPIO17: J6.16, J9.13, U1.18
GPIO18: J6.17, Q6.1, R95.1, U1.19
GPIO19: J6.18, J9.14, U1.20
GPIO22: J6.19, J9.7, U1.24
GPIO23: J6.20, J9.8, U1.25
GPIO32: J6.21, R94.1, U1.63
GPIO33: J6.22, J9.6, U1.64
GPIO53: J6.23, J9.9, U1.97
GPIO54: J6.24, J9.10, U1.98
HP_SW: L2.1, U4.3
I2C_SCL: J6.12, J9.16, J_CAM.20, J_DSI.20, R85.2, U1.8
I2C_SDA: J6.11, J9.15, J_CAM.21, J_DSI.21, R84.2, U1.7
J1_CC1: J1.A5, R26.1
J1_CC2: J1.B5, R27.1
J2_CC1: J2.A5, R30.1
J2_CC2: J2.B5, R31.1
J3_CC1: J3.A5, R37.1
J3_CC2: J3.B5, R38.1
LCD_BL_PWM: J_DSI.18, U1.55
LCD_RST: J_DSI.17, U1.56
LCD_SPI_BL: C86.1, J9.11, Q6.3
LCD_SPI_SCK: C85.1, J9.5, R94.2
LED_PWR_A: D4.2, R25.2
LED_STATUS: R93.1, U1.6
LED_STATUS_A: D5.2, R93.2
LP_UART_RXD: J6.14, U1.16
LP_UART_TXD: J6.13, U1.15
PHY_AVDD: C68.1, C69.1, C70.1, C71.1, FB1.2, FB2.1, R53.2, R54.2, R55.2, R56.2, U5.1, U5.19
PHY_LED1: R57.1, U5.3
PHY_LED2: R49.1, R58.1, U5.2
PHY_RBIAS: R48.1, U5.24
PHY_RXER: R50.1, U5.10
PHY_VDDCR: C73.1, C74.1, U5.6
PHY_XI: C66.1, U5.5, Y2.1
PHY_XO: C67.1, U5.4, Y2.3
Q1_B1: Q1.2, R35.2
Q1_B2: Q1.5, R36.2
RMII_CRS_DV: R46.2, U1.57
RMII_CRS_DV_PHY: R46.1, U5.11
RMII_REF_CLK: R47.2, U1.93
RMII_REF_CLK_PHY: R47.1, U5.14
RMII_RXD0: R44.2, U1.58
RMII_RXD0_PHY: R44.1, U5.8
RMII_RXD1: R45.2, U1.60
RMII_RXD1_PHY: R45.1, U5.7
RMII_TXD0: R41.1, U1.65
RMII_TXD0_PHY: R41.2, U5.17
RMII_TXD1: R7.2, R9.1, R42.1, U1.66
RMII_TXD1_PHY: R42.2, U5.18
RMII_TX_EN: R43.1, U1.92
RMII_TX_EN_PHY: R43.2, U5.16
SD_CLK: R63.1, U1.84
SD_CLK_C: C77.1, J5.5, R63.2, U11.1, U11.10
SD_CMD: R64.1, U1.86
SD_CMD_C: J5.3, R64.2, R69.1, U11.2, U11.9
SD_D0: R59.1, U1.80
SD_D0_C: J5.7, R59.2, R65.1, U10.1, U10.10
SD_D1: R60.1, U1.81
SD_D1_C: J5.8, R60.2, R66.1, U10.2, U10.9
SD_D2: R61.1, U1.82
SD_D2_C: J5.1, R61.2, R67.1, U10.4, U10.7
SD_D3: R62.1, U1.83
SD_D3_C: J5.2, R62.2, R68.1, U10.5, U10.6
SD_DET: J5.10, R71.2, U1.23, U11.4, U11.7
SD_PWR_EN: Q2.1, R70.1, U1.22
SD_VDD: C78.1, C79.1, J5.4, Q2.3
STRAP_GPIO36: R8.2, U1.68
UART0_RXD: U1.70, U6.21
UART0_TXD: U1.69, U6.20
USB1_D_N: J1.A7, J1.B7, R29.1, U7.2
USB1_D_P: J1.A6, J1.B6, R28.1, U7.1
USB2_D_N: J2.A7, J2.B7, U6.4, U8.3, U8.4
USB2_D_P: J2.A6, J2.B6, U6.3, U8.1, U8.6
USB3_D_N: J3.A7, J3.B7, R40.1, U9.3, U9.4
USB3_D_P: J3.A6, J3.B6, R39.1, U9.1, U9.6
USBHS_D_N: R29.2, U1.49
USBHS_D_P: R10.1, R28.2, U1.50
USJ_D_N: R40.2, U1.52
USJ_D_P: R39.2, U1.53
VBUS1: C58.1, D1.2, J1.A4, J1.A9, J1.B4, J1.B9
VBUS2: C59.1, D2.2, J2.A4, J2.A9, J2.B4, J2.B9, R32.1, U8.5
VBUS3: C65.1, D3.2, J3.A4, J3.A9, J3.B4, J3.B9, U9.5
VDDO_4_SDIO: C26.1, C34.1, R65.2, R66.2, R67.2, R68.2, R69.2, U1.74, U1.85
VDDO_FLASH: C7.1, C8.1, C23.1, C45.1, R19.1, U1.30, U1.71, U2.8
VDDO_PSRAM: C17.1, C18.1, C21.1, C22.1, C24.1, U1.59, U1.67, U1.72
VDD_BAT: C40.1, C41.1, R2.2, U1.102
VDD_HP: C4.1, C5.1, C6.1, C29.1, C30.1, C31.1, C35.1, C36.1, C47.1, C48.1, L2.2, R3.1, R20.1, U1.26, U1.76, U1.91
VDD_HP1_PAD: C15.1, C16.1, R3.2, U1.54
VDD_HP_EN: U1.79, U4.1
VDD_HP_FB: C48.2, R20.2, R21.1, U1.78, U4.5
VDD_MIPI_PHY: C9.1, C10.1, C11.1, C25.1, U1.41, U1.73
VDD_USBPHY: C12.1, C13.1, C14.1, R1.2, U1.51
VSYS_5V: C49.1, C50.1, C51.1, C52.1, F1.2, J6.2, J8.1, J9.2, Q4.2, R89.1, U3.10, U3.11, U3.12, U3.13
VSYS_OR: D1.1, D2.1, D3.1, F1.1
XTAL_N: R12.1, U1.99
XTAL_N_Y: C44.1, R12.2, Y1.3
XTAL_P: R11.1, U1.100
XTAL_P_Y: C43.1, R11.2, Y1.1

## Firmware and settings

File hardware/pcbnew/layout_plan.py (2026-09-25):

"""Pure-Python layout planner for the ESP32-P4 "Extreme Performance" board.

This is layer (A) of TASK 3: it turns ``hardware.lib.board_spec`` into a
complete, *checked* layout plan made of plain data -- footprint placements
(x, y, rotation, side), thermal vias, zones, rule areas, board outline,
mechanical silhouettes, net classes and custom DRC rules. It never imports
``pcbnew``; the thin applier ``esp32p4_extreme_place.py`` (layer B) copies
the plan onto a KiCad board. Everything here is importable and testable on
a machine without KiCad.

Conventions (identical to board_spec and to KiCad):

* millimetres, design origin (0, 0) = ESP32-P4 body centre, +X right, +Y down;
* rotation in degrees, positive = counter-clockwise *on screen*, i.e. a
  footprint-local point p maps to ``R(rot) p`` with
  ``R = [[cos, sin], [-sin, cos]]``;
* bottom-side footprints are mirrored in their local Y before rotating,
  ``R(rot) (px, -py)`` -- this is what ``SetLayerAndFlip(B_Cu)`` followed by
  ``SetOrientationDegrees(rot)`` produces (both checked by reading pad
  positions back from pcbnew 7.0.11, 8.0.8, 9.0.8 and 10.0.6).

Footprint geometry (courtyard, fab outline, pads, reference text, silk
extent, "PCB Edge" markers) comes from ``footprint_courtyards.json``,
extracted from the official KiCad 10.0.6 library (``python3 -m
hardware.pcbnew.layout_plan courtyards``). Placements keep clear of the
*envelope* of every courtyard across the 10.0.6/9.0.9/8.0.9/7.0.11 releases
plus any silk that pokes out of it, so the plan stays legal whichever
library the applier loads. U1 is not in the official libraries; its geometry
is generated from ``esp32p4_pinout`` (see :func:`u1_geometry`).

Placement policy, in order (every decision is logged in ``Plan.log``):

1. **Fixed**: U1 at (0, 0) rot 0 F.Cu and the holes H1..H8 at their exact
   spec coordinates. Never moved.
2. **Absolute** (``Place``): spec coordinates. Edge connectors (``faces=``)
   get the rotation that points their mating side at that board edge (see
   :func:`mating_direction`); if the mating face then protrudes more than
   ``EDGE_OVERHANG_MAX_MM`` beyond (or sits more than ``EDGE_RECESS_MAX_MM``
   inside) the edge, it is snapped flush and reported. A part that collides
   with an already placed part, a hole keep-out or the heatsink keep-out is
   moved to the nearest legal position and reported as a *spec conflict*
   (board_spec.py is never modified).
3. **Near** (the SoC ring and everything else): deterministic greedy search on
   a 0.1 mm grid, most constrained parts first (for equal distance limits,
   high-frequency decoupling first), anchors before dependants, on the side the
   spec declares (``Near.side``). Top-side positions near U1 must keep every U1
   pad's straight *escape channel* routable (section 5b) and a U1 part must sit
   in line with its own pad. Then the radius is widened step by step and a
   WARNING is logged -- never a silent violation. A repair loop
   (:func:`build_plan`) re-runs the plan with failed parts promoted and their
   ideal spot reserved against movable absolute parts.
4. **Silkscreen**: J9 pin legend (before step 3, so parts avoid it), every
   reference designator on a pad-free spot or on Fab, the licence line last.

Distances for ``Near`` are "pad-to-pad": from the target pad centre to the
nearest pad centre of the placed part (XY distance, also for bottom-side
parts).
"""

from __future__ import annotations

import argparse
import json
import math
import os
import re
import sys
import urllib.error
import urllib.request
from dataclasses import dataclass, field
from pathlib import Path

from hardware.lib import board_spec as bs
from hardware.lib import esp32p4_pinout as p4
from hardware.lib import impedance as imp

HERE = Path(__file__).resolve().parent
COURTYARD_JSON = HERE / "footprint_courtyards.json"
DRU_FILE = HERE / "esp32p4_extreme.kicad_dru"

# --------------------------------------------------------------------------
# Policy constants
# --------------------------------------------------------------------------
SEARCH_STEP_MM = 0.1              # grid of searched (Near) positions
COURTYARD_GAP_MM = 0.02           # minimum gap the planner keeps between courtyards
EDGE_OVERHANG_MAX_MM = 1.0        # courtyard front may protrude this far past the edge
EDGE_RECESS_MAX_MM = 3.0          # ... or sit this far inside it (cable/FPC entries)
EDGE_MARKER_TOL_MM = 0.5          # footprints with a "PCB Edge" marker: marker within +/-0.5 mm
LIBRARY_TAG = "10.0.6"            # kicad-footprints release the JSON and the board use (KiCad 10)

U1_LIB_ID = "PCM_Espressif:ESP32-P4"
# Espressif ships no 3D model for the ESP32-P4. For renders/MCAD use the stock KiCad
# 10 x 10 mm QFN body (0.4 mm pitch, 88 pins): same outline and ~same height, pins are
# only representative.
U1_MODEL = "${KICAD10_3DMODEL_DIR}/Package_DFN_QFN.3dshapes/ArtInChip_QFN-88-1EP_10x10mm_P0.4mm_EP6.74x6.74mm.step"
U1_COURTYARD_HALF_MM = 5.60       # Espressif ESP32-P4.kicad_mod F.CrtYd
U1_FAB_HALF_MM = p4.BODY_MM[0] / 2
FIDUCIAL_LIB_ID = "Fiducial:Fiducial_1mm_Mask2mm"

HEATSINK_AREA = "HEATSINK_KEEPOUT"
EPAD_VIA_AREA = "U1_EPAD_VIAS"
HEAT_SPREADER_HALF_MM = getattr(bs, "BOTTOM_SPREADER_MM", 14.0) / 2   # B.Cu GND heat spreader
VDD_HP_ISLAND_HALF_MM = 4.5       # ~9 x 9 mm VDD_HP island on In2.Cu
FAN_MM = 30.0                     # 30 x 30 mm fan silhouette
BSIDE_MARGIN_MM = 0.15            # B-side courtyards stay this far off the via field
ZONE_CLEARANCE_MM = 0.15
ZONE_MIN_WIDTH_MM = 0.15

# Silkscreen texts (F.SilkS). The licence line is placed last, in the free spot closest to
# the bottom-right corner; header legends are reserved right after the absolute placements.
LICENSE_TEXT = "ESP32-P4 Extreme Perf  |  CERN-OHL-P-2.0  |  github.com/Andreuxxx1977/esp32-p4"
LICENSE_TEXT_SIZE_MM = 0.8
LEGEND_TEXT_SIZE_MM = 0.8
SILK_CLEAR_MM = 0.2               # silk boxes keep this far from courtyards, holes and the edge
HEADER_LEGENDS = {"J9": "LCD_HEADER_LABELS"}    # ref -> board_spec attribute with pin labels

# Where the design origin (SoC centre) sits on the KiCad sheet: the centre of an A4 page, so
# the board is drawn inside the frame. Aux (drill/place) and grid origins are set here, so
# every coordinate *relative to the origins* equals the design coordinate.
PAGE_ORIGIN_MM = (148.5, 105.0)

LAYERS = {  # copper layer -> board layer name
    "F.Cu": "Signal_Top", "In1.Cu": "GND", "In2.Cu": "VCC_3V3", "B.Cu": "Signal_Bottom"}
USER_LAYERS = {"User.1": "Heatsink", "User.2": "Fan"}

# Design rules (HDI, 1+2+1): values in mm.
DESIGN_RULES = {
    "min_track": 0.09, "min_clearance": 0.09,
    "via_drill": 0.20, "via_diameter": 0.45,
    "uvia_drill": 0.10, "uvia_diameter": 0.25,
    "min_annular": 0.10, "hole_to_hole": 0.25, "hole_clearance": 0.20,
    "copper_edge": 0.30, "board_thickness": imp.BOARD_THICKNESS_MM,
}

# Spec pin names that are mechanical (excluded from the mating-side heuristic).
MECH_PIN_NAMES = frozenset({"MP", "SH", "SHIELD", "EP"})

EPS = 1e-6

Rect = tuple  # (x0, y0, x1, y1)


# ==========================================================================
# 1. Geometry
# ==========================================================================

def _cos_sin(deg: float) -> tuple[float, float]:
    d = deg % 360.0
    exact = {0.0: (1.0, 0.0), 90.0: (0.0, 1.0), 180.0: (-1.0, 0.0), 270.0: (0.0, -1.0)}
    if d in exact:
        return exact[d]
    a = math.radians(d)
    return math.cos(a), math.sin(a)


def rotate(x: float, y: float, deg: float) -> tuple[float, float]:
    """KiCad rotation: +deg is counter-clockwise on screen (Y axis down)."""
    c, s = _cos_sin(deg)
    return x * c + y * s, -x * s + y * c


def to_board(px: float, py: float, x: float, y: float, rot: float, side: str) -> tuple[float, float]:
    """Footprint-local point -> design coordinates."""
    if side == "B":
        py = -py
    rx, ry = rotate(px, py, rot)
    return x + rx, y + ry


def xform_rect(r: Rect, x: float, y: float, rot: float, side: str) -> Rect:
    pts = [to_board(px, py, x, y, rot, side) for px in (r[0], r[2]) for py in (r[1], r[3])]
    xs = [p[0] for p in pts]
    ys = [p[1] for p in pts]
    return (min(xs), min(ys), max(xs), max(ys))


def rects_overlap(a: Rect, b: Rect, gap: float = 0.0) -> bool:
    """True if the rectangles are closer than ``gap`` (touching is legal)."""
    return (a[0] < b[2] + gap - EPS and b[0] < a[2] + gap - EPS
            and a[1] < b[3] + gap - EPS and b[1] < a[3] + gap - EPS)


def rect_point_dist(r: Rect, x: float, y: float) -> float:
    dx = max(r[0] - x, 0.0, x - r[2])
    dy = max(r[1] - y, 0.0, y - r[3])
    return math.hypot(dx, dy)


def point_in_outline(x: float, y: float, outline: Rect = bs.BOARD_OUTLINE,
                     radius: float = bs.BOARD_CORNER_R) -> bool:
    x0, y0, x1, y1 = outline
    if not (x0 - EPS <= x <= x1 + EPS and y0 - EPS <= y <= y1 + EPS):
        return False
    cx = min(max(x, x0 + radius), x1 - radius)
    cy = min(max(y, y0 + radius), y1 - radius)
    return math.hypot(x - cx, y - cy) <= radius + EPS


@dataclass(frozen=True)
class Shape:
    """A courtyard in design coordinates: an axis-aligned rectangle or a circle."""

    rect: Rect                      # bounding box (always valid)
    circle: tuple | None = None     # (cx, cy, r) for round courtyards

    def overlaps(self, other: "Shape", gap: float = 0.0) -> bool:
        if not rects_overlap(self.rect, other.rect, gap):
            return False
        if self.circle and other.circle:
            (ax, ay, ar), (bx, by, br) = self.circle, other.circle
            return math.hypot(ax - bx, ay - by) < ar + br + gap - EPS
        if self.circle:
            cx, cy, r = self.circle
            return rect_point_dist(other.rect, cx, cy) < r + gap - EPS
        if other.circle:
            cx, cy, r = other.circle
            return rect_point_dist(self.rect, cx, cy) < r + gap - EPS
        return True

    def overlaps_rect(self, r: Rect) -> bool:
        return self.overlaps(Shape(r))

    def hits_circle(self, cx: float, cy: float, r: float) -> bool:
        if self.circle:
            sx, sy, sr = self.circle
            return math.hypot(sx - cx, sy - cy) < sr + r - EPS
        return rect_point_dist(self.rect, cx, cy) < r - EPS

    def inside_outline(self, outline: Rect = bs.BOARD_OUTLINE, radius: float = bs.BOARD_CORNER_R) -> bool:
        if self.circle:
            cx, cy, r = self.circle
            n = 32
            return all(point_in_outline(cx + r * math.cos(2 * math.pi * k / n),
                                        cy + r * math.sin(2 * math.pi * k / n), outline, radius)
                       for k in range(n))
        x0, y0, x1, y1 = self.rect
        ox0, oy0, ox1, oy1 = outline
        if x0 < ox0 - EPS or y0 < oy0 - EPS or x1 > ox1 + EPS or y1 > oy1 + EPS:
            return False
        if (x0 >= ox0 + radius and x1 <= ox1 - radius) or (y0 >= oy0 + radius and y1 <= oy1 - radius):
            return True
        return all(point_in_outline(px, py, outline, radius) for px in (x0, x1) for py in (y0, y1))


# ==========================================================================
# 2. Footprint geometry database
# ==========================================================================

@dataclass(frozen=True)
class PadGeom:
    number: str
    kind: str            # smd | tht | npth | aperture
    x: float
    y: float
    sx: float            # copper extent along X in the footprint frame (pad rotation applied)
    sy: float
    shape: str = "rect"  # KiCad pad shape (circle | oval | rect | roundrect | ...)


@dataclass(frozen=True)
class FootprintGeom:
    lib_id: str
    courtyard: Rect                  # F.CrtYd bounding box, footprint frame, rot 0
    courtyard_r: float | None        # set when the courtyard is one circle at the origin
    fab: Rect | None
    pads: tuple[PadGeom, ...]
    pcb_edge: tuple | None           # "PCB Edge" marker segment (x0, y0, x1, y1)
    tht: bool
    description: str = ""
    ref_text: tuple | None = None    # library Reference text: (x, y, size, layer)
    silk: Rect | None = None         # F.SilkS bounding box (stroke included)

    @property
    def envelope(self) -> Rect:
        """What the planner keeps clear: courtyard plus any silk poking out of it
        (pin-1 markers of QFN/SOT parts reach up to 0.4 mm past the courtyard)."""
        c, k = self.courtyard, self.silk
        if not k:
            return c
        return (min(c[0], k[0]), min(c[1], k[1]), max(c[2], k[2]), max(c[3], k[3]))

    def pad_numbers(self) -> list[str]:
        out: list[str] = []
        for p in self.pads:
            if p.number and p.number not in out:
                out.append(p.number)
        return out

    def copper_pads(self) -> list[PadGeom]:
        return [p for p in self.pads if p.kind in ("smd", "tht")]


def u1_geometry() -> FootprintGeom:
    """ESP32-P4 QFN-104 land pattern generated from ``esp32p4_pinout``.

    104 perimeter pads (0.20 x 0.65 mm, 0.35 mm pitch, rows at +/-4.875 mm)
    and one solid 7.5 x 7.5 mm EPAD (pad 105). The applier adds the 3 x 3
    paste windows (2.1 mm tiles on 2.7 mm pitch, -0.2 mm paste margin).
    """
    w, l = p4.PAD_SIZE_MM
    pads = []
    for n in range(1, 105):
        x, y = p4.pad_position(n)
        horizontal = p4.pad_side(n) in ("left", "right")
        pads.append(PadGeom(str(n), "smd", x, y, l if horizontal else w, w if horizontal else l,
                            "oval"))
    e = p4.EPAD_SIZE_MM
    pads.append(PadGeom("105", "smd", 0.0, 0.0, e, e))
    c, f = U1_COURTYARD_HALF_MM, U1_FAB_HALF_MM
    return FootprintGeom(U1_LIB_ID, (-c, -c, c, c), None, (-f, -f, f, f), tuple(pads), None, False,
                         "ESP32-P4 QFN-104 10x10 mm, generated from esp32p4_pinout",
                         (0.0, -6.4, 1.0, "F.SilkS"))


def load_geometry(path: Path = COURTYARD_JSON) -> dict[str, FootprintGeom]:
    data = json.loads(Path(path).read_text())
    out: dict[str, FootprintGeom] = {}
    for lib_id, d in data["footprints"].items():
        pads = tuple(PadGeom(*p) for p in d["pads"])
        out[lib_id] = FootprintGeom(
            lib_id, tuple(d["courtyard"]), d.get("courtyard_r"),
            tuple(d["fab"]) if d.get("fab") else None, pads,
            tuple(d["pcb_edge"]) if d.get("pcb_edge") else None, d.get("tht", False),
            d.get("descr", ""), tuple(d["ref"]) if d.get("ref") else None,
            tuple(d["silk"]) if d.get("silk") else None)
    out[U1_LIB_ID] = u1_geometry()
    return out


# ---- .kicad_mod parsing (only used to (re)generate the JSON) ---------------
_TOKEN = re.compile(r'\s*(\(|\)|"(?:[^"\\]|\\.)*"|[^\s()"]+)')


def parse_sexpr(text: str) -> list:
    stack: list[list] = [[]]
    for m in _TOKEN.finditer(text):
        tok = m.group(1)
        if tok == "(":
            stack.append([])
        elif tok == ")":
            node = stack.pop()
            stack[-1].append(node)
        else:
            stack[-1].append(tok[1:-1].replace('\\"', '"') if tok.startswith('"') else tok)
    return stack[0][0]


def _children(node: list, key: str) -> list[list]:
    return [c for c in node[1:] if isinstance(c, list) and c and c[0] == key]


def _child(node: list, key: str) -> list | None:
    found = _children(node, key)
    return found[0] if found else None


def _xy(node: list | None) -> tuple[float, float] | None:
    return (float(node[1]), float(node[2])) if node else None


def _graphic_points(g: list) -> list[tuple[float, float]]:
    if g[0] == "fp_circle":
        (cx, cy), (ex, ey) = _xy(_child(g, "center")), _xy(_child(g, "end"))
        r = math.hypot(ex - cx, ey - cy)
        return [(cx - r, cy - r), (cx + r, cy + r)]
    pts = [_xy(_child(g, k)) for k in ("start", "mid", "end")]
    poly = _child(g, "pts")
    if poly:
        pts += [_xy(xy) for xy in _children(poly, "xy")]
    return [p for p in pts if p]


def _bbox(points: list[tuple[float, float]]) -> Rect | None:
    if not points:
        return None
    xs = [p[0] for p in points]
    ys = [p[1] for p in points]
    return (round(min(xs), 4), round(min(ys), 4), round(max(xs), 4), round(max(ys), 4))


def extract_footprint(text: str) -> dict:
    """Courtyard / fab bbox, pads and PCB-edge marker of one .kicad_mod file."""
    fp = parse_sexpr(text)
    layers: dict[str, list[list]] = {}
    for kind in ("fp_line", "fp_rect", "fp_circle", "fp_arc", "fp_poly"):
        for g in _children(fp, kind):
            layers.setdefault(_child(g, "layer")[1], []).append(g)
    crt = layers.get("F.CrtYd", [])
    courtyard = _bbox([p for g in crt for p in _graphic_points(g)])
    courtyard_r = None
    if len(crt) == 1 and crt[0][0] == "fp_circle":
        (cx, cy) = _xy(_child(crt[0], "center"))
        if abs(cx) < EPS and abs(cy) < EPS:
            courtyard_r = round(courtyard[2], 4)
    fab = _bbox([p for g in layers.get("F.Fab", []) for p in _graphic_points(g)])
    silk_pts = []
    for g in layers.get("F.SilkS", []):
        w = _child(_child(g, "stroke") or [], "width")
        half = float(w[1]) / 2 if w else 0.06
        for x, y in _graphic_points(g):
            silk_pts += [(x - half, y - half), (x + half, y + half)]
    silk = _bbox(silk_pts)
    pads = []
    for pad in _children(fp, "pad"):
        at = _child(pad, "at")
        size = _child(pad, "size")
        ang = float(at[3]) if len(at) > 3 else 0.0
        w, h = float(size[1]), float(size[2])
        c, s = abs(math.cos(math.radians(ang))), abs(math.sin(math.radians(ang)))
        sx, sy = w * c + h * s, w * s + h * c
        lay = set(_child(pad, "layers")[1:])
        kind = {"thru_hole": "tht", "np_thru_hole": "npth"}.get(pad[2], "smd")
        if kind == "smd" and not any(layer.endswith(".Cu") for layer in lay):
            kind = "aperture"
        pads.append([pad[1], kind, float(at[1]), float(at[2]), round(sx, 4), round(sy, 4), pad[3]])
    edge = None
    marker_texts = [t for t in _children(fp, "fp_text") if "pcb edge" in t[2].lower()]
    if marker_texts:
        for layer in ("Dwgs.User", "Cmts.User"):
            for g in layers.get(layer, []):
                if g[0] == "fp_line":
                    (x0, y0), (x1, y1) = _xy(_child(g, "start")), _xy(_child(g, "end"))
                    edge = (x0, y0, x1, y1)
    ref = None
    for node in _children(fp, "property") + _children(fp, "fp_text"):
        if node[1] in ("Reference", "reference"):
            at, font = _child(node, "at"), _child(_child(node, "effects") or [], "font")
            size = _child(font, "size") if font else None
            layer = _child(node, "layer")
            ref = [float(at[1]), float(at[2]), float(size[1]) if size else 1.0,
                   layer[1] if layer else "F.SilkS"]
    attr = _child(fp, "attr")
    descr = _child(fp, "descr")
    return {"courtyard": courtyard, "courtyard_r": courtyard_r, "fab": fab, "pads": pads,
            "pcb_edge": edge, "tht": bool(attr and attr[1] == "through_hole"),
            "ref": ref, "silk": silk, "descr": descr[1] if descr else ""}


def required_lib_ids() -> list[str]:
    ids = {c.part.footprint for c in bs.COMPONENTS} | {FIDUCIAL_LIB_ID}
    ids.discard(U1_LIB_ID)
    return sorted(ids)


ENVELOPE_TAGS = ("9.0.9", "8.0.9", "7.0.11")   # older libraries the applier may still meet


DEFAULT_CACHE = Path(os.environ.get("KICAD_FP_CACHE", Path.home() / ".cache" / "esp32p4-footprints"))


def cached_footprint_path(cache: Path, tag: str, lib_id: str) -> Path:
    """master files live directly in the cache (same layout as hardware/skidl/check_footprints.py),
    other library releases under ``<cache>/<tag>/``."""
    lib, name = lib_id.split(":", 1)
    base = cache if tag == "master" else cache / tag
    return base / f"{lib}.pretty" / f"{name}.kicad_mod"


def _fetch(cache: Path, tag: str, lib_id: str, fetch: bool) -> Path | None:
    lib, name = lib_id.split(":", 1)
    path = cached_footprint_path(cache, tag, lib_id)
    if not path.exists() and fetch:
        url = (f"https://gitlab.com/kicad/libraries/kicad-footprints/-/raw/{tag}/"
               f"{lib}.pretty/{name}.kicad_mod")
        try:
            data = urllib.request.urlopen(url, timeout=60).read()
        except urllib.error.HTTPError:
            return None
        path.parent.mkdir(parents=True, exist_ok=True)
        path.write_bytes(data)
        print(f"fetched {tag} {lib_id}")
    return path if path.exists() else None
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

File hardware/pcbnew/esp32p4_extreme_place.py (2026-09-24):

#!/usr/bin/env python3
"""TASK 3 (pcbnew) -- ESP32-P4 "Extreme Performance" board: placement applier.

Layer (B) of the placement flow. All decisions -- every coordinate, rotation,
side, via, zone, rule area, net class and DRC rule -- are made by the pure-
Python planner ``hardware/pcbnew/layout_plan.py`` (testable without KiCad).
This script only copies that plan onto a KiCad board through the pcbnew API,
then reads the result back and asserts it.

Tested with the pcbnew Python module of KiCad 7.0.11, 8.0.8, 9.0.8 and 10.0.6
(headless; the CI job runs it inside the official ``kicad/kicad:10.0`` image with
``--fp-dir /usr/share/kicad/footprints``).

Usage (a Python that can ``import pcbnew``, e.g. KiCad's bundled one)::

    python3 hardware/pcbnew/esp32p4_extreme_place.py                   # new board
    python3 hardware/pcbnew/esp32p4_extreme_place.py --board in.kicad_pcb  # update refs in place
        [-o hardware/output/esp32p4_extreme.kicad_pcb] [--fp-dir DIR ...]
        [--fill] [--drc] [--top-only] [--origin 148.5 105]

Inside the pcbnew scripting console::

    import sys; sys.argv = ['x', '-o', '/path/out.kicad_pcb']
    exec(open('/path/to/esp32p4_extreme_place.py').read())

Footprint libraries are searched in: ``--fp-dir``, then ``$KICAD9_FOOTPRINT_DIR``,
``$KICAD8_FOOTPRINT_DIR``, ``$KICAD7_FOOTPRINT_DIR`` (the running version's
variable first), then the usual install locations. U1 (PCM_Espressif:ESP32-P4)
is always generated from ``esp32p4_pinout``. A footprint that cannot be found
is built from ``footprint_courtyards.json`` (pads + courtyard) with a WARNING,
unless ``--strict-libs`` is given.

Outputs next to the board: ``<name>.kicad_pro`` (net classes, design rules),
``<name>.kicad_dru`` (custom rules), ``<name>.placement.txt`` (report).
"""

from __future__ import annotations

import argparse
import json
import math
import os
import shutil
import subprocess
import sys
from pathlib import Path

REPO = Path(__file__).resolve().parents[2]
if str(REPO) not in sys.path:
    sys.path.insert(0, str(REPO))

import pcbnew  # noqa: E402  (KiCad)

from hardware.lib import board_spec as bs  # noqa: E402
from hardware.lib import esp32p4_pinout as p4  # noqa: E402
from hardware.pcbnew import layout_plan as lp  # noqa: E402

KICAD_MAJOR = int(pcbnew.Version().strip("()").split(".")[0])
GROUP_NAME = "esp32p4_plan"      # everything this script creates (except footprints)
DEFAULT_OUT = REPO / "hardware" / "output" / "esp32p4_extreme.kicad_pcb"


# ==========================================================================
# Version shims (KiCad 7 / 8 / 9)
# ==========================================================================

def nm(mm: float) -> int:
    """mm -> KiCad internal units (nm), exact for values on a 1 nm grid."""
    return int(round(mm * 1_000_000))


class Frame:
    """Design coordinates (SoC-centred mm) -> board coordinates (nm)."""

    def __init__(self, origin_mm: tuple[float, float]):
        self.ox, self.oy = nm(origin_mm[0]), nm(origin_mm[1])

    def pt(self, x: float, y: float) -> "pcbnew.VECTOR2I":
        return pcbnew.VECTOR2I(self.ox + nm(x), self.oy + nm(y))

    def back(self, v) -> tuple[int, int]:
        """Board position -> design position in nm (exact integers)."""
        return v.x - self.ox, v.y - self.oy


LAYER_IDS = {
    "F.Cu": pcbnew.F_Cu, "In1.Cu": pcbnew.In1_Cu, "In2.Cu": pcbnew.In2_Cu, "B.Cu": pcbnew.B_Cu,
    "F.SilkS": pcbnew.F_SilkS, "B.SilkS": pcbnew.B_SilkS, "F.Mask": pcbnew.F_Mask,
    "B.Mask": pcbnew.B_Mask, "F.Paste": pcbnew.F_Paste, "F.Fab": pcbnew.F_Fab,
    "F.CrtYd": pcbnew.F_CrtYd, "Edge.Cuts": pcbnew.Edge_Cuts, "User.1": pcbnew.User_1,
    "User.2": pcbnew.User_2, "Dwgs.User": pcbnew.Dwgs_User,
}


def lset(*layers: int) -> "pcbnew.LSET":
    s = pcbnew.LSET()
    for layer in layers:
        s.AddLayer(layer)
    return s


def set_field(fp, name: str, value: str) -> None:
    """A hidden, Fab-layer footprint field (KiCad 8+) or a footprint property (KiCad 7)."""
    if hasattr(fp, "SetField"):              # KiCad 8+: fields are text items -> keep them
        fp.SetField(name, value)             # off the silkscreen
        for field in fp.GetFields():         # (GetFieldByName is gone in 10, GetField(int) in 8/9)
            if field.GetName() == name:
                field.SetVisible(False)
                field.SetLayer(pcbnew.B_Fab if fp.GetLayer() == pcbnew.B_Cu else pcbnew.F_Fab)
    else:                                    # KiCad 7: footprint properties (no text)
        fp.SetProperty(name, value)


def set_dnp(fp) -> None:
    if hasattr(fp, "SetDNP"):                # KiCad 8+
        fp.SetDNP(True)
    else:                                    # KiCad 7 has no DNP flag
        fp.SetAttributes(fp.GetAttributes() | pcbnew.FP_EXCLUDE_FROM_POS_FILES)
        set_field(fp, "DNP", "DNP")


def set_pad_solid(pad) -> None:
    if hasattr(pad, "SetLocalZoneConnection"):   # KiCad 9
        pad.SetLocalZoneConnection(pcbnew.ZONE_CONNECTION_FULL)
    else:                                        # KiCad 7/8
        pad.SetZoneConnection(pcbnew.ZONE_CONNECTION_FULL)


def set_pad_geometry(pad, shape: int, w: float, h: float) -> None:
    size = pcbnew.VECTOR2I(nm(w), nm(h))
    try:
        pad.SetShape(shape)
        pad.SetSize(size)
    except TypeError:                            # padstack API: (layer, value)
        pad.SetShape(pcbnew.F_Cu, shape)
        pad.SetSize(pcbnew.F_Cu, size)


def fp_graphic(fp, kind: int):
    """A graphic item owned by a footprint (FP_SHAPE in KiCad 7, PCB_SHAPE in 8+)."""
    cls = getattr(pcbnew, "FP_SHAPE", None)
    return cls(fp, kind) if cls else pcbnew.PCB_SHAPE(fp, kind)


def finish_fp_item(item) -> None:
    """KiCad 7 stores local copies of child coordinates; refresh them."""
    if hasattr(item, "SetLocalCoord"):
        item.SetLocalCoord()


def set_priority(zone, priority: int) -> None:
    (zone.SetAssignedPriority if hasattr(zone, "SetAssignedPriority") else zone.SetPriority)(priority)


def mm_units():
    return getattr(pcbnew, "EDA_UNITS_MM", getattr(pcbnew, "EDA_UNITS_MILLIMETRES", None))
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

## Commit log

2026-09-24 Add ESP32-P4 board design data model (pinout, spec, stack-up)
    Single source of truth for the Extreme Performance ESP32-P4 board:
    - esp32p4_pinout.py: ESP32-P4X QFN-104 pad table, land-pattern geometry,
    GPIO power domains, reset states, strapping pins and IO_MUX-fixed pads,
    all taken from Espressif's KiCad library, ESP-IDF and the P4 hardware
    design guidelines.
    - board_spec.py: parts/MPNs/footprints, GPIO map, full connectivity,
    placement (SoC at 0,0; M2.5 heatsink holes at +/-15 mm), mechanical
    constants and validate() design-rule checks.
    - impedance.py: 4-layer HDI stack-up and 50/90/100 ohm geometry.
    Claude-Session: https:/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
2026-09-24 Apply component verification findings to board spec
    - USB-HS ESD: TPD2EUSB30DRTR (0.7 pF) instead of USBLC6-2SC6 (3.5 pF max,
    above Espressif's 1 pF limit); USBLC6 kept on the full-speed ports.
    - FPC: Amphenol F32Q-1A7H1-11022, the Raspberry Pi 5 top-contact part, so
    standard Pi 22-pin cables work without pin mirroring.
    - RJ45 HR911105A LED pins 9-12 corrected; PTC MPN corrected to
    MF-MSMF250/16X-2; 40 MHz CTS 402F4001XIAR (2016) and 25 MHz YXC
    X322525MOB4SI crystals with matching load caps; XAL5030 footprint name.
    - microSD lines protected by 2x TPD4E05U06DQAR (0.5 pF, UHS-I safe).
    - PTS810 tactile switch modelled as its real 2-terminal footprint
    (previous 4-pin model would have m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
2026-09-24 Add SKiDL netlist generator, netlist verifier and footprint pad check
    TASK 3 (SKiDL): hardware/skidl/esp32p4_extreme_netlist.py builds every
    part, pin and net from hardware.lib.board_spec (no KiCad libraries
    needed), runs ERC (0 errors, 0 warnings) and writes the KiCad netlist.
    verify_netlist.py independently re-parses the netlist/CSV against the
    spec; check_footprints.py cross-checks every used pad against the real
    KiCad/Espressif footprints.
    Spec fixes found by the footprint check:
    - USB4105 shell pads are 'SH' (4 plated legs), microSD shield 'SH',
    F32Q FPC mounting pads 'MP'.
    - L2: KiCad has no Murata DFE252012F footprint -> generic L_1008_2520Metric.
    - TPD4E05U06 flow-through pads 6/7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
    [esp32p4_extreme_nets.csv]
2026-09-24 README: clarify the silkscreen source-location note
    Claude-Session: https://claude.ai/code/session_01HPbQMeq7CyuN5d7UYEJZ7D
2026-09-24 Relicense under CERN-OHL-P-2.0: free to use with attribution
    The owner wants anyone to be free to use, modify, fabricate and sell
    the design, with crediting the original project as the only request.
    CERN-OHL-S-2.0 (strongly reciprocal) contradicts that, so switch to the
    permissive CERN-OHL-P-2.0 from the same family; its section 3.2 makes
    the attribution Notice binding. README explains the terms in plain
    words (English + Spanish), gives a ready-to-copy attribution line,
    notes the AI-assisted origin and that the board is not yet
    fabricated/bench-tested.
    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
2026-09-24 Add generated TASK1/2/4 docs, PCBWay BOM, spec tests and SPI display header
    Docs (python3 -m tools.gen_docs, --check for staleness), all generated
    from hardware.lib.board_spec:
    - docs/TASK1_pinout.md: 55-row GPIO map, dedicated pads, zero-conflict
    matrix RMII/SDIO/MIPI/USB-HS/USB-JTAG/UART0, avoided IO_MUX options,
    strapping, routing rules, stack-up and impedance geometry.
    - docs/TASK2_mechanical_thermal.md: heat paths, 49-via array (3.9 K/W),
    thermal network estimate, coordinates and hole collision checks,
    airflow and fan control.
    - docs/TASK4_bom_pcbway.md + hardware/output/bom_pcbway.csv: turnkey BOM.
    - tests/test_board_spec.py: 53 checks (pin conflicts, IO_MUX legality,
    strappi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
    [bom_pcbway.csv, esp32p4_extreme_nets.csv]
2026-09-24 Update README, add CONTRIBUTING, CI workflow and GitHub templates
    - README: what the board is, block diagram (mermaid), a 'Download the
    files' table that says which file is which (the placed .kicad_pcb is
    marked as not published yet; the netlist and PCBWay BOM are available
    now), project status, how the single-source repo works, design
    decisions, contributing and the CERN-OHL-P-2.0 licence section.
    - CONTRIBUTING.md: golden rule (edit the spec, regenerate), workflow,
    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
2026-09-24 CI: add KiCad 10 job (pcbnew API, DRC gate, 3D render, centroid)
    - New 'kicad' job runs in the official kicad/kicad:10.0 image: proves
    kicad-cli and the pcbnew Python API are available, and once
    hardware/output/esp32p4_extreme.kicad_pcb is committed runs KiCad DRC,
    top/bottom 3D renders and the PCBWay pick-and-place export, uploaded
    as build artifacts.
    - tools/check_drc_report.py gates the DRC JSON: any error-severity
    violation fails; unconnected items are tolerated until the board is
    routed (--strict afterwards). 4 new tests (57 total).
    - check_footprints now checks against the KiCad 10.0.6 library tag
    (--ref to override) instead of the moving master branch; cache is
    per-ref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
    [check_drc_report.py, check_footprints.py, test_check_drc_report.py]
2026-09-24 Add the placed KiCad 10 board (pcbnew script, standalone writer, DRC rules)
    TASK 3 (pcbnew): the placement is computed once, as data, and applied
    two ways that produce the same board:
    - hardware/pcbnew/layout_plan.py: pure-Python planner (placements,
    connector rotations from footprint geometry, SoC decoupling ring,
    49 EPAD thermal vias, zones, keep-out rule areas, net classes and
    diff pairs, silkscreen incl. licence line and J9 pin labels) plus the
    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
    [esp32p4_extreme.kicad_pcb, esp32p4_extreme_nets.csv]
2026-09-24 CI: build the board with real pcbnew, render with 3D models, publish renders
    - KiCad 10 job now also rebuilds the board with the pcbnew placement
    script inside kicad/kicad:10.0 (--strict-libs) and gates both that
    board and the committed one on KiCad DRC (0 errors).
    - tools/fetch_3d_models.py downloads exactly the 3D models the board
    references from kicad-packages3D 10.0.6 (same-body stand-ins for 4
    footprints whose model does not exist; RJ45/FPC stay footprint-only),
    so renders show the assembled board. U1 gets a representative
    10x10 mm QFN body (Espressif ships no model). 3 new tests.
    - On push to main the top/bottom renders are published to the
    'renders' branch; the README sh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
    [fetch_3d_models.py, test_fetch_3d_models.py]
2026-09-24 Autorouting and fabrication-package tooling; README: how the project was made
    - hardware/pcbnew/autoroute.py: FreeRouting (DSN/SES) flow. Builds a routing view
    of the placed board (drops marker rule areas that KiCad would export as full
    keep-outs, drops outer GND pours so GND pads get explicit plane vias, cuts the
    VDD_HP island out of the +3V3 plane, adds U1 fan-out stubs inside the courtyard),
    routes headless, imports the session into the unmodified board, fills zones and
    verifies placement, pad nets and zones are unchanged (--verify for CI).
    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
2026-09-24 Placement: keep a routable escape channel for every SoC pad; USB-C design tests
    The first autorouting runs showed the SoC could not be escaped: the 0402 ring around
    the 0.35 mm-pitch QFN left no gap >= 0.35 mm on any side, while ~60 of the 100 connected
    pads go to parts outside it.
    - layout_plan: new escape-channel model (section 5b). Each connected U1 pad gets a
    straight radial channel from the end of its fan-out stub; a top-side placement near
    the SoC is legal only if, per side and radial band, all channels still pack between
    the other nets' pads at netclass width + clearance (with a bounded 45-degree jog).
    Supply channels end at their first cap; series 0R/22R parts pass their own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
    [esp32p4_extreme.kicad_pcb]
2026-09-24 autoroute: optional HDI laser microvias (L1-L2 to GND, L3-L4 to the power planes)
    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
2026-09-24 autoroute: plane via-in-pad pre-routing; keep planned vias through the import
    - Pre-routing is now planned data applied to both the router's view and the final
    board: U1 stubs, the planned EPAD thermal vias, and filled-and-capped vias in the
    pads of plane nets (top GND: L1-L2 laser microvia; top +3V3: through via; bottom
    +3V3 / VDD_HP inside its island: L4-L3 microvia), each only where it clears every
    other-net pad, stub, hole and the edge. 169 of 177 plane pads get one.
    - After the session import the pre-routing is restored exactly (FreeRouting drops
    fixed vias it does not need, e.g. the 49 EPAD thermal vias), session via drills are
    corrected by pad diameter (KiCad takes them fr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
    [layout_plan.py]
2026-09-24 Fab package README (order notes, HDI/VIPPO, DRC verdict); accept one thermal spoke per pad
    - tools/export_fab.py writes README.md into the package: files, stack-up, via counts,
    HDI and via-in-pad requirements, and -- given --drc -- the KiCad DRC verdict with the
    high-speed rules that are not met. It says 'do not order' unless the gate passes.
    - DRC rule single_spoke_ok replaces the per-footprint 0402 list: fine-pitch GND pins
    keep only one spoke once tracks are in.
    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
    [export_fab.py, layout_plan.py]
2026-09-24 autoroute: vias inside U1's pad ring for bottom-side decoupling and the VDD_HP island
    Pads whose decoupling sits on the bottom under the pad ring (and the VDD_HP pads, whose
    via lands in the In2.Cu island) get a through via between the EPAD and the pad row,
    joined by a short inward track; at most every other pad (0.35 mm pitch), checked
    against U1's own pads (copper, hole and mask clearance) with a small slide along the
    row near the corners. Pre-routing alone is DRC-clean.
    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
2026-09-24 autoroute: --resume ROUTED continues from an earlier routed board; planned vias from the spec
    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
2026-09-24 SoC escape tracks solved as a MILP; grid router to finish what the autorouter leaves
    The router is not told about the escape-channel model and blocks channels (e.g. lays a
    neighbour straight through the room a channel needed for its jog). So the escape tracks
    are now routed by the planner itself and handed to the router as fixed copper:
    - layout_plan: one mixed-integer program per SoC side (scipy/HiGHS): each channel's
    tangential position every 25 um of radius, starting on its pad line at the stub end,
    at most 45 degrees, netclass clearance to every other-net pad (exact point-to-rectangle
    distance, one binary per channel/pad for the side it passes), netclass pitch to the
    neighbours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
    [esp32p4_extreme.kicad_pcb]
2026-09-24 Escape tracks: L1 bend penalty so each track is a few straight runs
    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
2026-09-24 Escape tracks re-solved with the bend penalty (70 tracks, ~800 vertices); drop any the exact check rejects
    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
    [layout_plan.py]
2026-09-24 maze_route: plane-net connections may end in a via into their plane (GND microvia to In1, +3V3/VDD_HP to In2)
    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
2026-09-24 Own board router replaces FreeRouting; SoC/fine-pitch breakout rules
    FreeRouting left 61 connections unrouted and 180 DRC errors on this board, so the
    routing is now done by a router written for it (tools/pcb_router.py, search core in
    tools/router_core.c, compiled with the system C compiler on first use):
    - exact clearance model: distance from every grid cell to every copper shape
    (rounded rects, circles, track capsules), larger of the two net clearances;
    - differential pairs routed first and coupled (fat centre line offset into P/N at
    the netclass gap, F.Cu, no vias, no right angles), MIPI before USB before
    Ethernet; P/N order reversals cross with a via pair;
    - octilinear tracks with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
    [check_drc_report.py, export_fab.py, layout_plan.py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]
2026-09-24 pcb_router: NPTH hole clearance never necked down, SoC connections right after the pairs, reachability precheck before A*, history on the ripped copper only
    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
    [pcb_router.py]
2026-09-25 pcb_router: fan-out first, In2.Cu as a third routing layer (supplies and low-speed signals, L4-L3 microvias), plane pads may join plane copper, relaxed rip-up rights, crystal vias only as a last reso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
2026-09-25 pcb_router: keep the In2.Cu planes whole (a route that would split the +3V3 plane or the VDD_HP island is refused and retried on the outer layers)
    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
2026-09-25 pcb_router: skip gaps that already failed in the same pass; DRC repair rounds until they stop helping (max 10)
    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
    [pcb_router.py]
2026-09-25 pcb_router --resume: adopt a board's unlocked routing as rip-up-able pieces and route what is missing
    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
    [pcb_router.py]
2026-09-25 pcb_router: a differential pair without a coupled path on F.Cu is tried coupled on B.Cu (fan-ins with vias)
    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
2026-09-25 pcb_router: rip-up searches treat routing they may not rip as fixed, and victim checks use the necked-down clearance of the breakout areas (false conflicts made rip-ups fail)
    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
    [pcb_router.py]
2026-09-25 Router: cut back dangling track ends (KiCad's connectivity rule)
    Where a route joins a pre-routed escape track part-way along it, the rest
    of the escape was left as a dead stub (37 track_dangling warnings). After
    the last DRC round the router now cuts each dangling end back to the
    farthest point where another item of the net is anchored in the track,
    using KiCad's own test for dangling ends (an item reaching both ends of a
    short track counts only for the nearer one). Pre-routed tracks that are
    cut are re-written (locked) and their originals left out of the output.
    The trim is undone if KiCad then reports more unconnected items; nets
    that are not fully routed are left alone.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
    [pcb_router.py, test_pcb_router.py]
2026-09-25 Router: fixes found on the last walled-in connections
    - A rip-up plan through In2.Cu that would split a plane is retried on the
    outer layers (it used to fail the connection outright).
    - Outlines of rule areas that only forbid vias (U1_EPAD_VIAS) no longer
    block tracks: they are their own obstacle class, used by the via maps.
    This had closed the ring between U1's pads and its thermal-via field.
    - The U1 courtyard gets the DRU's fan-out clearance on both sides, and a
    track may neck down anywhere inside it (the ring under the SoC).
    - The rip-up victim test uses the necked width where the path necks down
    (a pair next to a necked cell was taken for a victim that may not be
    ripped, so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
    [pcb_router.py]
2026-09-25 Router: U1 courtyard rule on In2 too; SoC escapes may be pushed as a last resort
    - The DRU's U1 fan-out clearance (intersectsCourtyard) holds on every
    layer. The router applied the full netclass clearance on In2, which
    left room for one via instead of two between the fixed ring vias on
    U1's east side.
    - The planner's escape tracks (non-pair, non-plane) between the U1 stub
    ends and the escape reach become routing that only the last-resort
    search may push aside: on U1's east side the escape of RMII_TXD0 left
    RMII_TXD1 walled in by a few hundredths of a millimetre. Escapes stay
    locked in the output; one that is pushed is routed again like any
    other connection.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
    [pcb_router.py, test_pcb_router.py]
2026-09-25 Router: plane connectivity from the real In2 pieces; one GND return via per signal via
    - The +3V3 plane and the VDD_HP island on In2.Cu are cut by the thermal-
    via field and by In2 routing. The router assumed each plane is whole,
    so it never routed the VDD_HP connection KiCad reported, and a +3V3
    pad whose plane piece In2 routing had closed off counted as connected.
    Plane nets now join only through the piece of the plane they reach
    (a raster of the fill, cached until In2 changes), and +3V3 plane vias
    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
2026-09-25 Routed board and fabrication package (Gerbers, drills, IPC-356, pick-and-place)
    The board is routed by the project's own router (tools/pcb_router.py):
    every net connected, KiCad 10 DRC with 0 unconnected items and 0
    manufacturing/electrical errors (tools/check_drc_report --routed: PASS).
    The routed board is the placed board plus copper (preroute.py --verify:
    PASS) and the committed Gerbers are what it exports (export_fab --check:
    PASS).
    Not met yet, listed in hardware/output/fab/README.md: part of the
    differential pairs are not coupled over their whole length, and the
    10 mil intra-pair skew target is missed on several MIPI / USB / SD /
    Ethernet nets.
    - hardware/output/routed/: .kicad_pcb/.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
    [bom_pcbway.csv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]

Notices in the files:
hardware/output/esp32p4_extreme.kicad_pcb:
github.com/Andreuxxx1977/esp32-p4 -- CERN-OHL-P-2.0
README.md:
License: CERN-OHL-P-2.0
